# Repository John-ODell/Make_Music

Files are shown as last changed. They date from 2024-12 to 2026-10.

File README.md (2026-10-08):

Making Music with passive Buzzers by John O'Dell
--Update-- 12/4/2024 -> New Synth Update, Scroll Below for instructions. 

Arduino_Scale_Example

Items needed

    - Arduino uno (tested on r4)
    - Raspbery Pi Pico (Test on Pi Pico 2)
    - Passive buzzer module (two preffered and used in sketch)
    - Jumper Wire

Pin Outs

Buzzer 1
    - signal -> Pin 2
    - GND -> GND
    - VCC -> 3.3v

Buzzer 2

    - signal -> Pin 3
    - GND -> GND
    - VCC -> 3.3v

Download the Arduino IDE Platform https://www.arduino.cc/en/software

Open the sketch "arduino_scale_example"

    - Compile and write to your device
    - On Buzzer one C major scale with play with half notes in two onvtices
    - On Buzzer two C major scale will play with Whole notes in two octives

Python Example

Pin Outs

Buzzer 1
    - signal -> Pin 20
    - GND -> GND
    - VCC -> 3.3v

Buzzer 2

    - signal -> Pin 19
    - GND -> GND
    - VCC -> 3.3v

Download the Thonny IDE Platform https://thonny.org/
    
** Follow the Flash Instructions Below To install Micropython onto your Device **

Open the sketch "passive_buzzer_music_test"

    - Press the green arrow
    - On Buzzer one C major scale with play with half notes in two onvtices
    - On Buzzer two C major scale will play with Whole notes in two octives

TROUBLESHOOTING

    - Make sure that your wires are correct for sketch
    - You may get feedback from just signal wires, make sure vcc and ground are in
    - keep to 3.3v on the arduino
    - Some buzzer modules are not good enough quality
    - to increase or quite the noise, change the duty cycle
    - notation is based off 440A and modern tunings. 

** Flashing MicroPython **

    - Open Thonny
    - Navigate to the top left
     - click run
      - configure interpreter 
      - on the bottom right
        - install Micropython
            - Target Volume will be chosen
            - Micrpython Family (RP2 for Raspberry Pi/Your device Family)
            - Variant (Check the Manufacturer)
            - Version, Most recent
            - Install
    - Afer the flash is done exit out of the Interpreter Pages
    - Click on run again
        - Configuer Interpreter
        - "Which Kind of INterpreter should Thonny use"
            - Micropython for your model device (some models will be automatically dedectied)
        - "Port or WebREPL"
            - COMS(number)
            - This number may have changed from when you ran through this the first time.
            - Click Ok
    - On the Thonny home page, Click the Red stop Sign
    - In the Shell below, You will see your device.

---- Pi Pico Synth - 10 Key Bread Board Synth by John O'Dell ----
Updated 12/4/2024

Items needed

    - 10 Touch Input models (feel free to change the inputs, I found touch to be the best for input time, 10 inputs needed)
    - 2 Passive Buzzers (based on how loud you want your Synth to be)
    - Pi Pico 2 with Micropython
    - Thonny IDE
    - ~40 Jumper Wires
    - 2 Breadboards (Recommended for Button Placement but can be done with 1)

This Sketch requires your inputs to be accesseble at all times, please think about how you are wiring so there are not any false inputs.

Pin Outs 

    - All Modules will use a common 3.3v and GND
    - It is easiest to "pick a side" for each module
        - Touch inputs
            - VCC -> 3.3v
            - GND -> GND
            - S -> GPIO 16 - GPIO 22, GPIO 26-28 
                - 10 sequintial pins for easy orginization
        - Passive Buzzers
            - VCC -> 3.3v
            - GND -> GND
            - S -> GPIO 12 - GPIO 13
                - 2 sequintal pins for two buzzers, add more for more sound. I found two is good for personal playing.

Touch Button Example

This example is to make sure your inputs are working

    - open "touch_button.py" and press the green arrow
    - when you press a button in the serial monitor it will return a button has been pressed
    - Change the Pin number in the top the check if all your buttons are working

TROUBLESHOOTING

    - Make Sure you have not switched the VCC and the GND
    - The number is not the pin number but eh GPIO number, refer to the Raspberr Pi Pico pinout sheet

8 Key example

In this example We use 8 touch buttons and turn them into the "White keys" of a piano by assigning them each to a note of the C major scale.
We anchor this tuning based on A4 (fourth octive) at A 440hz. From this we can find the tuning of our different keys. We have a high sample rate for self regulation of Timing rather than a set BPM

    - Open "8_key.py" and press the green arrow
    - starting with the input assigned to GPIO 16, we play a major C scale.
    - In the serial monitor there will be a high refresh rate showing when a button is pressed along with the frequency associated with it

TROUBLESHOOTING

    - make sure you have VCC and GND correct
    - Make sure you are in the Correct GPIO pins
    - if wired in parrallel, there could be a power issue, wiring pin for pin I found has a better sound

--- Pi Pico Synth by John O'Dell ----

This is a mini Synth that has uses 10 touch inputs with passive buzzers to achieve two full ovtives of a piano/synth. 
8 Inputs are assigned the me C major scale, with one Input raising them a half step and another raising them an octive.
This is a fun exmperimental instrument that has a particular 8 bit sound to it.

    - Follow the main wiring diagram 
    - Open "mod_8_key.py" and press the green arrow
        - to play on boot, save the file to the Pi Pico device and name it "boot.py"
            - to get out of a boot cycle, refer to the  **Flashing MicroPython** Section
    
    - Feel Free to change the assigned tones to the keys to make a new set scale.
    - The modulating buttons can be changed as well in their current function, or a totally new one.
    
Practice Song:

    - (refer the the GPIO Pins)
        - |16 18 20|16 18 20|17 19 21|17 19 21|17 19 22|17 19 22|19 21 26|19 21 26|
    - (Refer to the Notes)
        -|C E G| C E G| D F A| D F A| D F B| D F B| E A C| E A C|

## PCB development

The first battery-powered Pico carrier is now an editable, routed KiCad project with removable Pico H sockets, ten touch controls, two buzzer module connectors and GPIO expansion. Electrical/board checks pass; exact-part fit, mechanical CAD and bench validation still hold fabrication. See [hardware/README.md](hardware/README.md) for the project and held review files.

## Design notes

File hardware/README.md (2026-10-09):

# Make Music PCB

The first-prototype project is an editable KiCad10 carrier with protected battery power, removable Pico H sockets, eight notes/two left-hand modifiers, two passive buzzer module connectors and exposed GPIO. The schematic has passed independent ERC/connectivity review. Capacitor/18650 PCB integration has passed all 166 live pad comparisons, with zero copper/layout violations and unrouted connections; four exact metadata warnings remain visible. See current PCB status for the scope and physical edge/fit findings. Exact-part fit and built-hardware tests remain pending; fabrication is held.

Open [kicad/make_music.kicad_pro](kicad/make_music.kicad_pro) in KiCad10. Keep the entire hardware directory so project-local symbols/footprints resolve. The two editable schematic sheets and routed PCB are sources; PDFs/SVGs are review aids.

- [Current PCB status and checks](kicad/PCB_STATUS.md)
- [Selected requirements and GPIO allocation](PCB_DESIGN_NOTES.md)
- [Native schematic and library instructions](kicad/README.md)
- [Held manufacturing/assembly review package](manufacturing/REVIEW_ONLY_DO_NOT_ORDER/README.md)
- [Actual-part measurements still needed](assembly/FIT_CHECKLIST.md)
- [Factory assembly and budget comparison](ASSEMBLY_BUDGET.md)
- [Quote-only request for five complete instruments](assembly/QUOTE_REQUEST.md)
- [Module cable specification](assembly/MODULE_HARNESSES.md)
- [Raised module fixture](mechanical/MODULE_FIXTURE.md) and [wired underside holder cassette](mechanical/WIRED_HOLDER_PROPOSAL.md)
- [Protected power circuit](power/branch-protection.md) and [staged validation procedure](power/prototype-validation.md)

The proposed carrier is330 ×121.5 mm with a removable externally charged protected **18650**. MPD BH-18650-W and its larger lowered cassette/47 mm supports are engineering proposals. Protected-cell fit, connector engagement, module support regions, final mechanical CAD, power/load/thermal behavior and fabricator/assembler acceptance remain required. Five complete instruments plus an optional additional bare keepsake are the selected factory scope. See the fit checklist for precise measurements; use the current held package for review; the old concept sketch is not a manufacturing drawing.

`../Pico_Synth/carrier_prototype.py` provides the carrier pin map, configurable touch polarity and active-low ST0238 idle behavior. It preserves the original firmware; seven host logic tests pass, but no assembled instrument has been tested. Both buzzers play the same pitch, modified by held left semitone/octave controls. Independent voices require a pin/firmware change.

Next: verify actual parts and paper fit, finalize the custom mechanical subassemblies, review the factory quote/assembly process, and bring up one prototype using the current-limited validation procedure. PCB fabrication alone does not supply modules, cables, mechanical assembly, Pico, battery or charger. The published$67.54 setup/stencil example is not a full instrument quote.

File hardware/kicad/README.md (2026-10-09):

# Editable Pico instrument carrier

Open `make_music.kicad_pro` in KiCad 10, then open the schematic. The project-local `MakeMusic.kicad_sym` library and `sym-lib-table` resolve all symbols. `fp-lib-table` registers socket, carrier and power libraries plus installed KiCad 10 `Connector_JST`, `Resistor_SMD`, `Capacitor_SMD` and `TestPoint` libraries. The schematic is the editable source of truth; do not regenerate it from the review PDF.

- `make_music.kicad_sch`: A3 root with two removable female sockets, ten touch/two buzzer cable headers, expansion, two reset pull-ups, twelve 100nF header bypass capacitors and C17/C18 10µF buzzer bulk capacitors.
- `battery_power.kicad_sch`: editable A3 child sheet with JST battery entry, upstream fuse, switch, TPS259474L protection and supporting passives/clamps; VSYS/GND connect through hierarchical ports.
- `make_music.kicad_pcb`: routed 48-part electrical carrier with 17 mounting holes, two ground pours and module/cassette references. C17/C18 and corrected 18650/H1 routing are integrated. Current checks and retained metadata warnings are in [PCB status](PCB_STATUS.md).
- `schematic-review.pdf`: readable two-page A3 schematic export, marked prototype review.
- `pico-socket-map.csv`: all 40 Pico physical pins mapped to local socket pins and carrier nets.
- `verify_connectivity.py`: checks every endpoint in a fresh XML netlist against the reviewed interface contract.
- `carrier-interfaces.md`: exact carrier parts, cable mapping, footprint evidence and placement/release gates.
- `power-integration.md`: native reference mapping, power parts, RPW/fuse/TVS geometry, validation and qualification gates.
- `../reviews/schematic.md`: verified facts, actual checks and unresolved design decisions.

J1 and J2 each use local pad numbers 1-20. J1 pin 1 is at the USB end; J2 pin 1 is at the opposite end. J2 pin 20 is beside USB. J1/J2 are assigned `MakeMusic:Samtec_SSQ-120-01-G-S_1x20_P2.54mm` as candidates. Place J1 pad 1 at USB and rotate J2 180 degrees relative to J1 so J2 pad 20 is at USB. This integration numbering supersedes the mechanical proposal's alternative right-row pad-1-at-USB convention; do not reverse the existing schematic nets to match that proposal.

J3-J14 carrier order is defined as 1=SIG, 2=3V3_OUT, 3=GND. Assigned Harwin headers are cable adapters; actual module pin order is mapped separately by label, and no module mounting geometry is claimed. J15 has the exact Harwin 16-way candidate and defined GPIO order. H1 is the underside JST PH battery harness, circuit1=BAT_PROT_PLUS/circuit2=GND; it does not put holder contacts or holes on the carrier. All **48 schematic physical components** have assigned footprints: **47 purchased parts** plus TP1's 2mm bare copper test pad. J1/J2 now store native SSQ-120-01-G-S MPN and Samtec datasheet fields; supplier BOMs need no socket-identity substitution. See [carrier interface contract](carrier-interfaces.md) for ST0238 cable permutation, reset bias, bulk-capacitor land evidence and local bypass placement. The selected inserted module is original non-wireless RP2040 Pico H SC0917 with fitted male headers; its electronics and the module drivers remain off-board/unmodeled. Cold-fit/engagement checks remain. The updated schematic passes native ERC with zero errors/warnings and the 166-endpoint contract; live PCB pad/identity checks now agree; four custom-field warnings remain reported.

Run from this directory (write generated logs/netlists outside the repository):

```sh
kicad-cli sch erc --severity-all --exit-code-violations --format json -o /tmp/make-music-erc.json make_music.kicad_sch
kicad-cli sch export netlist --format kicadxml -o /tmp/make-music-netlist.xml make_music.kicad_sch
python3 verify_connectivity.py /tmp/make-music-netlist.xml
kicad-cli sch export pdf -o schematic-review.pdf make_music.kicad_sch
```

The user permits firmware adaptation to confirmed touch polarity, including active-low. Confirm direct/momentary configuration and actual idle/touched levels first; the separate carrier_prototype.py firmware supports configurable active levels; no module polarity has been measured.

Revision-1 source path: protected-cell external + -> H1 circuit1 -> F1 -> BAT_FUSED_PLUS -> S1 common2; S1 throw3 -> BAT_SW_PLUS -> U2 IN5; U2 OUT6 -> VSYS/Pico physical39. S1 throw1 is NC (battery OFF). H1 circuit2 joins GND. Carrier series D1 is removed. D2 is a VSYS-to-GND shunt clamp; D3 is the bidirectional input TVS. TP1 only joins USB VBUS/Pico physical40. The Pico's internal USB diode/regulator remain off-board. See [native power integration](power-integration.md) for exact R3–R8/C13–C16 mapping and package evidence.

Battery OFF permits USB power. Remove the cell for external charging; no onboard charger is present. Source changes may reboot: stop playing and let the instrument restart before resuming. No polymer hold-up additions are fitted. Hardware UVLO/overload protection is implemented, while assembly-specific protection response, PCM thresholds, actual cell/holder fit and power/load/thermal validation remain open. Adopted limits are ≤0.70A battery branch, ≤350mA total3V3 including Pico, ≤250mA external3V3 and ≤100µF total VSYS capacitance including Pico. The user corrected the battery format to **18650** on 2026-10-09; the primary power/mechanical review owns updated exact cell/holder/charger choices. R1/R2 bias GP13/12 HIGH while pins are high impedance; firmware must idle HIGH and ST0238 startup/current/PWM still need testing. C1–C12 remain100nF at the carrier headers; native C5/C6 are retained and are unrelated to the removed power-document polymer C5/C6. C17/C18 add 10µF each at J13/J14 on 3V3_OUT; qualify effective capacitance and 3V3 startup/inrush.

The current held package includes C17/C18 and the corrected long18650
cassette/H1 move. Electrical integration and saved/refilled checks agree with
the source-bound exports. Native parity retains four metadata warnings; actual
pad nets, values and full footprint IDs agree. All drawing pages and actual
Gerber/drill whole/detail reviews are recorded. Current findings are in
PCB_STATUS.md. Complete exact-part fit, final mechanical CAD, bench/thermal
qualification and factory acceptance before manufacturing release. See
../assembly/FIT_CHECKLIST.md and ../manufacturing/README.md. The retired
export_review.py refuses to run; native exports use Konnect MCP.

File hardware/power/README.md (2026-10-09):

# Battery and USB power proposal

**2026-10-09 correction:** the user intended **long protected 18650**, superseding the 18350 cell/holder selection. The [current 18650 handoff](18650-handoff.md) recommends exact cell **Keeppower P1835J**, requiring a confirmed opposite-end **button-top** version for mechanical PR #30's **MPD BH-18650-W** holder. External-charger approval remains held pending current-lot voltage/current/termination and fit evidence. Included factory 24 AWG leads need measured insulation OD and qualified JST termination. Mechanical owns physical cassette fit/tolerances; PM completed H1 relocation and reconciled the [main procurement CSV](../assembly/instrument-parts.csv). The power CSV remains a supplementary candidate specification.

The [fuse/eFuse branch](branch-protection.md) is integrated in the routed carrier. The [current rear-edge evidence](../review/rear-edge-20261009/README.md) binds native commit `21b2108`; the [final held export review](../review/manufacturing-20261009/README.md) records package publication at `d987896`. The placement-guard defect from the historical `806457b` review was fixed in merged [PR #33](https://github.com/John-ODell/Make_Music/pull/33); current U2 rotation/C17 displacement controls reject before output creation. Four exact metadata warnings remain. The [bounded review](pr28-power-review.md) distinguishes completed document/export work from remaining physical gates. **No physical parts, fit measurements, bench validation or manufacturing release are available.**

## Recommendation

Implement **A: removable protected conventional 4.2 V-charge 18650 cell, externally charged, switched through the specified fuse/eFuse into Pico VSYS**. The eFuse supplies the battery with reverse-current blocking alongside the Pico's existing USB diode, preserving an unmodified removable original Pico H **SC0917**. Retain 0.70 A battery input, 350 mA total/250 mA external 3V3 and all existing protection values. **B: separate USB charge input + BQ24074 power path + protected cell** remains future research and is omitted from revision 1. The Pico USB port supplies programming/USB power and does not charge the battery.

Updated quote preference (2026-10-08): **five fully assembled instruments**, including populated SMT/THT carriers, harnesses and mechanical work, plus an **optional sixth bare carrier keepsake**. Fit measurements and supplier scope/pricing remain pending; the optional bare board does not replace any of the five assembled units. See the current 18650 handoff for exact remaining holds.

- [Factory assembly and staged prototype validation record](prototype-validation.md)
- [Current protected 18650 parts and integration handoff](18650-handoff.md)
- [Historical PCBWay audit of the 18350 checkpoint](pcbway-readiness.md)
- [Superseded 18350 cell/charger research](rev1-handoff.md)
- [Circuit connections and operating states](circuits.md)
- [Candidate BOM and verification evidence](BOM.md)
- [Historical battery budget comparison and switch research](candidate-comparison.md)
- [Current and runtime worksheet](current-budget.md)
- [Open decisions and integration checks](decisions.md)

## Verified Pico interface

Both non-wireless Pico and Pico 2 documentation specify these **physical header pins**, not GPIO numbers:

| Signal | Physical pin | Carrier use |
|---|---:|---|
| VBUS | 40 | USB voltage/sense only in A; do not join to VSYS or battery |
| VSYS | 39 | Isolated carrier power input, 1.8–5.5 V allowed |
| GND | 38 | Common circuit return; also use other ground pins as appropriate |
| 3V3_EN | 37 | Pull to GND to disable regulator, if full USB-connected instrument-off is required |
| 3V3(OUT) | 36 | Regulated module supply; Raspberry Pi recommends external load below 300 mA, dependent on processor load and VSYS |

USB supplies VSYS through the Pico's onboard D1 Schottky diode. The active U2 eFuse completes the battery OR path; its OUT is VSYS. The earlier carrier series-diode alternative used anode toward the battery and cathode toward VSYS. The higher voltage after its diode drop supplies the instrument; nominal USB wins over a cell. Diodes block ordinary reverse supply current, with finite leakage. The Pico USB port does not charge the cell. Do not connect battery to 3V3, GPIO, or VBUS.

The 1.8 V VSYS capability is a regulator specification, not permission to discharge a Li-ion cell that low. A protected cell and a chosen normal discharge endpoint remain necessary. The identified TTP223 touch IC supports 3.3 V; complete touch-module current/LED behavior and selected SunFounder ST0238 load current remain unverified. See [buzzer evidence](../components/BUZZER_MODULE.md). See the PM's [touch reference](../components/TOUCH_MODULE.md), incorporated from origin/master commit 6a61587.

Evidence: Raspberry Pi [Pico datasheet](https://datasheets.raspberrypi.com/pico/pico-datasheet.pdf), pin descriptions and §§4.4–4.6; [Pico 2 datasheet](https://datasheets.raspberrypi.com/pico/pico-2-datasheet.pdf), pin descriptions and §§5.4–5.6. Both PDFs were downloaded and their relevant sections read. Pico 2 Figures 8–10 were visually inspected. Wireless models are outside this verification.

## What this review establishes

Manufacturer documents support the conventional 1S circuit topology, power pin mapping and identified cell candidate. They do not establish current-lot charging compatibility, holder fit, real current draw, PCB thermal performance, USB compliance or a tested instrument. Source-bound review and the coherent held export package are complete for the stated checkpoint. PM retains release ownership; the physical/process checks in decisions.md and prototype-validation.md remain open, and any later CAD change requires matching evidence and exports.

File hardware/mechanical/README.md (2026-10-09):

# Mechanical fit review and dimensioned proposal

Reviewed 2026-10-08. **Preliminary candidate geometry; not a fabrication release.** Updated 2026-10-09: user corrected the cell to a protected removable **18650**, conventional 4.2 V-charge Li-ion with external charging; earlier 18350 selection is superseded. Owns mechanical documentation and local footprints only. Read together with `../PCB_DESIGN_NOTES.md`. No main schematic, copper routing, module pin order, power circuit, or firmware was changed.

The [2026-10-08 build-readiness audit](BUILD_READINESS.md) assesses the PM-reported J3/J4 move to mechanical y78, C1/C2 spacing, cable height/bends, intentional rear socket overhang, and which exact-part measurements remain necessary. It separates quotation, mechanical manufacture, first powered prototype and later characterization; it does not release the held manufacturing files. The [physical-fit checklist](PHYSICAL_FIT_CHECKLIST.md) covers the selected five fully assembled instruments plus optional sixth bare keepsake. The user can check overall paper fit with a tape; the assembler supplies priced metric part metrology, harness work and acceptance.

**Final review 2026-10-09:** [socket edge recommendation](SOCKET_EDGE_REVIEW.md) replaces the prior overhang acceptance proposal with a rear-only native y20->y18.5 extension, **330 x121.5 mm**, every native placement fixed. Existing service/fixture coordinates keep native offset (20,20), so the new rear is y=-1.5; the physical upper-left is native (20,18.5). [Datums](DATUMS.md) document the optional new-origin conversion without moving parts. [Parameterized cassette interface CAD](CASSETTE_INTERFACES.md) supplies independent nominal backplate/platform geometry; retention, exact fit and manufacturing release remain pending.

## Removable non-wireless Pico carrier

Verified against both user-supplied official local PDFs: original Pico release 21, chapter 2/Figure 3 (printed page 6), and Pico 2 release 5, chapter 3/Figure 3 (printed page 7), both built 2026-07-03. Their mechanical pages were rendered and visually inspected; both agree on the dimensions below. PM selected **Raspberry Pi Pico H SC0917**, the nonwireless RP2040 version with manufacturer-installed male headers, as the first-prototype candidate on 2026-10-08. The official original-Pico ordering table (local release21) identifies SC0917 as Pico H. Physical socket engagement and the assembled header height still require measurement:

| Feature | Drawing dimension, mm |
| --- | --- |
| Pico PCB | 21 wide x 51 long x 1 thick |
| Header rows, center to center | 17.78 |
| Pins per row / pitch / first-to-last span | 20 / 2.54 / 48.26 |
| Row center from side edge | 1.61 |
| Mounting holes | four, diameter 2.1 +/-0.05 |

Use two **Samtec SSQ-120-01-G-S** vertical 1x20 female sockets as the standard-force candidate. **SSQ-120-21-G-S** is the same series' low-insertion-force alternative, subject to configuration availability and a retention trial. Do not use the -03 tail by default: its 10 mm tail unnecessarily projects below the carrier.

Samtec series print revision BH, sheet 1, and catalog F-226 show single-row housing width 2.41 mm (reference), height 8.51 mm (reference), length `N*2.54+0.51` = **51.31 mm**, length tolerance +/-0.25 mm, 0.64 mm square tails, and style -01/-21 tail length 2.64 mm. Catalog insertion depth is **3.68 to 6.35 mm**. Recommended PCB layout revision A, sheet 1, specifies **1.02 mm holes and 1.52 mm pad diameter**, at 2.54 mm pitch. A local single-row footprint captures these dimensions. Body extends 1.525 mm past each end pad center; courtyard adds 0.5 mm, rounded outward. Pad 1 is square. Physical fit of the selected Pico H male headers remains unverified.

Assume a 1.6 mm carrier PCB: nominal unsoldered tail projection is 2.64-1.6 = **1.04 mm**, with solder fillet and tolerances additional. For an example 6.0 mm exposed male post, a 0.5 mm housing gap gives 5.5 mm engagement, inside the catalog range. This is a stack calculation, **not a measured Pico H stack height**. Confirm the supplied Pico/male header has the appropriate square mating post and measured engagement; it must neither bottom out nor float with too little contact overlap. Carrier-to-Pico underside height is 8.51 + socket-to-male-housing gap + male insulator thickness; top component height is additional. Keep the entire Pico underside clear of tall carrier components until that stack is measured.

### Placement and physical numbering

Proposal coordinates retain the legacy service origin native (20,20), viewed from the playing/top side; x right, y toward the front, in mm. Pico USB points toward the rear edge at y=0. Its PCB box is x=109.5..130.5, y=0..51. USB-end pad centers: left J1 pad 1 at (111.11,1.30), right J2 pad 20 at (128.89,1.30). The far-end centers are J1 pad 20 at (111.11,49.56), J2 pad 1 at (128.89,49.56). Rounding of drawing offsets gives y=49.56; use the verified 48.26 mm span, not an assumed symmetric end margin.

Canonical mapping follows the merged schematic's `../kicad/pico-socket-map.csv`: **J1 local n = Pico physical n; J2 local n = Pico physical n+20**. Viewed from the playing/top side with USB up, J1 pad 1 is nearest USB and J2 pad 20 is nearest USB. GPIO numbers are not physical pad numbers. Use the same candidate socket footprint twice: J1 at (111.11,1.30), rotation **0 degrees**; J2 at (128.89,49.56), rotation **180 degrees**, so its pads increase toward USB. Do not place J2 pad 1 at USB. This supersedes the initial mechanical-only reverse-numbering convention; the schematic is canonical and requires no renumbering.

| Socket pad | Pico physical pin / function | Position in top view |
| --- | --- | --- |
| J1.1 / J1.20 | 1 GP0 / 20 GP15 | USB end / far end |
| J2.1 / J2.20 | 21 GP16 / 40 VBUS | far end / USB end |
| J2.19 / J2.16 | 39 VSYS / 36 3V3(OUT) | one / four pitches from USB end |

`socket-placement.csv` records all 40 pad centers, canonical physical pins and carrier nets for integration. The right-footprint square pad-1 marker is at the far end. Check the rotation and complete net mapping in the PCB editor before routing; connecting J2.1 to VBUS would contradict the canonical schematic.

The socket housing starts about legacy y=-0.225. The proposed rear extension to legacy y=-1.5/native y18.5 gives 1.275 mm nominal housing support margin; actual tolerance/flash, finished edge and body seating require process acceptance. See SOCKET_EDGE_REVIEW.md; do not move the assembly to apply this correction. Reserve a **36 x 25 mm external USB cable approach** at x=102..138, y=-25..0 as an assumed cable-shell envelope; measure the actual plug. Keep BOOTSEL accessible through an open lid/service aperture; a provisional 12 x 12 mm access region around (116.5,14) must be adjusted to the selected Pico H's actual button. Leave at least 5 mm side access beyond the Pico and unrestricted upward removal space; trial removal without bending the carrier. USB overhang and plug clearance are separate from the 51 mm PCB dimension.

The reviewed rear courtyard at native y19.27 extends 0.73 mm beyond the old y20 edge and is 0.77 mm inside the proposed y18.5 edge. The fixed nearest socket pad at y21.30 has proposed 2.04 mm copper-to-edge and 2.29 mm finished-hole-to-edge; the 0.25 mm nominal annular ring is unchanged. Samtec supplies no carrier-edge support approval. The final review separates the resolved nominal geometry from actual Pico/cable/finished-part process acceptance; no native outline edit or physical fit pass is claimed by this helper.

## Underside protected 18650 holder

Select **MPD BH-18650-W** as the mechanical candidate. Its [manufacturer drawing revision G, 2024-08-21](https://www.batteryholders.com/uploads/parts/BH-18650-W/datasheets/BH-18650-W-datasheet.pdf) explicitly specifies protected 18650 use and factory 24 AWG leads. The visually reviewed holder body is **77.70 x 20.90 x 21.31 mm**, with general ±0.5 mm decimal tolerance; body planning maximum 78.20 x 21.40 x 21.81. It does not specify a maximum cell length/contact travel or holder ampacity. Exact protected cell and matched external charger selection belongs to the power owner; measure and cold-fit that actual pair, including comfortable removal, wrapper clearance and retention.

The [revised wired cassette](WIRED_HOLDER_PROPOSAL.md) is **112 x 36 x 44 mm**, x145..257/y12..48. The four existing carrier mounts stay at (150,17),(210,17),(150,43),(210,43); a lowered z16 holder platform separates the holder from bolt tips where their plan projections overlap. **Move H1 pad1 from mechanical(229,20) to (269,20), native (249,40) to(289,40)**, same side/rotation/nets; this is a PM proposal, not a helper native edit. New plug reservation x265..275/y15..27 is8 mm beyond the cassette. No Pico, power, GPIO, modifier, note or fixture-mount relocation is requested.

Support proposal is now **≥47 mm below carrier underside**, 3 mm nominal below 44 mm cassette. Final fitted height, lead bends, PH contact insulation compatibility, ribs/overhang strength, cassette door and loaded clearances need assembler metrology/toleranced CAD. All soldering, crimping and mechanical installation remain factory work for five complete instruments. User has tape/no parts; overall paper-fit and reach do not certify connector or cell fit.

Keystone **1044** is an alternative solder-lug 18650 holder whose [manufacturer family](https://beta.keyelco.com/category.cfm/18650-Lithium-Ion-Holders-and-Contacts/For-One-18650-Cell/p/418/id/1198/c_id/686) and catalog p29 describe protected-cell support and tool-free removal. Its catalog body is nominal 77.1 x 20.7 x 18.0; exact lug geometry and delivered-part fit were not verified here. Earlier 1095/1096/1095P/1101 and P1835C2 findings are **historical superseded 18350 research**, retained in [HOLDER_1095P.md](HOLDER_1095P.md). The anonymous 71.12 mm flat-top listing is not selected or substituted for a manufacturer-documented part.

## Arrangement proposal and preserved controls

`placement-proposal.svg` is drawn to a consistent mm coordinate system with dimensions; it is **a reservation plan, not module footprints or an approved board outline**. Candidate board size is **330 x 121.5 mm**, assumed pending actual module measurements and enclosure selection.

Eight front note centers at y=94: x=70,104,138,172,206,240,274,308, in ascending **C4,D4,E4,F4,G4,A4,B4,C5** order. **34 mm center pitch minus 24 mm actual reference body width gives 10 mm clear body-to-body gap**. Eight bodies and seven gaps span `8*24+7*10 = 262 mm`, x=58..320. Dashed 26 x 26 mm reservations add 1 mm on each side of each body, leaving 8 mm between reservations; they do not change the stated 10 mm body gap. Left-hand semitone and octave centers are (24,54) and (24,94), with the same 26 x 26 mm reservations. The actual octave-to-C4 body gap is 22 mm; vertical modifier body gap is 16 mm. Their GPIO baseline remains GP27/GP28; note baseline remains GP16..22/GP26. Increase board size/spacing if actual module body, headers, touch pad, solder tails or finger access exceed these reservations. No module connector pin order is assumed. PM supplied the [HiLetgo reference](http://www.hiletgo.com/ProductDetail/1915450.html), 24 x 24 x 7.2 mm and four M2 holes. These are PM/user-supplied dimensions; hole center spacing, installed header/tail height, and connector orientation/pitch remain unverified. Reservations now accommodate that reference; no module-specific footprint is created. The merged `hardware/components/TOUCH_MODULE.md` was read after fast-forwarding to origin/master 6a61587. The quoted 7.2 mm module height does not include an independently verified carrier mounting gap, pin tail or enclosure clearance; measure the complete assembled stack.

The user requested roughly half to one finger between keys. **10 mm is an initial measurable interpretation, not a verified finger-width or ergonomics claim. A full-size paper fit test is pending.** Print `paper-fit-template.svg` at 100% on A3 landscape or tiled pages (the 330 mm width exceeds Letter/A4 landscape), or draw the 330 x 121.5 mm outline at 1:1; check scale against its 100 mm reference, test the printed note positions and held left modifiers with the intended user's hands. The user has no actual modules; exact metric part measurements remain with the assembler. Check reach, accidental neighbor activation, gaps, mounting screws and plugged expansion wires. Record the result and revise pitch/board size before approving the outline. Eight separate 24 mm touch boards remain provisional until measured; a paper test does not verify capacitive behavior, which still needs a powered prototype.

PM's current carrier handoff places vertical **J15 1x16** at pad1 (50,12), 2.54 mm pitch; last pin y=50.1. Reserve access x=45..58,y=8..55.1, with plug/wire reach verified on the assembly. Expose all 14 unused GPIOs **GP0..GP11, GP14, GP15**, plus 3V3 and GND; the native schematic remains authoritative for pin order. Used pins/test points must not be advertised as free. The [raised module fixture](MODULE_FIXTURE.md) leaves Pico and J15 access open, preserves all ten touch centres, and proposes buzzer centres **(60,67.5)/(98,67.5)** with 32 x 14 bodies and 36 x 23 fixture/hardware envelopes. These body placements are independent of PM's wired buzzer headers (61,49)/(99,49). Current power/switch reservation is x=216..264,y=44..68. No module-specific connector or mounting-hole pattern is inferred. The fixture drawing and attachment CSV record nine independent carrier mounts, z24 spacers/z28 support plane, and factory assembly/fit requirements; module dimensions, bare edge lands, component/header clearances, sensing response and mechanical load remain actual-part gates.

## Assembly and release gates

PCBWay documents through-hole/manual assembly and a quotation form with top/bottom/both-side assembly. This demonstrates a service category, **not acceptance of these particular sockets/holders**. Ask for the selected MPN, bottom-side holder orientation, THT/manual/selective-solder method or SMT retention, sourcing, finished-hole tolerance, solder access and inspection in the assembly quotation. Supply both-side assembly drawings and battery polarity; bare PCB service does not install the holder. Assemble with no cell fitted. Solder sockets aligned using a nonpowered sacrificial mating jig, inspect all joints, then insert Pico; do not solder the Pico into its removable socket.

Before integrated assembly release: verify selected Pico H SC0917 and its actual male-header engagement; trial 40-pin insertion/removal and USB/BOOTSEL access; confirm current holder drawing revision, verify bottom-side flip/polarity mapping and selected-cell fit; measure all ten touch modules and both buzzer modules per instrument; confirm enclosure/door/support load path; integrate power isolation/protection; accept finished holes and edge margins; run integrated ERC/DRC/netlist agreement and inspect both sides. The independent carrier interfaces permit PCB review/quotation while fixture/cassette metrology remains pending. The checklist separates design/manufacturing inputs from acceptance tests that require the first assembled instrument. An unconnected reservation drawing cannot pass manufacturing validation.

## Source register and verification

Primary sources accessed 2026-10-07; copyrighted manufacturer drawings are linked rather than committed.

- [Original Pico datasheet](https://datasheets.raspberrypi.com/pico/pico-datasheet.pdf), chapter 2/Figure 3, and [Pico 2 datasheet](https://datasheets.raspberrypi.com/pico/pico-2-datasheet.pdf), chapter 3/Figure 3: local copies `/Users/johnodell/Desktop/pico_datasheets/RP-008307-DS-2-pico-datasheet.pdf` (release 21) and `/Users/johnodell/Desktop/pico_datasheets/RP-008299-DS-3-pico-2-datasheet.pdf` (release 5), both built 2026-07-03, consulted and mechanically consistent. PM selected Pico H SC0917 for the prototype; the original-Pico ordering table was checked. Wireless variants are not verified here.
- [Samtec exact SSQ-120-01-G-S candidate](https://www.samtec.com/products/ssq-120-01-g-s), [series print revision BH](https://suddendocs.samtec.com/prints/ssq-1xx-xx-xxx-x-xx-xxx-xx-x-mkt.pdf), [recommended PCB layout revision A](https://suddendocs.samtec.com/prints/ssq-1xx-xx-xx-x-xx-xxx-xx-xx.pdf), [catalog F-226](https://suddendocs.samtec.com/catalog_english/ssw_th.pdf): geometry and engagement checked; sourcing remains conditional.
- Historical superseded 18350 evidence: [Keystone primary catalog, printed page 28](https://beta.keyelco.com/userAssets/file/M70p23-33.pdf), [18350 family](https://www.keyelco.com/category.cfm/Holders-Plastic-PCB/18350-Lithium-Ion-Holders-and-Contacts/id/1200), [1095](https://www.keyelco.com/product.cfm/product_id/14033), [1096](https://www.keyelco.com/product.cfm/product_id/14034), [1095 individual PDF endpoint](https://www.keyelco.com/product-pdf.cfm?p=14033): direct download limitation resolved for visual inspection using manufacturer-authored drawing mirrors; [HOLDER_1095P.md](HOLDER_1095P.md) records the individual-source evidence and corrections.
- Historical superseded 18350 evidence: [Keeppower P1835C2 global page](https://www.keeppower.com/product/keeppower-18350-1200mah-protected-li-ion-rechargeable-battery-p1835c2/) and [China page](https://www.keeppower.com.cn/products_detail.php?id=566): conflicting 38.5/39.1 mm lengths recorded in the earlier review; not the current 18650 specification.
- [SunFounder ST0238 product](https://www.sunfounder.com/products/3-3-5v-passive-low-level-trigger-buzzer-alarm-sound-module): selected 32 x 14 mm body per merged component evidence; no header or mounting geometry assumed.
- [PCBWay through-hole assembly](https://www.pcbway.com/pcb_prototype/Through_Hole_Assembly.html), [assembly quotation options](https://www.pcbway.com/quotesmt.aspx): supplier support conditional on quote review.

Current 18650 validation is recorded in [WIRED_HOLDER_PROPOSAL.md](WIRED_HOLDER_PROPOSAL.md). The following is historical socket/18350 validation: local socket footprint exported successfully by KiCad 10 CLI and visually reviewed; pad count, numbering, pitch, span, drills, body and courtyard checked against cited dimensions. Follow-up proposal SVG XML parsed and visually reviewed; 34 mm pitch / 10 mm body gaps and all 40 rotated socket positions were checked against the merged schematic mapping. The erroneous 1095P candidate was withdrawn after source reinspection; the corrected five-hole interpretation and limits are recorded in the holder review. Both updated layout drawings retain nominal body reservations only. Paper fit test remains pending. The native board introduced in merged PR #15 is outside this helper's edit scope. No board DRC, electrical compatibility or physical fit test is claimed for these proposals.

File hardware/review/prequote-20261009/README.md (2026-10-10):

# Final team review for conditional PCBWay quotation

Reviewed October 9, 2026. Accepted for **quotation only**; fabrication remains
held. Native CAD is unchanged from21b2108d8f4a187647004e995a4c40368172f565.
The review began at merged07f0e03; subsequent edits change ordinary quote
documents and one supporting SVG label panel only.

- [Electrical review](electrical/REVIEW.md): fresh saved-file Konnect ERC0,
  layout/copper DRC0 and unconnected0. Exactly four previously reviewed
  custom-field parity warnings remain. No new sync/refill is claimed.
- [Mechanical review](mechanical/audit-summary.json) and
  [resolved label finding](mechanical/label-resolution.json): stale socket
  clearance prose corrected; all non-text geometry unchanged. The mechanical
  helper accepted the corrected readable panel for quote-only use.
- [Power/assembly review](power/REVIEW.md): conditional acceptance with current
  A/B/C scope and refreshed hashes. Its frozen audit describes the earlier
  committed packet; the current audit below verifies the revised packet.
- [Current packet audit](packet/packet-checks.json): all61 input hashes,
  43 support-input hashes,109 outputs,17 native hashes and128 package-local
  links pass. All47 purchased references/235 parts across five,30 SMT/17 THT,
  positions and part identities agree. The audit's historical SMT-only comment
  is superseded by the explicit all47-parts Option B in the current quote.

All17 preserved raw native exports are byte-identical. The coherent managed
packet is in [REVIEW_ONLY_DO_NOT_ORDER](../../manufacturing/REVIEW_ONLY_DO_NOT_ORDER/README.md).
Exact-part measurements, qualified cell/charger pairing, final toleranced
mechanics, factory process/orientation acceptance and first-article/all-five
tests remain production gates. Supplier contact/upload is separately authorized
by the owner for conditional quotation, with no purchase or production release.

The message-center attachment limit requires two ZIPs. Extract both into one
folder; together they contain precisely the110 packet files, without omissions
or changed payloads. Archive hashes and transmission status are recorded in the
[quote status](../../assembly/PCBWAY_QUOTE_STATUS.md).

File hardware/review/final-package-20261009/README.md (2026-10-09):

# Final held package review

The independent `before-corrections-REVIEW.md` audited frozen package commit
d987896 and found three presentation issues: grouped functional labels, copied
relative document links and a prose claim of zero native parity findings.
Its JSON/text companions record that earlier snapshot, not the corrected output.

Root corrected the descriptions by including Value in BOM grouping; bundled
43 support documents/assets and rebased package-local links; retained native
schematic parity4 and separately reported electrical discrepancy0. No native
CAD, Gerber/drill geometry, placement or drawing payload changed.

`corrected-package-checks.json` records the new package's checks:61 durable
input hashes,43 support-input hashes,109 output hashes,128 valid package-local
document links,47 purchased references/235 carrier parts for five instruments,
31 grouped rows and17 unchanged raw export artifacts. The excluded eighteenth
raw file is the generic BOM, intentionally replaced by exact sourcing tables.
All15 placement guard tests pass. A bounded independent follow-up by the
schematic helper (chat01a11931-3d20-7733-8e7e-296b88ba9abd) accepted all three
corrections:31 groups/47 unique references/235 parts,128 existing package-local
links, parity4 versus electrical discrepancy0,17 unchanged native source hashes
and17 unchanged raw manufacturing artifacts. It reported no actionable finding
within that scope and kept every fabrication-release flag false. The helper
performed no CAD/export/repository writes or supplier interaction.

This review permits integration as a held project. It does not qualify actual
part fit, final toleranced mechanical manufacture, cell/charger matching,
factory process acceptance or first-article/all-five powered tests. No price,
supplier contact, upload, order or fabrication release has occurred.

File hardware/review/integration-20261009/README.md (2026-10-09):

# Electrical integration evidence — review hold

Captured 2026-10-09 through Konnect 0.13.0 / KiCad 10.0.6. Native source hashes
in source-checkpoint.json bind this saved-board snapshot. Recreate evidence
after CAD/library changes; do not reuse a stale passing summary.

Run from repository root:

    python3 hardware/kicad/verify_connectivity.py hardware/review/integration-20261009/netlist.xml
    python3 hardware/kicad/verify_board.py hardware/review/integration-20261009

The first checks the independently reviewed circuit/parts contract. The second
compares the fresh native XML with all live IPC pad nets, values and footprint
IDs and a guarded identity-sync noop. It checks source hashes and complete
saved/refilled all-severity ERC/DRC evidence. No pcbnew/SWIG is used.

Observed: 48 electrical parts, 17 mounts, 166 endpoints, 405 trace segments;
ERC 0, copper/layout DRC 0, unconnected 0. Overall DRC remains four warnings:
C17/C18 missing Header and J1/J2 missing MPN in board custom fields. Their
exact references/UUIDs/descriptions are reviewed only for electrical integration.
Native XML holds the correct Header and MPN values; no field is substituted or
removed to silence DRC. Konnect's current sync omits custom field copying.

placement-score-mcp.json reports socket courtyard edge overhang of 0.73 mm.
This remains a physical rear-edge/lip acceptance requirement; no placement
score pass or actual component fit is claimed. Cable connectors are intentionally
internal; aggregate heuristics do not supersede direct circuit/layout checks.

Manufacturing, actual module/cell/holder fit, socket engagement, final mechanical
CAD, supplier process acceptance and current-limited bench tests remain held.
These are design review files, not files to upload or order.

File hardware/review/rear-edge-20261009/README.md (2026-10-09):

# Rear-edge revision — source-bound review hold

Captured 2026-10-09 through Konnect 0.13.0 / KiCad 10.0.6. The source
checkpoint binds the saved final board and local libraries. Earlier
integration-20261009 evidence is historical for checkpoint806457b.

Final native outline is (20,18.5)..(350,140), 330 ×121.5 mm. The service datum
remains native(20,20); mechanical rear y=-1.5. Four exact Edge.Cuts segments
were read back. Nominal socket body rear margin is1.275 mm; courtyard margin
0.77 mm. Actual Pico/socket engagement and handling are unverified.

The first y19 trial produced a silk_edge_clearance warning on J1's pin-1
marker (UUID86a40154-3d14-4646-a9e2-c013985edee5). The retained intermediate
DRC evidence records that finding; the final y18.5 check clears it.

All65 footprint placements/rotations/values/full IDs and405 trace geometries
by UUID remain unchanged from806457b. After editor reload, C17/C18 inactive
chamfer defaults and zero-size SMT drill metadata became explicit; operative
land positions, dimensions, nets and drill size remain unchanged. No full
pad-payload bit-identity is claimed. Mutation/readback MCP records are retained.

Fresh ERC0; saved/refilled all-severity DRC0 copper/layout,0 unconnected and
FOUR metadata warnings: C17/C18 missing Header and J1/J2 missing MPN board
custom fields. No rule or result was suppressed. Native fields are intact.
All166 live IPC pad nets,48 values/full footprint IDs agree with fresh XML;
guarded identity preview is noop. Placement score has zero hard failures;
internal-header edge heuristics do not establish physical defects.

Run from repository root:

    python3 hardware/kicad/verify_connectivity.py hardware/review/rear-edge-20261009/netlist.xml
    python3 hardware/kicad/verify_board.py hardware/review/rear-edge-20261009

Manufacturing, actual module/cell/holder/socket fit, fixture/cassette CAD,
cell/charger matching, assembler processes and current-limited bench tests
remain held. These files do not grant fabrication release.

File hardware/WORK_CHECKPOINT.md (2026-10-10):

# Make Music working checkpoint

## Current checkpoint — quotation sent

October9,2026,8:40:22 p.m. America/Chicago. Root branch
`codex/pcbway-quote-receipt-20261009` starts at PR37 merge
bc986a28121235c059e4859eb6203bb539a0c00a. PR37 integrated quote-packet commit
0d6191a0e0217e7140bbceed22aa4e59db78747e. All17 native hashes/raw exports remain
unchanged. Final team review and hashes are complete; no independent CAD work
remains before external engineering/measurement inputs.

One1759-character conditional RFQ was sent to assigned representative Cici and
verified in PCBWay Message History. Email reply selected. Actual quote pending.
No attachment upload, cart entry/order number, purchase or production release.
The RFQ supplies exact0d6191a GitHub packet/download links, avoiding the browser
file-permission blocker. No Chrome settings change is needed. Do not resend a
duplicate RFQ or treat the calculator's partial137.08USD as an instrument price.
Exact scope/receipt/archive hashes: `assembly/PCBWAY_QUOTE_STATUS.md`.
Local sent proof/text: `output/pcbway-quote-20261009/sent-rfq-confirmation.jpg`
and `sent-rfq.txt`. Keep private account/session/contact data out of GitHub.

External requirements remain exact-part metrology, qualified cell/charger pair,
final toleranced fixtures/cassette, factory process/orientation acceptance,
first-article/all-five tests and separate owner production approval. Five complete
instruments preferred; A/B alternatives/optional sixth bare separately.

All helpers idle. KiCad closed. PCBWay message tab1631995892 is the deliverable;
intermediate quote tab1631995889 closed. Preserve unrelated MOV/history. The app
confirmed that the previous continuation automation no longer exists; its pause
request could not apply. No schedule was recreated. No automatic supplier
follow-up or new design work without actionable inputs. Five-hour reset1791607325;
last usage75% used/25% remaining, weekly97% used, no credits consumed.

## Historical prepared quote checkpoint

October9,2026. Root branch `codex/pcbway-conditional-quote-20261009`, based on
07f0e03b4d69f809a0e0871b89afc9e052754bba. PR36 merged that previous checkpoint.
Native CAD remains21b2108. The owner now explicitly authorizes PCBWay
quote-only uploads/contact after final team review; previous no-upload/no-contact
language below is historical. No purchase or production release is authorized.

Electrical, mechanical and power helpers completed the requested last review.
Fresh saved-file Konnect ERC0/layout DRC0/unconnected0; exactly4 known metadata
warnings retained. Only actionable finding was stale socket-clearance prose in
one ordinary SVG. Root corrected labels; mechanical helper accepted the readable
panel with all non-text geometry unchanged. Durable evidence:
`review/prequote-20261009/`. All helpers are idle. No native edits this turn.

Managed package refreshed coherently:61 input/43 support hashes,109 outputs,
17 native hashes,128 package-local links and47 placements/235 five-unit parts
pass. All17 raw native exports unchanged. Alternative quote scopes now explicitly
cover A5 bare, B5 with all47 parts supplied/soldered, C5 complete instruments,
optional sixth bare. No fifteen-board order. Fit/charger/mechanical/process/test
holds remain exactly as described below and in the current quote request.

The PCBWay calculator returned an incomplete service estimate; Save to Cart
did not create an entry. No cart-based quote submission is claimed. A1950-char
message to assigned representative Cici is prepared, email reply selected.
Two exact ZIPs under1MB each are prepared and byte-verified; filenames/hashes and
scope are in `assembly/PCBWAY_QUOTE_STATUS.md`. Neither attached nor sent yet:
Chrome extension requires “Allow access to file URLs.” User has been asked to
enable it. Do not repeat Save to Cart or send a duplicate RFQ. On permission
completion, upload both ZIPs to the prepared message, verify successful filenames,
send once, and verify an actual sent-message confirmation. Keep receipts local,
account/email/session identifiers out of this public repository.

Latest five-hour usage60% used/40% remaining; weekly94% used. Reset1791607325.
No reset credits consumed. Automation view was requested by its known ID;
its prior local TOML is currently absent, so do not claim a verified local schedule
without checking the app. Pause the existing continuation after confirmed quote
submission; no repeated supplier follow-up is authorized automatically.

KiCad is closed. Preserve unrelated MOV/history. Stable bundled Python remains
the selected runtime. Chrome message tab1631995892; quote tab1631995889.
CUA alert/file picker in background needs foreground activation via native Chrome
when CDP focus times out. Browser file upload requires explicit extension setting;
do not bypass permissions. The former12MB failed call did not execute and was
recovered without deleting project/browser state.

## Historical completed-design checkpoint

Updated 2026-10-09 after final held-package integration.
Root branch: codex/pcbway-prototype-package. Final package commit 2305833d4127fe2808075e858281b6a5a89fc47b merged through PR28 as 4fcd2ca516da457d9ea7e52da39c101ddac27d68 on master; local root fast-forwarded to that merge. Prior af535ce9a10861c251338a6552fdcb82a1200956 is the reviewed PR35 power-document merge.
PR34 merged484b73e on master and was integrated by0fc598b; PR31/32/33 were already merged.
Native CAD remains21b2108d8f4a187647004e995a4c40368172f565. Old package d987896 is superseded by the corrected package accompanying this checkpoint.

PR28:https://github.com/John-ODell/Make_Music/pull/28
Final independent review accepted integration **as a held review project**; PR28 is merged. A later continuation must fetch and verify actual PR/master status rather than repeat completed work. This post-integration checkpoint changes no manufacturing inputs or outputs.

## Completed independent work

Editable native KiCad carrier:330x121.5 mm, outline native(20,18.5)..(350,140), service datum(20,20) retained.65 footprints/405 traces/33vias;48 electrical parts/166 endpoints;38 connected nets and6 NC nets.
Saved/refilled all-severity ERC0, copper/layout DRC0, unconnected0. Native parity is4 reviewed custom-field metadata warnings(C17/C18 Header,J1/J2 MPN); live pad nets, values and full footprint identities have0 discrepancies. Identity synchronization is a no-op. No rules/results suppressed.
Current evidence:review/rear-edge-20261009; older integration evidence is historical.

Current manufacturing/REVIEW_ONLY_DO_NOT_ORDER contains109 hashed outputs plus manifest.61 durable input hashes and43 support-input hashes pass;128 package-local links resolve;47 purchased carrier references,30 top SMT/17 THT,31 functional BOM groups,235 carrier parts across five instruments.
Quote draft/support documents/assets/nominal DXFs/SVGs/paper-fit PDF/provisional firmware are bundled.17 raw export artifacts and17 native hashes are unchanged after ordinary presentation corrections.
All15 placement guard tests pass; wrong nets/new warnings/stale sources,reversed U2 and displaced C17 reject before output. Final audit/follow-up:review/final-package-20261009. No supplier contact or upload.

Actual final Gerber/drill whole registration, enlarged front copper/mask/paste/legend/polarity, all5 native PDF pages and both revised actual-size paper-fit pages were inspected. Placement/aperture/drill inventories agree:97 component PTH+33via hits and17 NPTH3.2mm. Native drawing payloads unchanged by this refresh. See review/manufacturing-20261009. IPC2581 is supplemental; unavailable IPC-D356 is recorded.

## Scope and exact external requirements

Five complete factory-built instruments plus optional sixth bare keepsake: original Pico H SC0917 in female sockets,8 notes+2 left modifiers,2 ST0238,exposed GPIO,protected removable LONG18650/external charging. Screen/keypad/percussion/other Pico variants deferred.
Factory scope includes soldering,crimping,mechanical work,programming,first-article/all-five tests.

1. Exact touch/ST0238 dimensions,header order,thickness,bare support lands,component heights and dressed harnesses; Pico/socket engagement,removal,USB/BOOTSEL access. User has no parts/precision tools; quote assembler metrology. Paper comfort test does not prove part fit.
2. Exact opposite-end-terminal protected P1835J/BH18650W cold fit/retention/contact/lead capability(.70A normal,>=1.2A continuous),AWG24 TR64 OD.8..1.5,qualified JST crimp/tool/strip/polarity/strain relief. Cell/charger pairing held: published L1 upper4.242V versus unqualified P1835J4.20Vmax; documentary voltage/current/termination/temp/bay-fit acceptance needed. One shared charger/input set is only a quote assumption.
3. Final measured/toleranced fixture/cassette/door/feet CAD. Nominal cassette112x36x44,z16 platform,>=47supports,>=2mm actual loaded clearance; keep playing load off cell/holder. Partial underside rule area is not a full enlarged-cassette keepout. Nominal socket body/yard rear margins1.275/.77mm are not measured acceptance.
4. Factory acceptance of U2 mask.10/stencil.100,nominal socket ring.25 versus normal.254,C17/C18 TDK0805 lands,panel rails/fiducials/depanel/THT sequence,both-side access,orientation/polarity preview and scope/itemized price.
5. Qualified first article within the five, then acceptance records for all five. Battery and USB branches need separate power/isolation/inrush/thermal/fault/UVLO tests; effective capacitance,touch polarity/momentary behavior,reset silence,buzzers,current/runtime remain unmeasured.

assembly/QUOTE_REQUEST.md and the package copy are concrete for owner review. Earlier$67.54 was a setup/stencil example, not the project total. No accepted price,physical fit,tested hardware,fabrication release,purchase or upload exists. Independent design work is complete; external gates are next.

## Helpers, usage and automation

Schematic01a11931-3d20-7733-8e7e-296b88ba9abd:final review/bounded follow-up complete,accepted held integration,idle.
Mechanical01a11931-eed2-7820-85eb-496cfc97903b:PR34/final read-only review complete,idle; root corrected stale paper/parity prose.
Power01a11931-cb05-7f20-8e09-075ef0c4c9c1:PR35 reviewed/merged af535ce,complete,idle. Do not restart helpers without actionable inputs.

Latest five-hour check31% used/69% remaining; weekly90% used. Actual five-hour resetsAt1791607325. No reset credits consumed. Same heartbeat resume-make-music-pcb-at-1-am is now PAUSED after verified final integration because only external gates remain. No automatic design work should resume without actionable new inputs or authorization for quote submission.
On future authorized continuation verify actual usage; at<=5% five-hour remaining perform bounded save/checkpoint/push/helper stop/rearm only.

## Tooling and preservation

All native CAD/config/library mutations use Konnect MCP; root sole owner. No pcbnew/SWIG or protected text edits. KiCad/Viewer closed; no CAD mutation in final presentation refresh.
Preserve unrelated ScreenRecording_05-01-2026 09-25-05_1.mov and hardware/kicad/.history.
Stable Python:/Users/johnodell/.cache/codex-runtimes/codex-primary-runtime/dependencies/python/bin/python3.
Raw:/tmp/make-music-pcbway/raw-held-rear-edge-20261009.
Corrected stage:/tmp/make-music-pcbway/final-quote-review-20261009.
Prior package backup:/tmp/make-music-pcbway/previous-d987896-package-20261009.
Before future CUA work restore documentation; getApp after quit reopens apps.

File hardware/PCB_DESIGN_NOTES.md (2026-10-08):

# Make Music — first-prototype design requirements

Updated 2026-10-08. The native two-sheet schematic and routed carrier pass ERC/DRC/parity. Fabrication remains on hold for exact-part fit, final mechanical CAD, bench validation and factory process acceptance. The original firmware is preserved; carrier_prototype.py is a separate tested logic implementation. See kicad/PCB_STATUS.md for actual checks and assembly/FIT_CHECKLIST.md for precise remaining measurements.

## Working configuration

- Two-layer carrier board with a removable original non-wireless RP2040 Pico H SC0917 (selected prototype candidate), plugged into two 1x20 female socket headers at 2.54 mm pitch. The sockets are soldered to the carrier PCB; the Pico has matching male header pins and can be inserted or removed without soldering. Use a Pico supplied with male headers, or fit male headers once to a bare Pico. Confirm socket row spacing, height, pin engagement and USB/BOOTSEL clearance against the selected Pico mechanical drawing before finalizing the footprint. Removal/insertion is done with power disconnected.
- Eight note touch controls and two left-hand modifier touch controls. User permits firmware changes, including adapting input polarity after actual modules are checked. Retain original behavior as the provisional baseline; reprogramming is available for later changes.
- Two SunFounder ST0238 passive low-level-trigger buzzer modules selected by the user for the first prototype. Manufacturer PCB outline: 32 x 14 mm each; see [buzzer module evidence](components/BUZZER_MODULE.md). The first prototype preserves both buzzers at the same pitch; the held left modifiers add a semitone/octave. Independent voices are a future firmware/pin allocation change.
- First revision: removable protected 18350 Li-ion cell, charged in an external charger. User selected this simpler battery architecture on 2026-10-07. Exact cell, matching underside holder and charger remain to be verified; no onboard charger in this revision.
- Power switch and exposed GPIO expansion headers.
- Separate touch and buzzer modules retained for the first revision. The user supplied a HiLetgo TTP223-BA6 touch reference; see [touch module evidence](components/TOUCH_MODULE.md). Actual header orientation, mounting geometry and output configuration remain unverified. Buzzer model is selected; its connector and mounting geometry still need verification.

## Carrier GPIO allocation (preserved baseline)

| Function | GPIO |
|---|---|
| C4 | GP16 |
| D4 | GP17 |
| E4 | GP18 |
| F4 | GP19 |
| G4 | GP20 |
| A4 | GP21 |
| B4 | GP22 |
| C5 | GP26 |
| Semitone up | GP27 |
| Octave up | GP28 |
| Buzzer outputs, same pitch | GP12, GP13 |
| Free expansion | GP0–GP11, GP14, GP15 |

GPIO numbers are not physical header pin numbers. GP12/GP13 share a PWM frequency; independently pitched buzzers require a different allocation (for example GP12/GP14) and a firmware change.

Expose unused GPIOs with labeled 2.54 mm headers, 3V3 and GND. GP0/GP1 can be reserved as an I2C expansion pair. Used signals may have labeled test points, but are shared with onboard circuitry and are not free GPIOs. J15 has GP0–GP11,GP14,GP15,3V3,GND in that order. Its physical pin1 is GP0. No I2C pull-ups are fitted; add compatible bus hardware for a later peripheral.

## Power architecture

Protected removable cell -> H1 -> upstream F1 -> S1 -> reverse-blocking TPS259474L U2 -> Pico VSYS. D2 is a VSYS shunt clamp, D3 a bidirectional input TVS; no carrier series diode. See power/branch-protection.md and kicad/power-integration.md for exact parts/pins/limits.
Pico 3V3(OUT) -> touch modules and compatible buzzer modules, subject to total current budget.

A conventional 3.7 V nominal cell reaches 4.2 V when fully charged. Do not connect raw battery voltage to 3V3 or GPIO. The Pico regulator supplies the regulated 3.3 V rail. USB/battery isolation must prevent USB from feeding the battery through VSYS.

If USB charging is requested, use a single-cell charger with appropriate power-path management, protection, and charge current matched to the selected battery. A Pico USB port does not charge a cell by itself. If removable external charging is selected, retain source isolation for safe USB programming with the battery installed.

Cell/holder dimensions, connector polarity, protection, regulator load budget, and charging method must be confirmed before selecting footprints. An 18350 holder must fit the actual cell, including any extra length from protection circuitry.

Battery runtime requires a measurement of average battery current; do not assume runtime from voltage alone.

## Placement concept

- Front: eight ascending note modules in a row. User requests approximately half-to-one finger of clear space between keys. Start with a proposed 10 mm clear gap between 24 mm module bodies (34 mm center pitch), then validate with a full-size paper fit test. Roughly 330 x 120 mm is a working reservation, not an approved outline.
- Left side: semitone and octave modifiers, positioned for the left hand while the right hand plays notes.
- Rear: USB-accessible Pico, buzzer modules, expansion headers and power switch.
- Battery: wired Keystone1101 solder-lug holder in a separate insulating underside cassette, connected by H1 JST PH. The cassette has independent carrier mounts; no holder-specific holes on this PCB. Protected P1835C2/1101 fit and contact ampacity remain unverified. Proposed >=35 mm underside supports keep playing force off the cell/cassette.
- Seventeen3.2 mm NPTH carrier holes: four corners, four cassette mounts, nine raised module-fixture mounts. These independent interfaces avoid undocumented module/holder hole positions. The raised acetal fixture uses proposed24 mm spacers, a28 mm support plane and24 measured-thickness edge keepers; final fit/CAD/tolerances remain pending.

The accompanying SVG is an arrangement sketch, not a scaled PCB drawing or a copper layout.

## Needed before fabrication release

1. Actual Pico H/socket engagement and USB/BOOTSEL/removal fit; actual touch/buzzer headers, heights and clear support lands.
2. Exact protected P1835C2/1101 fit, contact ampacity and matched external charger qualification.
3. Final paper fit/board size and measured fixture/cassette/feet CAD/tolerances. The proposed330 ×120 mm board is routed but its human/physical fit is untested.
4. Staged source-isolation, low-voltage/fault/current/thermal and functional validation, followed by factory process/quote acceptance. No total assembly quote exists.

These are recorded in assembly/FIT_CHECKLIST.md and power/prototype-validation.md. PM may continue independent layout/review work while actual-part measurements are pending.

## References

- https://datasheets.raspberrypi.com/pico/pico-datasheet.pdf — selected original Pico H, power/pinout/source isolation and mechanical data.
- https://learn.adafruit.com/li-ion-and-lipoly-batteries/voltages — conventional Li-ion cell voltage behavior.

## Manufacturing and assembly

Bare PCB fabrication supplies the board without components. A separate PCB assembly order can include a back-mounted battery holder if the chosen service accepts that part, bottom-side placement, and its through-hole or surface-mount mounting method. Include the exact holder part number in the BOM and clearly specify its side and orientation in assembly documentation. Confirm part sourcing and assembly support before ordering. The battery cell is a separate item unless explicitly included by the supplier.

PCBWay documents both through-hole assembly and top/bottom/both-side assembly options:
- https://www.pcbway.com/pcb_prototype/Through_Hole_Assembly.html
- https://www.pcbway.com/quotesmt.aspx

## Local Pico references

User supplied official datasheets in `/Users/johnodell/Desktop/pico_datasheets/`: original Pico release 21 and Pico 2 release 5, both build date 03/07/2026. The Pico 2 mechanical Figure 3 was rendered and visually checked against socket geometry. PDFs remain outside the repository; manufacturer source URLs above are the portable references. The PM selected original Pico H SC0917 using the original datasheet ordering table. Pico2 is not the fitted prototype candidate; original Pico geometry was checked separately during carrier integration.

## Assembly preference

Prioritize a quote for a factory-populated carrier, including sockets, headers, power components, and battery holder where accepted. Separately quote the named touch/buzzer modules as supplied/sourced subassemblies. Keep Pico insertion and protected 18350 fitting as user steps. See [assembly and budget comparison](ASSEMBLY_BUDGET.md). Build quantity remains pending user input.

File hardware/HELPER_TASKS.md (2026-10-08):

# Helper sessions

All helpers read `hardware/AGENTS.md` and `hardware/PCB_DESIGN_NOTES.md`. Use the assigned worktree and branch. Check scope against the current primary-chat decisions. Do not route a production board or finalize unidentified module footprints.

## 1. Schematic — codex/pcb-schematic

Own `hardware/kicad/` and `hardware/reviews/schematic.md`.

Create an editable KiCad 10 carrier schematic/project for the documented provisional GPIO allocation. Verify Pico physical pin mapping from Raspberry Pi documentation and represent the two removable 1x20 female sockets accurately. Include ten 3-pin touch-module interfaces, two buzzer-module interfaces, and labeled unused GPIO/3V3/GND expansion. Module connector ordering is unconfirmed: clearly mark provisional choices and leave module-specific footprints unassigned until identified. Keep power as clearly labeled interface points for the separate power review; never imply a raw battery-to-3V3 connection. Use local libraries as needed. Export a readable schematic review, run ERC, and document actual findings and unresolved power/module issues. Do not treat passing ERC as proof of component compatibility. Commit, push, open a focused PR, attach it to the helper chat and leave it for primary integration.

## 2. Power — codex/pcb-power

Own `hardware/power/`.

Research and propose battery/USB power for a socketed Pico instrument: protected single-cell conventional Li-ion/LiPo, power switch, source isolation and regulated module power. Compare removable externally charged 18350 versus onboard USB charging with proper power-path management. Verify against primary datasheets. Provide candidate parts with exact MPNs, circuit drawings or editable KiCad sheet where justified, BOM, current-budget worksheet and open decisions. Charging current and physical battery choice must remain conditional until the actual cell is selected. Verify the Pico USB/VSYS interaction and behavior with battery present. Do not edit the main KiCad project. Commit, push, open and attach a focused PR; leave it for primary integration.

## 3. Mechanical and footprints — codex/pcb-mechanical

Own `hardware/mechanical/` and `hardware/libraries/`.

Verify the removable Pico female-socket geometry using official mechanical drawings. Specify exact candidate sockets and inspect available KiCad footprints; create project-local footprints only when needed and include dimensional evidence. Investigate underside PCB-mounted 18350 holder options, protected-cell fit, standoffs, enclosure clearance, and supplier assembly support. Keep all unidentified touch/buzzer module geometry provisional. Preserve eight ascending notes across the front and semitone/octave controls on the left. Provide a dimensioned proposal with explicit assumptions, source links, and fabrication/assembly considerations. No copper routing or edits to the main schematic. Commit, push, open and attach a focused PR; leave it for primary integration.

## Primary integration

Resolve parts and behavior with the user, review helper results, combine the selected power design and verified footprints with the schematic, then commission routing. Verify every used GPIO and power net, current budgets, connector polarity and all mechanical clearances before manufacturing exports. Keep PR descriptions accurate about provisional versus verified work.

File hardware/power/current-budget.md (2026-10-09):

# Current-budget worksheet

Active prototype constraints: **0.70 A normal battery branch; 350 mA total 3V3 including Pico; 250 mA external ceiling; 100 µF total VSYS capacitance.** These are design limits from [branch-protection.md](branch-protection.md), not measured consumption. The active eFuse path replaces the carrier series diode.

**2026-10-09 cell correction:** use the protected **18650 P1835J opposite-end button-top candidate**, mechanical PR #30's **MPD BH-18650-W**, and unresolved lot/charger/holder conditions in [18650-handoff.md](18650-handoff.md). Conventional 1S voltage is unchanged, so all current/protection limits and the 515 mA sizing calculation below remain. Larger capacity does not permit more carrier load. The published 3350 mAh minimum is not usable capacity at our loaded UVLO, and no runtime is inferred from it. MPD's factory leads are 150±5 mm each; [prototype-validation.md](prototype-validation.md#analysis-completed-without-physical-parts) retains a qualified nominal/tolerance wire-loss illustration. Measure the actual conductor/contact/termination path and recalculate if routing changes it.

No component current has been measured. Blank values are **unknown**, not zero. Populate from the actual selected hardware at 3V3 with both buzzers operating, all touch LEDs active, expansion load connected and the intended firmware/clock. Record steady average, startup and coincident peak separately.

| 3V3 load | Quantity | Per-unit average mA | Per-unit peak mA | Evidence / measurement |
|---|---:|---|---|---|
| Pico processor + onboard loads | 1 | TBD | TBD | Selected Pico, clock, code; internal part of regulator load |
| Note touch modules | 8 | TBD | TBD | Exact module + LED state unknown |
| Modifier touch modules | 2 | TBD | TBD | Exact module + LED state unknown |
| Buzzer modules | 2 | TBD | TBD | SunFounder ST0238 selected, 3.3 V supply documented; onboard driver current/peaks unverified |
| Carrier buzzer pull-ups | 2 | TBD | ~0.66 combined | Calculated at nominal 3.3 V with both 10 kΩ pull-ups held LOW; include tolerances |
| Expansion | 1 budget | TBD | TBD | User-specified allowance; do not treat free GPIO as unlimited power |
| Added indicators / other rails | As fitted | TBD | TBD | Include optional indicators and external regulators |

`I_EXT_3V3 = 8*I_NOTE + 2*I_MOD + 2*I_BUZZ + I_EXP + I_BIAS + I_OTHER`

`I_TOTAL_3V3 = I_PICO + I_EXT_3V3`

Use both average and simultaneous peak. Raspberry Pi's recommendation is **less than 300 mA external load** at pin 36, dependent on Pico load and VSYS; it is not an unconditional 300 mA power guarantee. Also check GPIO drive limits separately; power budget does not approve direct buzzer drive or 5 V logic.

Approximate battery-only estimates for the selected fuse/eFuse path (not measured runtime):

- `P_3V3 = 3.3 * I_TOTAL_3V3` with currents in A.
- `V_U2_IN = V_CELL - V_FUSE - I_BAT*R_SWITCH_HOLDER_HARNESS_INPUT_COPPER`.
- `V_SYS_A = V_U2_IN - I_BAT*R_U2_ON - V_OUT_TO_PICO_DROP`. The active carrier has no series D_EXT; measure fuse/contact/copper drops. F1's typical drop is not a maximum resistance specification.
- For future option B, calculate `V_SYS_B` from the charger OUT voltage and that option's actual switch/isolation drops, including U1's battery-path drop at applicable current. Do not assume the selected A path also applies to B.
- `I_BAT ≈ P_3V3 / (eta_PICO * V_SYS) + I_CHARGER_IDLE + I_OTHER_BAT`. Use measured conversion efficiency at low cell voltage; do not assume it is unity or add measured whole-system input and internal Pico current twice.
- `runtime_h ≈ usable_capacity_Ah / measured_average_battery_A`. Capacity depends on endpoint, temperature, aging and load; estimate from the selected cell's discharge curve and verify by test.

At the [branch contract's](branch-protection.md) conservative calculated 2.992 V at VSYS, 350 mA total 3V3 and assumed 75% efficiency require approximately **515 mA** battery current before input-side leakage. This leaves about 185 mA against the 0.70 A branch ceiling, subject to actual efficiency, losses and startup. It is a sizing calculation, not measured headroom.

The carrier's two 10 kΩ buzzer pull-ups add at most approximately **0.66 mA** at 3.3 V when both signals are LOW; include that load separately from the modules. Available expansion current is therefore `min(250, 350-I_PICO) - 10*I_TOUCH - 2*I_BUZZ - I_BIAS - I_OTHER`, all in mA, using simultaneous measured peaks. The 250 mA external allowance leaves 100 mA for Pico only if its measured load stays within that allocation.

**Allocation example, not consumption data:** reserving 70 mA for ten touch boards, 50 mA expansion and 0.66 mA pull-up load leaves 129.34 mA for the two buzzers, or 64.67 mA each with no remaining external margin. Allocating 60 mA per buzzer instead leaves only 9.34 mA external margin. The touch allocation is not a published module maximum, and SunFounder publishes no ST0238 module-current bound. These examples show which measurements can invalidate the budget; they do not qualify the instrument.

The [Tontek TTP223-BA6 datasheet](https://www.tontek.com.tw/uploads/product/243/TTP223-BA6_V2.1_EN.pdf) supports 2.0–5.5 V IC supply. Its no-load low-power current at 3 V is 1.5 µA typical / 3 µA maximum; these values exclude the module indicator LED and output load and must not be used as the module budget. Its application circuit requires 100 nF between VDD/VSS with very short traces. Confirm that capacitor on each actual module: a carrier capacitor before a 100 mm cable does not meet that placement instruction. Test false touches during USB/battery changes, as the datasheet warns about rapidly shifting supplies.

Pico already has regulator output bulk capacitance; the [historical readiness audit](pcbway-readiness.md#bulk-capacitance-and-review-heuristics) recommended two additional 10 µF capacitors at the buzzer supply headers. Merged schematic PR #27 added C17/C18; root PR #28's placement/routing and source-bound electrical evidence were verified at `806457b` in [the bounded review](pr28-power-review.md). Transient margin remains unmeasured. Their 20 µF nominal total is on 3V3_OUT, not directly on VSYS, but still contributes to regulator startup demand. Measure module-end 3V3/GND during simultaneous buzzer edges and touch LED transitions, and include startup in source-current tests.

## USB and future-option charging budget

Revision 1 has no carrier charger. USB alone can power the whole instrument with S1 OFF and bypasses the battery eFuse. Qualify Pico plus all module startup/steady current against the selected USB source, including host connection/boot states; a passing battery-current test does not qualify USB consumption. The charging calculations below apply only to future option B.

For B's dedicated charge input, U1 IN current includes its OUT load plus charging and internal consumption. In the selected linear charger, charge current is not transformed by an efficiency ratio as in a buck charger. Reserve headroom for status LEDs/other input-side circuits. Default USB100 limits U1 IN to at most 100 mA, with OUT load prioritized and battery supplement possible. A larger ISET target does not override this limit; charging may be slow or suspended while playing.

For the unresolved single Pico-port alternative:

`I_USB_TOTAL = I_PICO_USB_BRANCH + I_CHARGER_IN + I_OTHER_VBUS`

U1's input limit only constrains its own branch. Measure and enforce the aggregate under USB connection, enumeration, suspend, bootloader and charger startup. The optional dedicated charge port does not limit current drawn from a separate Pico programming port; that port also needs its own reviewed module/Pico USB budget.

Record charger worst-case heat at low V_BAT/high V_IN, enclosure temperature, switch/diode temperatures, 3V3 minimum during hot-plug and buzzing, and ripple affecting touch detection. Off current must be measured with switch off, with/without USB, and with the optional charger populated. A BQ-connected cell is not electrically disconnected by S1 after OUT.

The historical [comparison](candidate-comparison.md) used a provisional 1 A input allowance. The active normal branch ceiling is **0.70 A**, with the selected NKK switch and fuse/eFuse in branch-protection.md. See [current 18650 qualification](18650-handoff.md) and the [completed held export review](../review/manufacturing-20261009/README.md). Physical fit, factory process/release acceptance and bench results remain outstanding; the explicitly dated [historical package audit](pcbway-readiness.md) is not current package evidence.

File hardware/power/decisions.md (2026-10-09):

# PM decisions and integration handoff

**2026-10-09 update:** [Current protected 18650 handoff](18650-handoff.md) supersedes the 18350/P1835C2/1101 selection. Keep the integrated [fuse/eFuse branch contract](branch-protection.md), voltage thresholds and current limits. Five complete instruments plus an optional sixth bare carrier remain the quote scope. Current source-bound review and held exports are complete at native `21b2108` /package `d987896`; current-lot cell/charger compatibility, holder/cassette fit, factory acceptance and bench tests remain open.

The [factory assembly and current-limited bring-up record](prototype-validation.md) provides staged tests and a blank measurement table. No bench results are available; qualify reset dwell, 1S fault response and source isolation on the actual assembly.

## Selected architecture and remaining decisions

User corrected the intended cell to long **protected 18650**. Option A remains removable external charging; option B is not populated. Recommend **Keeppower P1835J**, standard opposite-end-terminal **button-top** version, pending delivered-lot/terminal confirmation for **MPD BH-18650-W**. **L1 charger approval is held** because its published voltage tolerance exceeds the cell page's unqualified maximum; a 500 mA qualification setting does not resolve that gap.

| Decision | Recommended starting point | Release dependency |
|---|---|---|
| Charging | A external charging selected | Verify compatible external charger; no onboard charger in revision 1 |
| Battery form | Protected 18650; Keeppower P1835J opposite-end button-top review candidate | Confirm delivered terminal version, current-lot charge/discharge limits, PCM/recovery and actual fit |
| Pico | Original non-wireless Pico H SC0917, removable in female sockets | Actual engagement/USB access and regulator/current validation |
| Holder/connector | Mechanical PR #30 selects MPD BH-18650-W with included 24 AWG leads; retain JST-PH H1.1+/2GND | Exact-cell fit/contact travel/removal/ampacity; lead OD 0.8–1.5 mm and qualified crimp process; actual harness polarity |
| Cassette / H1 | Mechanical PR #30 proposes 112×36×44 mm cassette/≥47 mm supports; H1 move/routing retained in current held exports | Final loaded fit/toleranced CAD; four custom-field warnings remain visible |
| Instrument parts CSV | PM-owned [main table](../assembly/instrument-parts.csv) includes button-top cell, included leads and charger-input accessory | Current rows preserve five-unit quantities; one shared charger/input set is a quote assumption, HOLD pending accepted pairing/distribution |
| Switch behavior | Battery branch OFF; USB remains on | Preserve adopted behavior and qualify actual startup/current/low-load switching |
| Switch low-load endurance | MN12SS1W03 silver contacts retained | NKK recommends 0.1 A at 2 V minimum; actual idle/startup current and low-load contact endurance remain unverified. Gold logic contacts cannot carry the 0.70 A branch. See prototype-validation.md. |
| Isolation/protection | TPS259474LRPWR + 1.25 A upstream fuse integrated; all 41 power endpoints verified in recorded evidence | Validate current/reversal/transients on assembled circuit; USB bypasses this branch and needs separate source/inrush qualification |
| Onboard USB charging | Deferred to a future revision | B is research only; omit charger IC, charging receptacle and related circuitry from revision 1 |
| Charge/input/termination/timer settings | Not applicable to carrier revision 1 | Verify external charger against selected cell limits |
| Module supply and buzzers | Pico 3V3 for compatible modules | TTP223 touch supply supports 3.3 V per merged PM reference; measure full module LED loads, confirm polarity; SunFounder ST0238 selected at 3.3 V; driver/load current and peaks still unverified |
| Low battery shutdown | Hardware UVLO nominal 3.221 V off /3.546 V restart | Adopted in branch-protection.md with tolerances; no firmware ADC changes |
| Added buzzer bulk | C17/C18, 10 µF each on 3V3_OUT, retained in current source-bound electrical evidence and held package | Assembly process, effective capacitance and measured startup/transients |
| Manufacturing placement guard | Merged PR #33 guards every placement before output; final U2 rotation/C17 displacement controls reject | Closed for current checkpoint; revalidate matching source/evidence/exports if CAD changes; physical orientation/process acceptance remains open |
| Factory scope | Five fully assembled instruments; optional sixth bare keepsake | Accepted complete SMT/THT/harness/mechanical scope and per-unit records; no actual parts for fit metrology yet |

## Schematic integration instructions

A/B are alternatives, not two battery paths to populate simultaneously. The selected isolated output goes to physical VSYS pin 39; GND uses pin 38 and the ground net. The carrier must not short VBUS pin 40 to VSYS. Module power is pin 36. Only connect a switch to pin 37 if the agreed OFF behavior needs regulator disable. Show existing Pico D1 explicitly in the review, even though it is inside the removable module.

For the selected A require protected-cell/pack terminals, F1, S1 and U2 with the support parts in branch-protection.md; U2 OUT connects directly to VSYS and the former series D_EXT is removed. D2 is a shunt clamp, cathode to VSYS. For future B add U1, dedicated charge input and cell temperature sensing as circuits.md specifies; protected battery output is connected to BAT, OUT passes through S1/D_EXT. Do not make an unreviewed connector-pin-order choice. Footprints for diode/IC/switch must be checked against mechanical drawings during integration, and unresolved components must remain unassigned.

## Historical proposal validation (2026-10-07)

- Read power assignment and checked the primary chat's current requirements; used existing supplied power worktree on codex/pcb-power.
- Fetched origin; checked clean assigned worktree and compared guidance to origin/master.
- Downloaded original Pico/Pico 2 and BQ24074 PDFs; read power pin descriptions, source-ORing examples, charger pin mapping/programming, input-current and thermal tables. Visually inspected Pico 2 Figures 8–10.
- Read Vishay SS14 and C&K JS manufacturer ratings/order drawings, and both Keeppower candidate pages; documented their dimensional conflict.
- Reviewed all source states against drawn diode direction and existing Pico D1; calculation spot checks are in current-budget.md.
- Ran git diff --check and inspected the scoped diff before commit. No simulation, ERC, DRC, physical-cell measurement, thermal test or prototype test is claimed.

## Checks required after selection and integration

For revision 1, apply battery/USB and external-charger checks below; onboard charger, NTC, dedicated charge USB, timer and thermal-pad checks apply only to future option B.

The earlier [checkpoint audit](pcbway-readiness.md) does not cover the corrected cell/holder or later header/bulk changes. Use the [current rear-edge evidence](../review/rear-edge-20261009/README.md) and [final held export review](../review/manufacturing-20261009/README.md); regenerate matching evidence/exports if CAD changes. No physical results are available; current source research and qualified calculations are in [18650-handoff.md](18650-handoff.md).

1. Review connector/holder polarity, Pico power pin numbers, diode cathode, protected-pack return, charger pin mapping and all populated configuration resistors. Review USB source budget and cell/NTC/timer settings before enabling charging.
2. Complete electrical current worksheet. Check switched input/inrush against S1 rating, regulator and GPIO limits, diode voltage/heat/leakage, fuse/wiring fault coordination if required by the selected assembly, and charger thermal layout.
3. Run integrated ERC/DRC and netlist-to-PCB checks, document intentional exceptions, visually review layout, USB/BOOTSEL access, thermal pad and cell clearances. Review assembly services and actual part availability.
4. Prototype with current-limited supplies before fitting the battery. Exercise battery-only, each USB-only state, both USB inputs (B), removal/insertion, switch-off, load steps and low-voltage behavior. Measure 3V3/VSYS transients and check reverse currents into each supply, including diode leakage. Confirm no unexpected charge via the Pico USB port.
5. With the selected protected cell and charger settings, test valid charge, termination under changing load, cell-temperature suspension, protection recovery and enclosure temperature. Do not perform destructive short-circuit testing on a live cell; review protection documentation and validate fault behavior with suitable controlled equipment.
6. Measure real average battery current and discharge behavior before making runtime claims. PM integrates and merges the helper PR; this helper does not merge it.

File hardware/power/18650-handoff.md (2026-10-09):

# Current revision 1 power handoff — protected 18650

Updated **2026-10-09 America/Chicago**, including an independent evidence review of root [PR #28](https://github.com/John-ODell/Make_Music/pull/28) at `806457b`, following mechanical [PR #30](https://github.com/John-ODell/Make_Music/pull/30). The user corrected the intended cell to **long 18650**; this supersedes the 18350/P1835C2/Keystone 1101 selection. Continue removable conventional **1S 4.2 V-charge Li-ion with external charging**, F1/S1/TPS259474L protection and unmodified Pico H SC0917. No onboard charger. **Five fully assembled instruments**, plus an optional sixth bare carrier keepsake, remain the quote scope. No physical parts, fit measurements, bench results or manufacturing release are available.

## Exact cell recommendation and evidence limits

Recommend **Keeppower P1835J**, the standard protected 18650 product identified by the [manufacturer's standard product page](https://www.keeppower.com.cn/products_detail.php?id=510), with conventional positive/negative ends and a **positive button top required by the selected MPD holder**. The [global product page](https://www.keeppower.com/product/keeppower-18650-3500mah-protected-li-ion-rechargeable-battery-3-7v-p1835j/) corroborates the model; it also lists customizable terminal forms. Confirm that the delivered lot is this button-top, opposite-end configuration; SKU alone does not establish it. Published standard-product dimensions below are a planning envelope, not proof of the delivered terminal variant's fit.

| Property | Published evidence | Use in this design |
|---|---|---|
| Chemistry/voltage | Protected Li-ion, nominal 3.7 V; 4.20 V maximum and 2.5 V cutoff | Existing 1S voltage architecture applies; no raw cell to 3V3/GPIO/VBUS |
| Capacity | 3500 mAh typical, 3350 mAh minimum | Capacity planning only; usable capacity at our loaded UVLO is unmeasured |
| Standard product size | Diameter 18.6 mm, length 69.1 mm, ±0.2 mm | Reserve at least **18.8 mm diameter ×69.3 mm length**, then add measured contact travel, insertion and insulation clearance |
| Protection | Advertised overcharge/discharge/current/short protection | PCM thresholds, delay, leakage, recovery and fault coordination are not specified by those feature labels |
| Temperatures | Charge 0–45°C; discharge −10–60°C | Retain the instrument's narrower 0–40°C ambient limit; cell temperature still needs control during external charging |
| Current data | [Manufacturer catalogue, February 2016, PDF page 3](https://www.keeppower.com.cn/UploadFiles/20160227155232.pdf): P1835J standard charge 1 A, maximum discharge 8 A | Historical model evidence only. Current pages omit numeric charge/discharge limits; obtain current-lot ratings before approving operation or charging |

The manufacturer also sells a [P1835J with both polarities at the positive end](https://www.keeppower.com.cn/products_detail.php?id=677). That is a different terminal arrangement and is not the conventional two-end candidate above; SKU alone does not close the procurement specification. Do not infer the underlying bare cell or its limits from “made in Japan.” **P1835R is a different model**, [withdrawn/recalled by Keeppower](https://keeppower.com.cn/news_detail.php?id=111); it is not an alternate part for this handoff.

## External charger — compatibility HOLD

Exact evaluation target **Keeppower L1**, initially **500 mA** as an engineering qualification setting, remains offboard equipment. The [current manufacturer page](https://www.keeppower.com/product/intelligent-li-ion-rechargeable-battery-charger-l1-with-lcd-display/) and [manufacturer-authored manual V1.0](https://www.tme.eu/Document/f545a63a03e51e3b3ea513f2f0317887/L1_KeepPower_EN.pdf) list 18650 support, 5 V/1 A input and selectable 500/1000 mA, with **4.2 V±1%** output. The manual recommends 1 A for the generic 18650 size; this does not approve that current for the delivered P1835J lot. Do not carry over the old P1835C2 770 mA/24 mA test-report limits to P1835J.

Calculated L1 voltage range is **4.158–4.242 V**. The current P1835J pages state an unqualified **4.20 V maximum**, with no accepted positive tolerance. Therefore **no approved cell/charger pair is established**. Confirm a current-lot CC/CV voltage tolerance, maximum charge current, termination criterion and permitted temperature range; match measured charger limits/revision/current tolerance, cell-temperature handling, PCM recovery and usable bay travel to that specification. A 500 mA selection alone does not resolve voltage or termination. Include a suitable separate 5 V input supply/cable in the eventual charger quote. Quantity/accessory distribution is a PM order decision. Charger purchasing/use remains held while compatibility is unresolved.

## Carrier and mechanical handoff

Keep the [branch contract](branch-protection.md) and [41-endpoint CSV](branch-endpoints.csv): H1.1 positive → F1 **3403.0275.23** → S1 common2/ON3 **MN12SS1W03** → U2 IN5 **TPS259474LRPWR**; OUT6 → Pico VSYS39. H1.2 is GND. Pico VBUS40 and 3V3 pin36 remain distinct; onboard USB D1 stays. USB powers the instrument with S1 OFF and does not charge the cell. Battery eFuse protection does not limit the USB branch.

Mechanical PR #30 selects **MPD BH-18650-W** and a longer insulating cassette. [MPD's product page](https://www.batteryholders.com/part.php?original=Li-ion+18650&override=Li-ion+18650&pn=BH-18650-W) explicitly requires a protected **button-top** 18650. Its [revision G drawing, 2024-08-21](https://www.batteryholders.com/uploads/parts/BH-18650-W/datasheets/BH-18650-W-datasheet.pdf), rendered and visually checked, specifies factory **24 AWG TR64, 300 V/80°C wires**, **150±5 mm each**, with **5±1 mm stripped ends**. Use this drawing dimension rather than the older “6-inch” description. Body 77.70×20.90×21.31 mm does not specify maximum cell size/contact travel or fitted height. Exact P1835J cold fit, removal, retention and contact ampacity remain unqualified. The old 1101 and anonymous flat-top holder are superseded; another BH-18650 suffix is not an approved substitution.

Retain the factory-assembled JST-PH **B2B-PH-K-S(LF)(SN)** / **PHR-2** / **SPH-002T-P0.5S** interface. [JST's PH datasheet](https://www.jst-mfg.com/product/pdf/eng/ePH.pdf) gives that contact AWG30–24 and insulation OD **0.8–1.5 mm**, with a series 2 A rating at AWG24. MPD does not publish the lead insulation OD or crimp qualification. Measure OD and qualify the exact contact/tool/strip/crimp process; the supplied 5±1 mm stripped end is not a JST instruction. Reprepare/trim leads through the accepted factory process, keeping service slack, insulation and independent strain relief. Factory-installed leads replace assembler soldering to holder lugs. Trace actual positive contact to H1.1 and negative to H1.2 with no cell; wire color does not establish polarity. Qualify the holder for 0.70 A normal and at least 1.2 A continuous branch capability; JST ratings do not establish holder ratings. Unfused leads still depend on cell protection.

Mechanical PR #30 proposes a **112×36×44 mm cassette** and **≥47 mm underside supports** while retaining the four carrier mounts. Root PR #28 at `806457b` has completed H1's native **(249,40)→(289,40)** relocation/routing, verified by exported IPC position/pad-net readback and source-bound DRC. Cassette geometry remains a proposal with no physical fit or final machining result. PM owns final matching exports and disposition of the four exact custom-field warnings; mechanical owns cassette/platform/door/fastener tolerances and loaded clearance. Apply the [mechanical proposal](../mechanical/WIRED_HOLDER_PROPOSAL.md) from PR #30, and the [bounded root review](pr28-power-review.md), during integration.

The ready-to-reconcile [instrument procurement rows](instrument-parts-handoff.csv) now match **root PR #28's seven-column schema**, including quantity for five instruments. PM owns `hardware/assembly/instrument-parts.csv`: replace its Holder, Battery plug housing, Battery contacts, Battery leads, Cassette, Cell and External charger rows, then add the Charger input supply/cable row. Preserve unrelated rows and five-unit quantities. Included holder leads have **zero additional-wire purchasing quantity**, represented as included material rather than another purchase. Root already replaced the superseded separate battery-wire row with included factory leads; retain that improvement. Cassette geometry comes from mechanical PR #30; charger/accessory quantities remain PM decisions. Apply after the root table schema is integrated; do not copy these rows into the older six-column table.

A dry-run reconciliation against root's main CSV at `806457b` preserves all 20 unrelated rows and produces 28 data rows including the new accessory. This handoff CSV has seven fields per row and retains unresolved charger quantities as text rather than inventing counts. The important additions to root's existing lead specification are the required **button-top cell configuration** and the **charger input supply/cable** line.

All five units need small SMT/THT parts, sockets, headers, switch, harnesses, module installation and accepted mechanical work in the assembly quote. Each gets its own inspection/bring-up record. The optional bare board gets no populated-part allocation. Cell/charger fitting and supply must follow the accepted cold-fit and cell-release procedure; supplier exclusions must be explicit.

## Current, capacitance and qualification

Retain **≤0.70 A battery input**, **≤350 mA total 3V3**, **≤250 mA external 3V3**, **≤100 µF total VSYS**, nominal **1.004 A** fault threshold and nominal **3.221 V falling /3.546 V restart at U2 IN**. A larger capacity cell does not authorize higher carrier current, different protection values or more expansion load.

At the existing calculated low-end **2.992 V VSYS**, 350 mA at 3.3 V with assumed 75% regulator efficiency still needs **0.515 A**, leaving approximately 0.185 A below the battery design ceiling before leakage/startup/loss uncertainty. These are sizing assumptions, not measurements. At 0.70 A, the existing U2 45 mΩ conduction model remains **31.5 mV/22.1 mW**; fuse/contact/harness loss and thermal behavior must be measured with the new assembly. The 150 mm factory lead pair retains the earlier 0.30 m nominal wire-length model; its ±5 mm tolerance and unknown actual conductor/contact resistance require the [qualified loss illustration](prototype-validation.md#analysis-completed-without-physical-parts) and measured result. Greater energy/capacity does not establish fuse/PCM clearing or safe fault behavior.

The [official Pico Rev3 schematic](https://datasheets.raspberrypi.com/pico/pico-datasheet.pdf), Figure 19, shows **47 µF at regulator input VSYS** and a separate **47 µF at output 3V3**. Pico's VSYS capacitor shares U2's output node with C14/C16 (9.4 µF nominal): the main VSYS-capacitor subtotal is **56.4 µF nominal**, before other final additions, within the 100 µF ceiling. U2's input C13 is on BAT_SW_PLUS. Check every final VSYS-connected capacitance and effective values; this subtotal is not a bias/startup measurement.

Merged [schematic PR #27](https://github.com/John-ODell/Make_Music/pull/27) added native **C17/C18, 10 µF each at the buzzer supplies**, candidate **C2012X7R1A106K125AC**, on **3V3_OUT**. Root PR #28 at `806457b` places/routes them and its source-bound evidence agrees for all **166 endpoints /48 electrical parts**. Observed ERC is zero, copper/layout DRC and unconnected counts are zero, and **four exact metadata warnings remain**; overall DRC is not zero. Their additional 20 µF does not add directly to the VSYS total; it still increases regulator startup demand. Final manufacturing outputs, the placement guard correction in [pr28-power-review.md](pr28-power-review.md), and physical/startup/transient qualification remain open. The [2026-10-08 audit](pcbway-readiness.md) records only its original 18350 checkpoint.

Required evidence remains: delivered-cell/charger limits and terminal identity; actual holder/cassette/socket/module fit; final mechanical CAD and factory process/placement approval; effective capacitance; measured module currents and simultaneous buzzer/touch transients; USB isolation/source budget; 1S UVLO/fault/latch/reset/reversal/thermal checks. Use [prototype-validation.md](prototype-validation.md) before fitting a real cell. No live-cell short test or runtime claim follows from this paper review.

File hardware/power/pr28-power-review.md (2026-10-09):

# Bounded independent power and packaging review

Reviewed **2026-10-09 America/Chicago**, root [PR #28](https://github.com/John-ODell/Make_Music/pull/28) commit **806457bb189214c41c3d3b49db4457fc497c4590**. Read exported XML/JSON/CSV and ordinary Python guard code only. No CAD mutation, editor operation, new ERC/DRC execution, supplier contact or root-file write occurred. Physical release remains **INCOMPLETE**.

## Material defect: placement coordinates and rotations are not fully guarded

`hardware/manufacturing/prepare_pcbway_review.py`, lines110–123 at the reviewed commit, checks each exported reference/value/package/side but copies X/Y/rotation unchanged. It checks coordinates only for J3/J4/H1 and no rotations. `verify_board.py` checks live pad nets, values and footprint IDs; it does not validate the native position export.

**Reproduced:** copied `/tmp/make-music-pcbway/raw-held-20261009` into an isolated temporary directory, changed only U2's `positions.csv` rotation **0→180°**, then called the actual `prepare()` with the unchanged current XML/ERC/DRC/source snapshot/electrical evidence. It completed: **47 parts /30 SMT /17 THT /38 held files**, with U2 **180°** in `pcbway-centroid-smt.csv`. Temporary negative-control outputs were removed. This can produce a wrong assembly instruction while all electrical/source checks still pass. The actual unmodified export independently agrees with all47 live X/Y/rotations; no current misplaced U2 is alleged.

**PM fix before accepting the final package:** compare every exported placement with the source-bound IPC inventory: X, negated Y for the documented native origin, rotation modulo360, side and exact identity. Require finite coordinates/angles and suitable export-precision tolerance. Do this before `copytree` or output creation. Add a U2-rotation refusal test and a non-anchor coordinate refusal test, preserving the existing wrong-net/warning/stale-source cases. Native Gerber/drill viewing and polarity/rotation inspection remain separate requirements.

## Procurement and requirements reconciliation

Root's `hardware/assembly/instrument-parts.csv`, lines5–8, already includes the **MPD factory 150±5 mm AWG24 leads**, OD/crimp qualification and no duplicate wire purchase. Preserve that scope. It now has **seven columns**, with five-unit quantities; the earlier six-column power supplement must not be applied unchanged.

Root's cell row at line18 specifies opposite-end terminals but omits the **positive button top** required by [MPD's exact product page](https://www.batteryholders.com/part.php?original=Li-ion+18650&override=Li-ion+18650&pn=BH-18650-W). Neither a P1835J SKU nor its customizable terminal list establishes the delivered version. The table also has no charger input supply/cable row despite the L1's specified5 V/1 A input. [The revised seven-column supplement](instrument-parts-handoff.csv) closes those procurement-document gaps for PM integration, preserving20 unrelated rows and producing28 data rows. Charger/accessory distribution remains a PM decision; compatibility remains held.

Root's instruction-authoritative `hardware/PCB_DESIGN_NOTES.md` is stale at lines10/44/53/61/86: it still selects18350/P1835C2/Keystone1101, ≥35 mm supports and a pending build quantity. PM should align it with protected long18650/P1835J button-top/BH-18650-W, proposed112×36×44 cassette/≥47 mm supports, five complete instruments and optional sixth bare carrier. Qualify its opening parity-pass statement with the actual four metadata warnings. This helper left that root-owned file unchanged.
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

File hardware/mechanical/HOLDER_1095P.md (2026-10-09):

# Underside protected-18350 holder: corrected drawing review

**Historical superseded 18350 research.** On 2026-10-09 the user corrected the requirement to protected removable 18650. Current holder/cassette specs are in [WIRED_HOLDER_PROPOSAL.md](WIRED_HOLDER_PROPOSAL.md); no dimensions or cell-fit assumptions here apply to that 18650 assembly.

Review date 2026-10-07. Revision one uses a removable protected 18350 with **external charging**, as selected in merged PR #11; this review incorporates the power contract in [rev1-handoff.md](../power/rev1-handoff.md) from merged PR #12. Cell model/lot and holder are still candidates. The previously supplied **Keystone 1095P** footprint has been
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

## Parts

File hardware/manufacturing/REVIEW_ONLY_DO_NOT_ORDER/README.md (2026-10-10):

# Make Music P1 — held manufacturing review

CONDITIONAL QUOTE / REVIEW ONLY — DO NOT FABRICATE OR ORDER.

The owner authorized final team review followed by PCBWay quote-only uploads
and contact on October9,2026. This is permission to price the documented
alternatives and engineering work, not acceptance of a price or production.
Historical verification documents retain their original release restrictions;
the current quote-only authorization waives no physical or factory release gate.

This package derives from the revised long protected 18650 carrier, including
C17/C18, moved J3/J4 and underside H1. It uses native (0,0), x right/y up;
board corners (20,-18.5)..(350,-140) mm, 330 ×121.5 mm.
The mechanical/service datum remains native(20,20). Do not mix with obsolete exports.

47 purchased carrier parts: 30 top SMT and 17 THT. Use pcbway-centroid-smt.csv
for machine placement; manual-tht-positions.csv describes the THT assembly.
pcbway-bom-five.csv contains 235 carrier parts for five instruments. Modules, Pico, holder,
battery, harnesses and mechanical work are additional scope in [PCBWAY_HANDOFF.md](PCBWAY_HANDOFF.md).
An optional sixth bare keepsake is separate.

[QUOTE_REQUEST.md](QUOTE_REQUEST.md) requests an itemized,
conditional five-instrument quote, including metrology and final mechanical work.
Linked supporting documents, nominal DXFs/SVGs, paper-fit PDF and provisional
firmware are bundled under support/. Relative document links are rebased within
this package; manifest.json records both original support-input and output hashes.
Supplier contact/upload status is recorded separately in the submission receipt.
This package does not grant fabrication release or permission to purchase.

Read validation-summary.json and verification/ for the actual check scope.
Overall DRC and native schematic parity retain four reviewed custom-field metadata warnings; electrical
integration has zero ERC/copper/layout/unconnected findings. No DRC categories
or findings are hidden. Nominal socket body/courtyard rear margins are 1.275/0.77 mm. Physical
fit, socket engagement/lip acceptance, final
mechanical CAD, charger matching, factory process/orientation acceptance and
bench qualification remain required. Whole Gerber/drill layers and all five
native drawing pages have been inspected; exported placement/aperture/hole
inventories pass. Enlarged front copper/mask/paste/polarity review and all
native drawing pages are complete within export-review.md scope. This does
not establish physical fit or factory process acceptance.

No fabrication release, complete quote, runtime or hardware success is claimed.

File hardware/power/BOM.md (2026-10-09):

# Current power candidate BOM — protected 18650

Updated **2026-10-09** for **five fully assembled instruments** and an optional sixth bare carrier keepsake. The user's corrected long **18650** selection supersedes P1835C2/18350 and Keystone 1101. This is a candidate specification, not purchase or manufacturing approval. Exact lot, terminal form, holder fit and charger compatibility remain held in [18650-handoff.md](18650-handoff.md).

The active carrier protection BOM/pins are in [branch-protection.md](branch-protection.md) and [branch-endpoints.csv](branch-endpoints.csv): F1 **3403.0275.23**, S1 **MN12SS1W03**, U2 **TPS259474LRPWR**, six exact resistors, four ceramic capacitors, shunt D2 **SS14-E3/61T** and bidirectional D3 **SMAJ5.0CA**. Native references are power R3–R8/C13–C16; original R1/R2 and C1–C12 serve buzzer bias/header bypass. Carrier series D1 is removed. PM's [current held carrier BOM](../manufacturing/REVIEW_ONLY_DO_NOT_ORDER/carrier-bom.csv) is source-bound to native `21b2108`; the package published at `d987896` does not authorize purchasing or fabrication.

| Item | Exact candidate / specification | Per instrument | Five assembled units | Status |
|---|---|---:|---:|---|
| Protected conventional 18650 cell | **Keeppower P1835J**, standard opposite-end-terminal product with positive button top, [manufacturer page id510](https://www.keeppower.com.cn/products_detail.php?id=510) | 1 | 5 | Confirm delivered button-top version/current-lot ratings/fit; published standard 18.8×69.3 mm planning envelope is not a variant fit guarantee |
| External charger | **Keeppower L1** evaluation target; initially 500 mA qualification setting | Shared accessory | One shared set proposed; HOLD | Quantity is a current PM quote assumption, not finalized distribution. **Compatibility HOLD**: 4.242 V upper charger tolerance versus unqualified 4.20 V cell maximum; no approved pair |
| Charger input supply/cable | Delivered L1 revision needs suitable 5 V/1 A supply and matching USB cable | Per accepted charger | One shared set proposed; HOLD | Supply SKU/revision remains unselected; include in the eventual accepted charger set |
| Wired holder | **MPD BH-18650-W**, includes two factory 24 AWG TR64 leads, 150±5 mm each | 1 | 5 | Protected button-top required; exact-cell fit/removal/contact travel/ampacity and lead OD/crimp process pending |
| Insulating cassette | Mechanical [PR #30](https://github.com/John-ODell/Make_Music/pull/30) proposal, 112×36×44 mm with ≥47 mm supports | 1 | 5 | Final measured CAD/tolerances/loaded clearance required; H1 relocation retained in current source-bound evidence/held package |
| Carrier battery header H1 | **JST B2B-PH-K-S(LF)(SN)**, circuit1 positive/circuit2 GND | 1 | 5 | Existing carrier interface; underside THT orientation and actual harness continuity must pass |
| Factory harness termination | **JST PHR-2** housing + two **SPH-002T-P0.5S** contacts, on included holder leads | 1 housing, 2 contacts | 5 housings, 10 contacts | Measure lead OD against 0.8–1.5 mm; qualify contact/tool/strip/crimp/strain relief and polarity; no holder-lug solder operation |
| Additional battery wire | None for the proposed factory-lead harness; 0.30 m nominal pair is already included with holder | 0 | 0 | Any extension/change requires a measured routing need and reviewed termination; do not duplicate the earlier separate-wire allocation |
| Added buzzer supply bulk | Native **C17/C18** added by merged PR #27, each **TDK C2012X7R1A106K125AC**, 10 µF/10 V/X7R/0805 on 3V3_OUT | 2 | 10 | Current source-bound placement/routing/electrical evidence and held package complete; assembly process and effective capacitance/startup/transients pending; retain existing 100 nF |

The optional sixth bare PCB gets no populated-component, cell or harness allocation. Include all small SMT parts, all THT sockets/headers/switch/H1, harness/module installation and accepted mechanical work for each of the five complete instruments. Confirm how accepted cells/chargers are supplied and fitted; no supplier exclusion should silently become user soldering. Fit/process and unit acceptance remain required. The PM-owned [main instrument table](../assembly/instrument-parts.csv) now includes the power supplement's button-top, included-lead and charger-input requirements. [instrument-parts-handoff.csv](instrument-parts-handoff.csv) is historical integration input and a candidate specification, not a second complete purchasing BOM; its earlier TBD charger quantity must not overwrite the main table's proposed shared-set scope.

**No change to carrier load/protection limits:** ≤0.70 A battery input; ≤350 mA total and ≤250 mA external 3V3; ≤100 µF total VSYS. Higher cell capacity does not increase these limits. BQ24074, NTC and dedicated charging-input parts are omitted from revision 1. A real cell is fitted only after [the bring-up gate](prototype-validation.md) and cell/charger qualification pass.

## Primary evidence and history

- [Current 18650 handoff](18650-handoff.md) links the standard/global P1835J pages, explicitly dated current-rating catalogue and L1 manufacturer documents, with unresolved voltage/termination/lot/terminal evidence.
- [TI TPS25947](https://www.ti.com/lit/ds/symlink/tps25947.pdf), [SCHURTER UMT-H](https://www.schurter.com/en/datasheet/typ_UMT-H.pdf), [NKK MN12SS1W03 drawing](https://www.nkkswitches.com/pdf/MN_ToggleSections_DP.pdf), [Vishay SS14](https://www.vishay.com/docs/88746/ss12.pdf) and [TDK added 10 µF part](https://product.tdk.com/en/search/capacitor/ceramic/mlcc/info?part_no=C2012X7R1A106K125AC) support carrier component choices; their mechanical/electrical limits are not measured assembly results.
- [Superseded 18350 handoff](rev1-handoff.md), [historical budget comparison](candidate-comparison.md) and [dated PCBWay audit](pcbway-readiness.md) retain the earlier research/checkpoint. Those sources do not qualify the new 18650 assembly or charger.

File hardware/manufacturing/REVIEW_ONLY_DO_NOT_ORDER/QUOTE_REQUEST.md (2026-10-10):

# Quote request draft — five complete Make Music instruments

**Authorized for conditional quotation on October 9, 2026. QUOTE ONLY — DO NOT
FABRICATE OR ORDER.** No project price or fabrication release is approved.

Please provide an itemized, nonbinding quotation and identify operations your
team cannot supply. The selected delivery is **five complete instruments**,
including one qualified first article within those five before completing the
remaining four. Quote an optional additional sixth bare carrier separately.
We request factory soldering, crimping, mechanical installation, programming
and testing; the owner has no parts or precision measurement equipment.

## Review inputs and quantity

- Carrier:330×121.5 mm, two layers,1.6 mm FR4, proposed≥35µm finished copper,
  ENIG, green mask/white legend; process/finish subject to your review.
- Each carrier:47 purchased parts,30 top SMT and17 THT. H1 is bottom THT;
  no bottom SMT. Five carriers total150 SMT and85 THT parts.
- Complete instruments add5 original Pico H SC0917,50 HiLetgo touch modules,
  10 SunFounder ST0238 passive modules,60 adapted three-wire module cables,
  5 protected removable18650/MPD BH-18650-W holder assemblies and5 complete
  insulating fixture/cassette/support sets. See the
  [complete assembly scope](support/hardware/assembly/PCBWAY_HANDOFF.md) and [parts allowances](support/hardware/assembly/instrument-parts.csv).
- One shared external charger/input set is a proposed quote assumption;
  the exact compatible cell/charger pair is unresolved and held.
- [Reviewed carrier outputs](README.md)
  include Gerbers, separate PTH/NPTH drills, exact MPN BOM, SMT centroid,
  manual THT positions, drawing PDFs and source-bound verification.

## Requested price lines

Please separate fabrication; SMT setup/stencil/parts/labor; THT parts/labor;
Picos and modules; module and battery harnesses; holder/cells/charger;
custom mechanical manufacture and assembly; precision metrology;
first-article qualification; programming/all-five testing; shipping/tax;
and the optional sixth bare keepsake. List assumed or provisional items
separately from firm prices, quote validity, lead time and minimum quantities.

Please compare three alternative scopes for the **same physical board design**:

| Option | Quantity | Included scope |
|---|---|---|
| A — bare carrier | Five | PCB fabrication only; no components supplied or soldered |
| B — populated carrier | Five | PCB plus all47 purchased carrier components per board supplied and soldered:30 SMT and17 THT, including capacitors, female sockets, headers, switch and bottom H1 |
| C — complete instrument | Five | Option B plus Pico, touch/buzzer modules, adapted harnesses, battery/holder, final mechanical work, programming and specified tests described above |

These are alternative prices, **not an order for fifteen boards**. Option C is
the selected delivery preference. Price the optional sixth bare keepsake
separately. In Option B, identify external modules, Picos, cells/charger,
harnesses, mechanical work and final instrument tests as excluded.

If useful, provide an additional SMT-only breakdown for30 top parts per board;
identify all17 THT parts and remaining operations as excluded. See the
[budget comparison](support/hardware/ASSEMBLY_BUDGET.md).
The earlier$67.54 setup/stencil example is not a complete-build price.

## Engineering work and production holds

Please price exact-part measurement, adapted module-end terminations,
final toleranced fixture/cassette/retainer drawings and process review.
The [fit checklist](support/hardware/assembly/FIT_CHECKLIST.md) and
[mechanical checklist](support/hardware/mechanical/PHYSICAL_FIT_CHECKLIST.md) specify records
needed; nominal SVG/DXF interfaces are review references, not machining release.

Confirm ability to handle U2 copper/mask/stencil details, nominal0.25 mm socket
annular rings, C17/C18 land choice, panel rails/fiducials/tooling,
depaneling/THT sequence, bottom H1 and orientation/polarity preview.
Record exact module revisions, header mapping, qualified crimps, Pico/socket
engagement and removal, battery/holder cold fit and contact current capability.
Return documentary evidence for a cell/charger pair within the cell's limits.

The design review reports ERC0, copper/layout DRC0 and unconnected0.
Native schematic parity retains4 reviewed custom-field metadata warnings;
pad nets, values and full footprint IDs have0 discrepancies. These checks
do not establish mechanical fit or tested hardware behavior.

Do not fabricate or start a first-article build until the owner separately
approves the parts, required drawing/process revisions and production release.
After release, use the [current-limited first-article procedure](support/hardware/power/prototype-validation.md)
and provide acceptance records for all five completed instruments.

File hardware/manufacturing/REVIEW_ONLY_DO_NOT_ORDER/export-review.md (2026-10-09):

# Final carrier export review — 2026-10-09

REVIEW ONLY — DO NOT ORDER OR UPLOAD.

Native design is root 21b2108: 330 x121.5 mm, native corners
(20,18.5)..(350,140). Later commits change ordinary documentation only.
The source checkpoint and original 18-artifact hashes bind the reviewed exports.

Independent power helper checked all 47 placements, rotations and sides
against recorded IPC, defined aperture/macro references in all eight layers,
a closed four-segment outline, 130 PTH drill hits (97 component holes and
33 vias), and all 17 NPTH 3.2 mm holes. Full pipeline passed 47/30/17 and
changed U2 rotation/C17 displacement rejected before destination creation.
See independent-export-review.txt. This is exported-data and recorded-evidence
review, not a new live ERC/DRC, graphical inspection or physical test.

PM loaded the final eight-layer job and both drill sets in native Gerber
Viewer. Whole front copper/mask/legend, whole back copper/mask/legend,
isolated back mask/legend and isolated top paste were inspected. Registration,
rear outline/socket markers, mounting-hole exclusions and H1 bottom legend
agree. No paste appears on through-hole/socket positions. Bottom legend is
mirrored in the through-top view. Detailed cursor navigation was unreliable.
The actual paste layer was printed locally from Gerber Viewer to PDF and its
power-section crop inspected: separate fine apertures and split centre area
are visible. This does not certify stencil thickness or solder yield.

All five native drawing pages were rendered and inspected: two schematic
pages, top assembly, bottom-through-top assembly and copper layout. They show
the current long 18650 reservation, C17/C18, relocated J3/J4 and final edge.
Both updated paper-fit Letter pages from mechanical PR34 were also rendered
and inspected; scale bars, labels and registration crosses are readable.

PM additionally printed the actual isolated front copper, front mask and front
legend from Gerber Viewer to local PDFs. Enlarged power crops show distinct
fine copper/mask apertures, the U2 orientation dot, D2 K mark and S1 3/ON,
2/COM,1/OFF numbering. Buzzer/note headers show1:S,2:3V3,3:G; C17/C18
and relocated J3/J4 labels agree with recorded IPC and assembly views.
The local fit-to-page prints are inspection aids, not dimensioned fabrication
outputs. Whole-layer, detail and all native PDF page visual review is complete
within this stated scope. Process margins still require factory acceptance.

External release holds: exact parts,
module pin/header/support geometry, Pico socket engagement/USB access,
18650/holder fit and current capability, qualified harness/crimps, final
mechanical tolerances/retention, charger voltage pairing, factory stencil/
annular-ring/land/panel/orientation acceptance and first-article/all-five
bench tests. No physical fit, supplier acceptance or fabrication release.

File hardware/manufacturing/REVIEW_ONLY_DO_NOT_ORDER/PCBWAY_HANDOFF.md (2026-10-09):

# Five complete Make Music prototypes — assembly planning handoff

Updated 2026-10-09. **REVIEW ONLY — DO NOT ORDER.** This is a concrete scope for
an eventual quotation, not an accepted order or fabrication release. No files
have been uploaded and no supplier has been contacted.

## Quantity and finished result

The requested delivery is **five complete instruments**. Include all carrier
SMT components, through-hole parts, sockets, twelve adapted module cables,
module mounting fixture, battery cassette and underside supports. The user
should have no capacitor, resistor, chip, header or harness soldering to do.
Include five original Raspberry Pi Pico H SC0917, fifty HiLetgo touch modules
and ten SunFounder ST0238 passive buzzer modules. Insert the removable Pico
for programming/testing; agree its installed or separately packed shipping
condition. Cells are removable and externally charged; no onboard charger.

Quote an **additional sixth bare carrier** separately as an optional keepsake.
It does not replace any of the five populated instruments. Screen, keypad,
extra percussion buzzer and other Pico models are future revisions.

Quote metrology and one first-article fit/bring-up before completing the other
four instruments. Record functional acceptance for all five units. Unknown
module terminations and custom fixture details must be resolved in that
first-article work, rather than supplied as unspecified user assembly.

## Parts and operations

| Scope | Per instrument | Five instruments | Required operation |
|---|---:|---:|---|
| Purchased carrier parts | 47 | 235 | 30 top SMT + 17 THT per carrier; exact netlist-derived MPN BOM |
| Pico H SC0917 | 1 | 5 | Removable insertion in two Samtec SSQ-120-01-G-S sockets |
| HiLetgo touch modules, reference 1915450 | 10 | 50 | Eight notes + two left modifiers; verify delivered revision and momentary output |
| SunFounder ST0238 passive modules | 2 | 10 | Confirm signal order, passive variable-pitch operation and reset silence |
| Three-wire module harnesses | 12 | 60 | Adapt module ends; carrier end Harwin M20-1060300 + three M20-1180046 |
| Carrier-end module contacts | 36 | 180 | Qualified AWG26 crimps; identify pin1 and test each circuit |
| Protected conventional 18650 + holder | 1 each | 5 each | Candidate matching/fit gate; MPD BH-18650-W factory wire leads |
| Battery harness | 1 | 5 | JST PHR-2 + two SPH-002T-P0.5S; positive circuit1, ground circuit2 |
| Insulating cassette, raised module fixture, support feet | 1 set | 5 sets | Final machining drawings and loaded clearance after actual-part metrology |
| External charger + required input accessory | Shared accessory | 1 shared set proposed; HOLD | Quantity is a quote assumption; exact cell/charger compatibility must be established before inclusion |

The [instrument parts list](support/hardware/assembly/instrument-parts.csv) gives candidate hardware,
wire allowances and mechanical quantities. These allowances are not installed
wire lengths. The purchased carrier BOM excludes TP1 copper and 17 NPTH
mounting holes. It also excludes the removable Pico and external modules.

Carrier J3–J14 use **1 signal / 2 regulated 3V3 / 3 ground**. The unkeyed Harwin
housing needs a visible signal-end mark, retention and continuity inspection.
ST0238 module order differs from the carrier order; cables are adapted, not
assumed straight through. Follow [module harnesses](support/hardware/assembly/MODULE_HARNESSES.md).
Do not apply battery voltage to touch/buzzer power pins or exposed GPIO.

H1 is the **bottom-mounted THT** JST-PH, positive circuit1. Verify by cavity
number and continuity to F1; colors alone do not establish polarity. The
MPD holder has factory-installed AWG24 leads: qualify their insulation diameter
and crimp compatibility rather than automatically adding solder-lug wiring.
All other purchased carrier components are top-side. D2 is polarized (K1 on
VSYS, A2 ground); D3 must retain the bidirectional **CA** suffix. U2 has ten
physical terminals and no pad11. Do not substitute an active fixed-tone buzzer.

## Fabrication and assembly process review

Proposal: 330 × 121.5 mm, two layers, 1.6 mm FR4, at least 35 µm finished copper
on both layers, green solder mask, white legend, lead-free assembly. ENIG is a
proposed finish for the small U2 lands; request the fabricator's stackup and
assembler's accepted finish/stencil process. No controlled impedance,
blind/buried vias or via-in-pad. Seventeen 3.2 mm holes are NPTH.

Process questions to resolve before release:

- U2 has 0.20 mm closest copper gap, nominal 0.10 mm mask web and TI's example
  0.100 mm stencil apertures. Obtain mask/stencil/solder-joint acceptance.
- Pico socket holes have nominal 0.25 mm annular rings. Confirm finished-hole
  fit and accepted annular-ring process; do not assume rounding to a published
  10 mil (0.254 mm) normal-process rule is approved.
- C17/C18 use standard KiCad 0805 lands. Their pad length/width exceed TDK's
  example ranges, while the gap agrees. The documented engineering land choice
  needs assembly acceptance or a reviewed footprint revision.
- The new rear edge clears nominal socket bodies by 1.275 mm and their
  courtyards by 0.77 mm; actual fit remains unmeasured. Factory
  panel/handling rails need fiducials and tooling holes. Agree depaneling and
  THT order so the sockets remain undamaged; carrier holes are mounting holes,
  not an approved substitute for factory tooling.
- The enlarged insulating 18650 cassette is a mechanical reservation, not a
  verified enclosure. Require ≥2 mm loaded clearance from bottom parts,
  solder tails and wires, including tolerances and deflection. The four cassette
  bolt exclusions remain enforced; any older partial copper restriction is
  identified separately in PCB status.

The centroid contains **only the 30 SMT parts**. Separate manual THT positions
cover sockets, headers, switch and bottom H1. Native exports use (0,0), x right
and y up: board corners (20,-18.5) to (350,-140) mm. Mechanical drawings use
the retained service datum native(20,20), x right/y down: add20 to x and
negate y+20 for machine coordinates. The rear edge is service y=-1.5; do not
shift placements to a new top-left origin. Never
mix the earlier bottom-left-origin package with this revision. Check rotations
against pin1 marks, particularly U2, D2 and bottom H1. A bottom-layer drawing
viewed through the top must be labeled that way, not called an underside view.

## Acceptance and release gates

Complete the [precise fit checklist](support/hardware/assembly/FIT_CHECKLIST.md) and
[mechanical readiness record](support/hardware/mechanical/BUILD_READINESS.md) using actual
parts and suitable metric measurement tools. The user's tape measure and
[paper fit print](support/output/pdf/make-music-paper-fit-letter.pdf) can check
overall size and reach; they cannot certify pad pitch or connector engagement.

Complete the staged [power and functional procedure](support/hardware/power/prototype-validation.md)
with a current-limited cell emulator before real-cell use. Record per-unit
polarity, source isolation, normal load, fault behavior, temperature, all ten
touch inputs and two variable-pitch outputs. Use
`Pico_Synth/carrier_prototype.py` as the current provisional firmware;
actual touch polarity and module behavior must be confirmed in hardware.
Design limits are 0.70 A battery branch, 250 mA external 3V3 and 350 mA total
3V3 including Pico. They are not measured performance or a runtime promise.

The exact protected cell lot, ordinary opposite-end terminals and external
charger tolerances remain gates. Do not replace these with anonymous battery
marketing dimensions. Final fixture/cassette CAD, supplier process acceptance,
first-article fit and bench evidence are required for release. Passing ERC/DRC
does not populate those physical evidence fields.

## Quote breakdown

Show PCB fabrication, carrier SMT setup/stencil/parts/labor, THT labor,
module sourcing, harness crimps/adaptation, fixture/cassette machining,
metrology, first-article qualification, five-unit programming/testing,
Picos/cells/charger, shipping/tax and optional sixth bare board as separate
lines. Price a five-carrier SMT-only alternative as a comparison, clearly
identifying every remaining soldering/mechanical operation. The selected
delivery remains five complete instruments. See [budget worksheet](support/hardware/ASSEMBLY_BUDGET.md).

Sources checked 2026-10-09: [PCBWay assembly file requirements](https://www.pcbway.com/assembly-file-requirements.html),
[PCBWay capabilities](https://www.pcbway.com/capabilities.html),
[panel rails/fiducials/tooling](https://www.pcbway.com/helpcenter/design_instruction/PCB_Panelization__Breakaway_Rails__Fiducial_Marks__Tooling_Holes.html).
These describe supplier inputs and advertised processes; they do not establish
acceptance of this design or a project price.

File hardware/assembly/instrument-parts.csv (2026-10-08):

Quantity per instrument | Category | Manufacturer | Part | Status | Assembly scope
1 | Controller | Raspberry Pi | Pico H SC0917 | Selected prototype candidate; male/socket engagement untested | User removable insertion after factory carrier assembly
10 | Touch modules | HiLetgo | TTP223-BA6 reference 1915450 | User supplied 24x24x7.2 body; actual revision and header termination pending | Factory fixture mounting and adapted module cables
2 | Buzzer modules | SunFounder | ST0238 | Selected; 32x14 outline verified; height/header engagement pending | Factory fixture mounting and adapted module cables
1 | Holder | Keystone | 1101 | Exact solder-lug holder candidate; protected-cell fit and ampacity pending | Factory solder and insulate holder leads with cell absent
1 | Battery plug housing | JST | PHR-2 | Manufacturer matched to carrier H1 | Factory crimped harness and polarity test
2 | Battery contacts | JST | SPH-002T-P0.5S | Manufacturer matched; AWG24 within insulation range | Factory crimped harness
0.30 m | Battery wire | Assembler specification | AWG24 red and black stranded | 150mm per lead engineering cut allowance; installed length by fit trial | Factory insulated harness and strain relief
12 | Module cable housings | Harwin | M20-1060300 | Verified carrier-end candidate; unkeyed orientation control required | Factory twelve 3-wire carrier connectors
36 | Module cable contacts | Harwin | M20-1180046 | Verified AWG26-compatible loose tin contact | Factory crimp qualification and harness continuity
3.60 m | Module cable wire | Assembler specification | AWG26 white red black stranded | 100mm per conductor engineering allowance; not measured installed length | Factory twelve adapted module cables
4 | Cassette bolts | Essentra | 50M030050P012 | Verified M3x12 nylon dimensional candidate | Factory mechanical assembly
4 | Cassette nuts | Essentra | 04M030050HNDIN34814 | Verified M3 nylon dimensional candidate | Factory mechanical assembly
8 | Cassette washers | Essentra | MFW030A | Verified ID3.2 OD7 thickness0.5 nylon | Factory mechanical assembly
4 | Cassette spacers | Essentra | 13ME036 | Verified ID3.2 OD8 length3 nylon | Factory mechanical assembly
1 | Cassette | Custom | Insulating 1101 cassette | Proposed 70x36x32; clamp/door details require actual parts | Factory mechanical subassembly after fit validation
1 | Module fixture | Custom | Raised insulating module fixture | Dimensioned proposal pending final actual-part fit | Factory mechanical subassembly after fit validation
1 | Cell | Keeppower | P1835C2 | Protected removable candidate; 1101 fit and matched charging qualification pending | Separate cell; user insertion only after tested polarity and branch load
1 per user | External charger | Keeppower | L1 at 500mA | Candidate; protected-cell bay fit and electrical compatibility pending | Separate external charger; no onboard charging
9 | Fixture bolts | Essentra | 50M030050P035 | Verified M3x35 nylon dimensional candidate | Factory fixture assembly
9 | Fixture nuts | Essentra | 04M030050HNDIN34814 | Verified M3 nylon dimensional candidate | Factory fixture assembly
18 | Fixture washers | Essentra | MFW030A | Verified ID3.2 OD7 thickness0.5 nylon | Factory fixture assembly
9 | Fixture spacers | Custom | Acetal OD8 ID3.2 length24mm | Engineering proposal; final height by fit | Factory custom machining and assembly
24 | Keeper bolts | Essentra | 50M020040P010 | Verified M2x10 nylon dimensional candidate | Factory module retention
24 | Keeper nuts | Essentra | 04M020040HN | Verified M2 nylon dimensional candidate | Factory module retention
48 | Keeper washers | Essentra | MFW010A | Verified ID2.2 OD5 thickness0.3 nylon | Factory module retention
24 | Module keepers | Custom | Stepped insulating keeper | 20 touch and4 buzzer; pedestal thickness measured per module lot | Factory custom machining and assembly
4 | Corner support feet | Custom | Insulating supports at corner holes | Engineering reservation >=35mm below underside; final fasteners/enclosure pending | Factory mechanical assembly; cell must carry no playing load

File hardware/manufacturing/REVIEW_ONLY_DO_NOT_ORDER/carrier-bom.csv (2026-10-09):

Reference | Quantity | Manufacturer | MPN | Value | Footprint | Assembly | Side | Datasheet
C1 | 1 | KEMET | C0603C104K5RACTU | 100n | MakeMusicCarrier:KEMET_C0603_1608_LevelB | SMT | Top | https://search.kemet.com/component-documentation/download/specsheet/C0603C104K5RACTU
C2 | 1 | KEMET | C0603C104K5RACTU | 100n | MakeMusicCarrier:KEMET_C0603_1608_LevelB | SMT | Top | https://search.kemet.com/component-documentation/download/specsheet/C0603C104K5RACTU
C3 | 1 | KEMET | C0603C104K5RACTU | 100n | MakeMusicCarrier:KEMET_C0603_1608_LevelB | SMT | Top | https://search.kemet.com/component-documentation/download/specsheet/C0603C104K5RACTU
C4 | 1 | KEMET | C0603C104K5RACTU | 100n | MakeMusicCarrier:KEMET_C0603_1608_LevelB | SMT | Top | https://search.kemet.com/component-documentation/download/specsheet/C0603C104K5RACTU
C5 | 1 | KEMET | C0603C104K5RACTU | 100n | MakeMusicCarrier:KEMET_C0603_1608_LevelB | SMT | Top | https://search.kemet.com/component-documentation/download/specsheet/C0603C104K5RACTU
C6 | 1 | KEMET | C0603C104K5RACTU | 100n | MakeMusicCarrier:KEMET_C0603_1608_LevelB | SMT | Top | https://search.kemet.com/component-documentation/download/specsheet/C0603C104K5RACTU
C7 | 1 | KEMET | C0603C104K5RACTU | 100n | MakeMusicCarrier:KEMET_C0603_1608_LevelB | SMT | Top | https://search.kemet.com/component-documentation/download/specsheet/C0603C104K5RACTU
C8 | 1 | KEMET | C0603C104K5RACTU | 100n | MakeMusicCarrier:KEMET_C0603_1608_LevelB | SMT | Top | https://search.kemet.com/component-documentation/download/specsheet/C0603C104K5RACTU
C9 | 1 | KEMET | C0603C104K5RACTU | 100n | MakeMusicCarrier:KEMET_C0603_1608_LevelB | SMT | Top | https://search.kemet.com/component-documentation/download/specsheet/C0603C104K5RACTU
C10 | 1 | KEMET | C0603C104K5RACTU | 100n | MakeMusicCarrier:KEMET_C0603_1608_LevelB | SMT | Top | https://search.kemet.com/component-documentation/download/specsheet/C0603C104K5RACTU
C11 | 1 | KEMET | C0603C104K5RACTU | 100n | MakeMusicCarrier:KEMET_C0603_1608_LevelB | SMT | Top | https://search.kemet.com/component-documentation/download/specsheet/C0603C104K5RACTU
C12 | 1 | KEMET | C0603C104K5RACTU | 100n | MakeMusicCarrier:KEMET_C0603_1608_LevelB | SMT | Top | https://search.kemet.com/component-documentation/download/specsheet/C0603C104K5RACTU
C13 | 1 | TDK | C2012X7R1E475K125AB | 4u7 / 25V | Capacitor_SMD:C_0805_2012Metric | SMT | Top | https://product.tdk.com/en/search/capacitor/ceramic/mlcc/info?part_no=C2012X7R1E475K125AB
C14 | 1 | TDK | C2012X7R1E475K125AB | 4u7 / 25V | Capacitor_SMD:C_0805_2012Metric | SMT | Top | https://product.tdk.com/en/search/capacitor/ceramic/mlcc/info?part_no=C2012X7R1E475K125AB
C15 | 1 | TDK | C1608C0G1H103J080AA | 10n / 50V | Capacitor_SMD:C_0603_1608Metric | SMT | Top | https://product.tdk.com/en/search/capacitor/ceramic/mlcc/info?part_no=C1608C0G1H103J080AA
C16 | 1 | TDK | C2012X7R1E475K125AB | 4u7 / 25V | Capacitor_SMD:C_0805_2012Metric | SMT | Top | https://product.tdk.com/en/search/capacitor/ceramic/mlcc/info?part_no=C2012X7R1E475K125AB
C17 | 1 | TDK | C2012X7R1A106K125AC | 10u / 10V | Capacitor_SMD:C_0805_2012Metric | SMT | Top | https://product.tdk.com/info/en/documents/chara_sheet/C2012X7R1A106K125AC.pdf
C18 | 1 | TDK | C2012X7R1A106K125AC | 10u / 10V | Capacitor_SMD:C_0805_2012Metric | SMT | Top | https://product.tdk.com/info/en/documents/chara_sheet/C2012X7R1A106K125AC.pdf
D2 | 1 | Vishay | SS14-E3/61T | SS14-E3/61T | MakeMusicCarrier:Vishay_SS14_SMA_K1_A2 | SMT | Top | https://www.vishay.com/docs/88746/ss12.pdf
D3 | 1 | Littelfuse | SMAJ5.0CA | SMAJ5.0CA | MakeMusicPower:Littelfuse_SMAJ5-0CA_DO-214AC | SMT | Top | https://www.littelfuse.com/~/media/electronics/datasheets/tvs_diodes/littelfuse_tvs_diode_smaj_datasheet.pdf.pdf
F1 | 1 | SCHURTER | 3403.0275.23 | 1.25A T | MakeMusicPower:Schurter_UMT-H_3403-0275-23 | SMT | Top | https://www.schurter.com/en/datasheet/typ_UMT-H.pdf
H1 | 1 | JST | B2B-PH-K-S(LF)(SN) | JST PH battery | Connector_JST:JST_PH_B2B-PH-K_1x02_P2.00mm_Vertical | THT | Bottom | https://www.jst-mfg.com/product/pdf/eng/ePH.pdf
J1 | 1 | Samtec | SSQ-120-01-G-S | LEFT / Pico 1-20 | MakeMusic:Samtec_SSQ-120-01-G-S_1x20_P2.54mm | THT | Top | https://suddendocs.samtec.com/prints/ssq-1xx-xx-xxx-x-xx-xxx-xx-x-mkt.pdf
J2 | 1 | Samtec | SSQ-120-01-G-S | RIGHT / Pico 21-40 | MakeMusic:Samtec_SSQ-120-01-G-S_1x20_P2.54mm | THT | Top | https://suddendocs.samtec.com/prints/ssq-1xx-xx-xxx-x-xx-xxx-xx-x-mkt.pdf
J3 | 1 | Harwin | M20-9990346 | C4 / GP16 | MakeMusicCarrier:Harwin_M20-9990346_1x3_P2.54mm | THT | Top
J4 | 1 | Harwin | M20-9990346 | D4 / GP17 | MakeMusicCarrier:Harwin_M20-9990346_1x3_P2.54mm | THT | Top
J5 | 1 | Harwin | M20-9990346 | E4 / GP18 | MakeMusicCarrier:Harwin_M20-9990346_1x3_P2.54mm | THT | Top
J6 | 1 | Harwin | M20-9990346 | F4 / GP19 | MakeMusicCarrier:Harwin_M20-9990346_1x3_P2.54mm | THT | Top
J7 | 1 | Harwin | M20-9990346 | G4 / GP20 | MakeMusicCarrier:Harwin_M20-9990346_1x3_P2.54mm | THT | Top
J8 | 1 | Harwin | M20-9990346 | A4 / GP21 | MakeMusicCarrier:Harwin_M20-9990346_1x3_P2.54mm | THT | Top
J9 | 1 | Harwin | M20-9990346 | B4 / GP22 | MakeMusicCarrier:Harwin_M20-9990346_1x3_P2.54mm | THT | Top
J10 | 1 | Harwin | M20-9990346 | C5 / GP26 | MakeMusicCarrier:Harwin_M20-9990346_1x3_P2.54mm | THT | Top
J11 | 1 | Harwin | M20-9990346 | Semitone up / GP27 | MakeMusicCarrier:Harwin_M20-9990346_1x3_P2.54mm | THT | Top
J12 | 1 | Harwin | M20-9990346 | Octave up / GP28 | MakeMusicCarrier:Harwin_M20-9990346_1x3_P2.54mm | THT | Top
J13 | 1 | Harwin | M20-9990346 | Buzzer 1 / PWM / GP13 | MakeMusicCarrier:Harwin_M20-9990346_1x3_P2.54mm | THT | Top
J14 | 1 | Harwin | M20-9990346 | Buzzer 2 / PWM / GP12 | MakeMusicCarrier:Harwin_M20-9990346_1x3_P2.54mm | THT | Top
J15 | 1 | Harwin | M20-9991646 | GPIO / Harwin 16-way | MakeMusicCarrier:Harwin_M20-9991646_1x16_P2.54mm | THT | Top
R1 | 1 | Yageo | RC0603FR-0710KL | 10k | Resistor_SMD:R_0603_1608Metric | SMT | Top | https://www.yageogroup.com/component-documentation/download/specsheet/RC0603FR-0710KL
R2 | 1 | Yageo | RC0603FR-0710KL | 10k | Resistor_SMD:R_0603_1608Metric | SMT | Top | https://www.yageogroup.com/component-documentation/download/specsheet/RC0603FR-0710KL
R3 | 1 | Yageo | RC0603FR-07649KL | 649k | Resistor_SMD:R_0603_1608Metric | SMT | Top | https://yageogroup.com/component-documentation/download/specsheet/RC0603FR-07649KL
R4 | 1 | Yageo | RC0603FR-07332KL | 332k | Resistor_SMD:R_0603_1608Metric | SMT | Top | https://yageogroup.com/component-documentation/download/specsheet/RC0603FR-07332KL
R5 | 1 | Yageo | RC0603FR-071M05L | 1.05M | Resistor_SMD:R_0603_1608Metric | SMT | Top | https://yageogroup.com/component-documentation/download/specsheet/RC0603FR-071M05L
R6 | 1 | Yageo | RC0603FR-07332KL | 332k | Resistor_SMD:R_0603_1608Metric | SMT | Top | https://yageogroup.com/component-documentation/download/specsheet/RC0603FR-07332KL
R7 | 1 | Yageo | RC0603FR-073K32L | 3.32k | Resistor_SMD:R_0603_1608Metric | SMT | Top | https://yageogroup.com/component-documentation/download/specsheet/RC0603FR-073K32L
R8 | 1 | Yageo | RC0603FR-07100RL | 100 | Resistor_SMD:R_0603_1608Metric | SMT | Top | https://yageogroup.com/component-documentation/download/specsheet/RC0603FR-07100RL
S1 | 1 | NKK | MN12SS1W03 | MN12SS1W03 | MakeMusicCarrier:NKK_MN12SS1W03_TerminalPattern_Candidate | THT | Top | https://www.nkkswitches.com/pdf/MN_ToggleSections_DP.pdf
U2 | 1 | Texas Instruments | TPS259474LRPWR | TPS259474LRPWR | MakeMusicPower:TI_RPW0010A_TPS259474_2x2mm | SMT | Top | https://www.ti.com/lit/ds/symlink/tps25947.pdf

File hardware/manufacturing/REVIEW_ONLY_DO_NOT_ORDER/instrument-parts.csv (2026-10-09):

Quantity per instrument | Quantity for five instruments | Category | Manufacturer | Part | Status | Assembly scope
1 | 5 | Controller | Raspberry Pi | Pico H SC0917 | Selected prototype candidate; male/socket engagement untested | Factory temporary insertion, programming and test; removable shipping arrangement agreed
10 | 50 | Touch modules | HiLetgo | TTP223-BA6 reference 1915450 | User supplied 24x24x7.2 body; actual revision and header termination pending | Factory fixture mounting and adapted module cables
2 | 10 | Buzzer modules | SunFounder | ST0238 | Selected; 32x14 outline verified; height/header engagement pending | Factory fixture mounting and adapted module cables
1 | 5 | Holder | MPD | BH-18650-W | Protected button-top 18650 candidate; exact-cell fit/contact ampacity pending | Included factory 24AWG TR64 leads 150+/-5mm each; factory PH termination and strain relief
1 | 5 | Battery plug housing | JST | PHR-2 | Matched to carrier H1; completed harness polarity test required | Factory termination of included holder leads
2 | 10 | Battery contacts | JST | SPH-002T-P0.5S | AWG24 conductor matches; measure lead insulation OD against 0.8-1.5mm and qualify exact crimp process | Factory lead preparation/crimp inspection/polarity test
Included with holder | Included with 5 holders | Battery leads | MPD | Two factory 24AWG TR64 leads 150+/-5mm each | No separate-wire allocation; actual OD/crimp and dressed length pending | Factory re-prepares stripped ends to JST process; strain relief; any extension needs review
12 | 60 | Module cable housings | Harwin | M20-1060300 | Verified carrier-end candidate; unkeyed orientation control required | Factory twelve 3-wire carrier connectors
36 | 180 | Module cable contacts | Harwin | M20-1180046 | Verified AWG26-compatible loose tin contact | Factory crimp qualification and harness continuity
3.60 m | 18.00 m, before scrap | Module cable wire | Assembler specification | AWG26 white red black stranded | 100mm per conductor engineering allowance; not measured installed length | Factory twelve adapted module cables
4 | 20 | Cassette bolts | Essentra | 50M030050P012 | Verified M3x12 nylon dimensional candidate | Factory mechanical assembly
4 | 20 | Cassette nuts | Essentra | 04M030050HNDIN34814 | Verified M3 nylon dimensional candidate | Factory mechanical assembly
8 | 40 | Cassette washers | Essentra | MFW030A | Verified ID3.2 OD7 thickness0.5 nylon | Factory mechanical assembly
4 | 20 | Cassette spacers | Essentra | 13ME036 | Verified ID3.2 OD8 length3 nylon | Factory mechanical assembly
1 | 5 | Cassette | Custom | Insulating BH-18650-W cassette | Proposed 112x36x44 and >=47mm supports; H1 integration verified in root806457b; final measured CAD pending | Factory mechanical subassembly after fit and loaded-clearance validation
1 | 5 | Module fixture | Custom | Raised insulating module fixture | Dimensioned proposal pending final actual-part fit | Factory mechanical subassembly after fit validation
1 | 5 | Cell | Keeppower | P1835J standard opposite-end button-top version | Confirm delivered terminal variant/current-lot limits; holder fit and matched charging qualification held | Separate protected cell; user insertion only after per-unit electrical and cell-release gate
Shared accessory; not one per instrument | 1 shared set proposed; HOLD | External charger | Keeppower | L1 at initial 500mA qualification setting | Compatibility HOLD; 4.2V+/-1% exceeds unqualified 4.20V cell maximum; bay/termination/temperature evidence pending; shared-set quantity is a quote assumption, not an approved pairing | Separate external charger after accepted pairing; no onboard charging
9 | 45 | Fixture bolts | Essentra | 50M030050P035 | Verified M3x35 nylon dimensional candidate | Factory fixture assembly
9 | 45 | Fixture nuts | Essentra | 04M030050HNDIN34814 | Verified M3 nylon dimensional candidate | Factory fixture assembly
18 | 90 | Fixture washers | Essentra | MFW030A | Verified ID3.2 OD7 thickness0.5 nylon | Factory fixture assembly
9 | 45 | Fixture spacers | Custom | Acetal OD8 ID3.2 length24mm | Engineering proposal; final height by fit | Factory custom machining and assembly
24 | 120 | Keeper bolts | Essentra | 50M020040P010 | Verified M2x10 nylon dimensional candidate | Factory module retention
24 | 120 | Keeper nuts | Essentra | 04M020040HN | Verified M2 nylon dimensional candidate | Factory module retention
48 | 240 | Keeper washers | Essentra | MFW010A | Verified ID2.2 OD5 thickness0.3 nylon | Factory module retention
24 | 120 | Module keepers | Custom | Stepped insulating keeper | 20 touch and4 buzzer; pedestal thickness measured per module lot | Factory custom machining and assembly
4 | 20 | Corner support feet | Custom | Insulating supports at corner holes | Engineering reservation >=47mm below underside; final loaded clearance/fasteners/enclosure pending | Factory mechanical assembly; cell must carry no playing load
Shared accessory; not one per instrument | 1 shared set proposed; HOLD | Charger input supply/cable | To be selected | Suitable 5V 1A input supply and matching cable | Exact SKU/revision pending accepted L1 revision and PM accessory distribution; shared-set quantity is a quote assumption, not an approved pairing | Separate accepted charger accessory; include in quote

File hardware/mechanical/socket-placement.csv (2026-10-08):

socket | socket_pad | pico_physical_pin | pico_function | carrier_net | x_mm | y_mm | footprint_rotation_deg
J1 | 1 | 1 | GP0 | GP0 | 111.11 | 1.30 | 0
J1 | 2 | 2 | GP1 | GP1 | 111.11 | 3.84 | 0
J1 | 3 | 3 | GND | GND | 111.11 | 6.38 | 0
J1 | 4 | 4 | GP2 | GP2 | 111.11 | 8.92 | 0
J1 | 5 | 5 | GP3 | GP3 | 111.11 | 11.46 | 0
J1 | 6 | 6 | GP4 | GP4 | 111.11 | 14.00 | 0
J1 | 7 | 7 | GP5 | GP5 | 111.11 | 16.54 | 0
J1 | 8 | 8 | GND | GND | 111.11 | 19.08 | 0
J1 | 9 | 9 | GP6 | GP6 | 111.11 | 21.62 | 0
J1 | 10 | 10 | GP7 | GP7 | 111.11 | 24.16 | 0
J1 | 11 | 11 | GP8 | GP8 | 111.11 | 26.70 | 0
J1 | 12 | 12 | GP9 | GP9 | 111.11 | 29.24 | 0
J1 | 13 | 13 | GND | GND | 111.11 | 31.78 | 0
J1 | 14 | 14 | GP10 | GP10 | 111.11 | 34.32 | 0
J1 | 15 | 15 | GP11 | GP11 | 111.11 | 36.86 | 0
J1 | 16 | 16 | GP12 | GP12 | 111.11 | 39.40 | 0
J1 | 17 | 17 | GP13 | GP13 | 111.11 | 41.94 | 0
J1 | 18 | 18 | GND | GND | 111.11 | 44.48 | 0
J1 | 19 | 19 | GP14 | GP14 | 111.11 | 47.02 | 0
J1 | 20 | 20 | GP15 | GP15 | 111.11 | 49.56 | 0
J2 | 1 | 21 | GP16 | GP16 | 128.89 | 49.56 | 180
J2 | 2 | 22 | GP17 | GP17 | 128.89 | 47.02 | 180
J2 | 3 | 23 | GND | GND | 128.89 | 44.48 | 180
J2 | 4 | 24 | GP18 | GP18 | 128.89 | 41.94 | 180
J2 | 5 | 25 | GP19 | GP19 | 128.89 | 39.40 | 180
J2 | 6 | 26 | GP20 | GP20 | 128.89 | 36.86 | 180
J2 | 7 | 27 | GP21 | GP21 | 128.89 | 34.32 | 180
J2 | 8 | 28 | GND | GND | 128.89 | 31.78 | 180
J2 | 9 | 29 | GP22 | GP22 | 128.89 | 29.24 | 180
J2 | 10 | 30 | RUN | NC | 128.89 | 26.70 | 180
J2 | 11 | 31 | GP26 | GP26 | 128.89 | 24.16 | 180
J2 | 12 | 32 | GP27 | GP27 | 128.89 | 21.62 | 180
J2 | 13 | 33 | AGND | GND | 128.89 | 19.08 | 180
J2 | 14 | 34 | GP28 | GP28 | 128.89 | 16.54 | 180
J2 | 15 | 35 | ADC_VREF | NC | 128.89 | 14.00 | 180
J2 | 16 | 36 | 3V3(OUT) | 3V3_OUT | 128.89 | 11.46 | 180
J2 | 17 | 37 | 3V3_EN | NC | 128.89 | 8.92 | 180
J2 | 18 | 38 | GND | GND | 128.89 | 6.38 | 180
J2 | 19 | 39 | VSYS | VSYS | 128.89 | 3.84 | 180
J2 | 20 | 40 | VBUS | VBUS_USB | 128.89 | 1.30 | 180

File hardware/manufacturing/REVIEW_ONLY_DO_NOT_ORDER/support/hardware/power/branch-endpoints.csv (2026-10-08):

reference | pin | carrier_net
H1 | 1 | BAT_PROT_PLUS
H1 | 2 | GND
F1 | 1 | BAT_PROT_PLUS
F1 | 2 | BAT_FUSED_PLUS
S1 | 1 | NC
S1 | 2 | BAT_FUSED_PLUS
S1 | 3 | BAT_SW_PLUS
U2 | 1 | EN_UVLO
U2 | 2 | OVLO
U2 | 3 | NC
U2 | 4 | GND
U2 | 5 | BAT_SW_PLUS
U2 | 6 | VSYS
U2 | 7 | DVDT
U2 | 8 | GND
U2 | 9 | ILM
U2 | 10 | NC
R1 | 1 | BAT_SW_PLUS
R1 | 2 | EN_UVLO
R2 | 1 | EN_UVLO
R2 | 2 | GND
R3 | 1 | BAT_SW_PLUS
R3 | 2 | OVLO
R4 | 1 | OVLO
R4 | 2 | GND
R5 | 1 | ILM
R5 | 2 | GND
R6 | 1 | DVDT
R6 | 2 | DVDT_CAP
C1 | 1 | BAT_SW_PLUS
C1 | 2 | GND
C2 | 1 | VSYS
C2 | 2 | GND
C4 | 1 | VSYS
C4 | 2 | GND
C3 | 1 | DVDT_CAP
C3 | 2 | GND
D2 | 1 | VSYS
D2 | 2 | GND
D3 | 1 | BAT_SW_PLUS
D3 | 2 | GND

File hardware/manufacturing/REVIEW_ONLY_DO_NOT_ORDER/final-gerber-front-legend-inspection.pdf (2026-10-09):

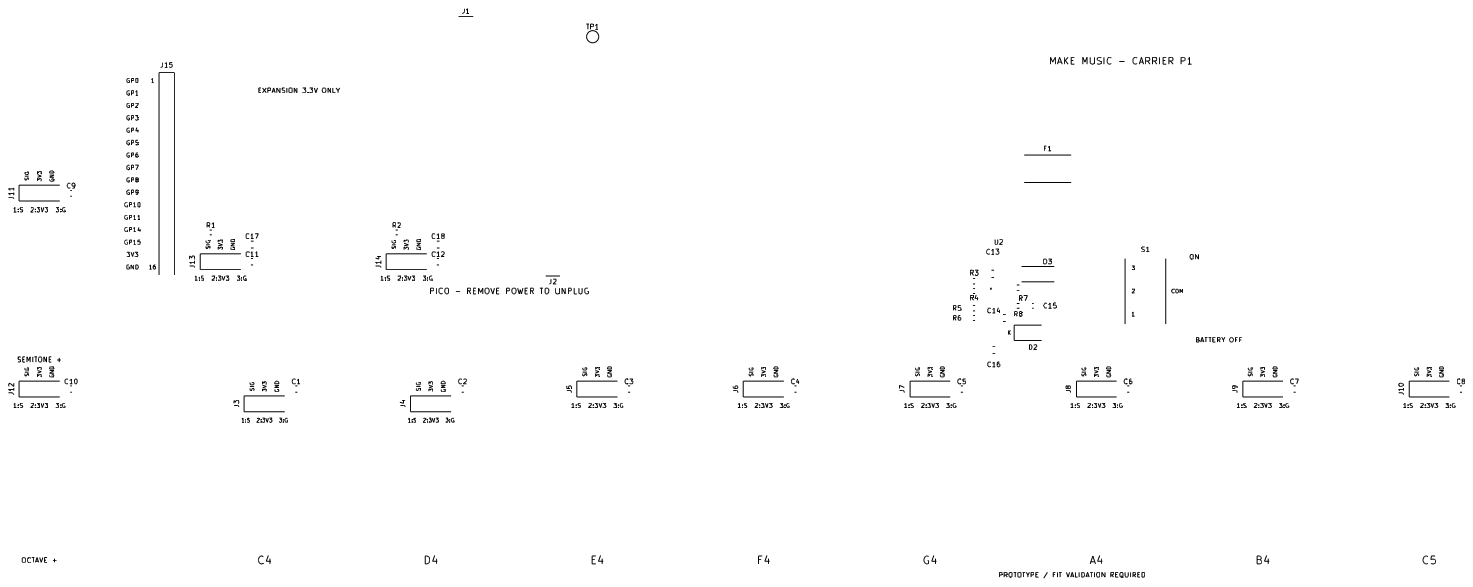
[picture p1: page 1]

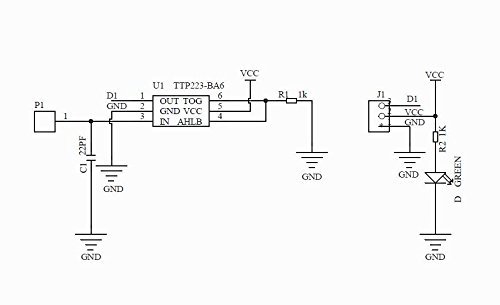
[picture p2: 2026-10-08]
hardware/manufacturing/REVIEW_ONLY_DO_NOT_ORDER/support/hardware/components/reference/touchbutton.jpg

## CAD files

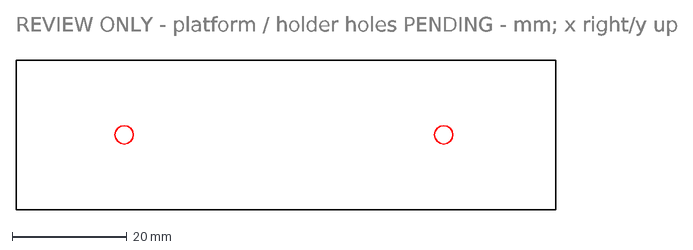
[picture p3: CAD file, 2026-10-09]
hardware/manufacturing/REVIEW_ONLY_DO_NOT_ORDER/support/hardware/mechanical/cassette-platform-review.dxf
REVIEW ONLY - platform / holder holes PENDING - mm; x right/y up

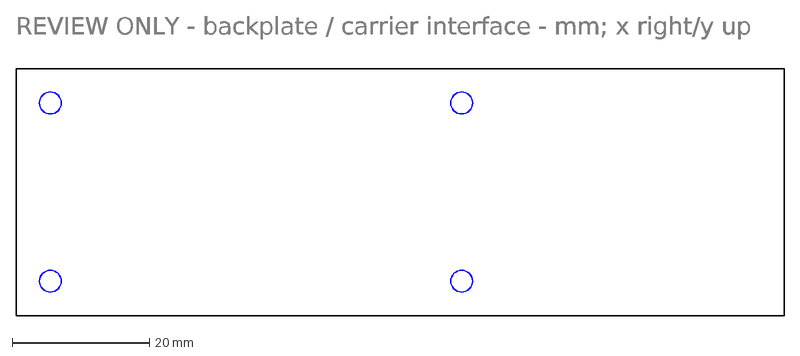
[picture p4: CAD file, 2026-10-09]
hardware/manufacturing/REVIEW_ONLY_DO_NOT_ORDER/support/hardware/mechanical/cassette-backplate-review.dxf
REVIEW ONLY - backplate / carrier interface - mm; x right/y up

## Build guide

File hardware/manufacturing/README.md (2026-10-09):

# Regenerating the held PCBWay review package

All native CAD changes, saves, zone refills, checks and CAD exports go through
Konnect MCP. Ordinary Python only packages exported evidence. The retired
`export_review.py` refuses to run: its auxiliary-origin outputs and socket
MPN substitutions must not be mixed with the new native exports.

**Current source work must pass review before regeneration.** A stale checked-in
directory is not a passing result for the current sources. Keep outputs marked
REVIEW ONLY — DO NOT ORDER until actual fit, bench and supplier process gates
are satisfied. No script here uploads files or grants release.

## Export sequence

1. Bind the exact board in KiCad over IPC. Read each mutation response and
   saved/live readback. Resolve all electrical/layout/parity findings; preserve
   unavailable-check information and any explicitly reviewed exceptions.
2. Through Konnect, run root ERC at all severities; run PCB DRC at `info` with
   `sync_live_board=true` and `refill_zones=true`. Inspect full coverage and
   source evidence. Export a fresh native XML netlist and run
   `kicad/verify_connectivity.py`. Independently compare live pad nets, values,
   library IDs and symbol identities against that export.
3. After the saved/refilled checks, record a fresh source hash checkpoint:
   `python3 capture_review_sources.py /temporary/new/source-checkpoint.json`.
   Do not mutate CAD or libraries during the following export/package stage.
4. Use Konnect `export_manufacturing_package` with `fab_house="pcbway"`,
   eight layers F.Cu/B.Cu/F.Paste/F.Mask/B.Mask/F.SilkS/B.SilkS/Edge.Cuts,
   assembly included, both position sides, millimeter units, native MPN field
   and quantities. Use a **new output directory**. Inspect every emitted file
   and warning; source hashes alone cannot prove an export succeeded.
5. Through Konnect export both-sheet schematic PDF, top/bottom assembly and
   copper PDFs/SVGs. Verify drawing orientation and visual content. An
   IPC-2581 XML is supplemental; it is not IPC-D-356. The installed
   `export_netlist(format="ipc")` fails and must not be reported as produced.
6. Run `prepare_pcbway_review.py NATIVE_DIR NETLIST_XML ERC_MCP_JSON
   DRC_MCP_JSON NEW_OUTPUT_DIR --source-snapshot SOURCE_CHECKPOINT_JSON
   --electrical-evidence SOURCE_BOUND_EVIDENCE_DIR`.
   Inputs are the complete MCP result files, not stdout summaries. This checks
   sources stayed unchanged, native origin agreement and BOM/placement identity.
   It produces exact per-reference BOM, grouped five-unit BOM, SMT-only centroid,
   separate manual THT positions, copied evidence and SHA-256 manifest. Grouping
   includes the functional Value so a connector group cannot inherit another
   reference's function. It also bundles the quote draft and supporting review
   documents/assets under support/, rebasing relative links within the package.
7. Inspect actual Gerbers and both drill sets in a local viewer, inspect
   placements/rotation/polarity and render every final PDF. Confirm all managed
   outputs are nonempty and hashes agree. Only then replace the old held
   directory as a complete revision, preserving its hold status. Commit the
   reviewed sources and regenerated package together via a PR.

The postprocessor requires source-bound live pad/identity evidence and retains
the exact four reviewed Konnect custom-field warnings from the current PCB.
It refuses other findings, wrong connections, mismatched evidence or stale
sources before creating output. The real 47-part/30-SMT/17-THT pipeline passed;
wrong-net, unreviewed-warning and stale-source negative cases refused. Overall
DRC remains four warnings in the manifest; no DRC rule or result is suppressed.
This electrical review does not grant fabrication release.

The postprocessor also compares every purchased placement with the verified
live IPC inventory: exact references/coverage, side/value/package, X, negated
native Y and rotation modulo360. Six-decimal native exports use a tolerance
of1e-6 mm/degrees; nonfinite coordinates/angles are rejected. This runs before
output creation, so a reversed U2 or displaced non-anchor component cannot
enter the centroid under otherwise valid electrical evidence. Run
`python3 -m unittest discover -s hardware/manufacturing -p test_prepare_pcbway_review.py`.

PM confirmed the final rear edge at native y18.5: machine board corners are
(20,-18.5)..(350,-140) mm, 330×121.5 mm. The strict origin guard rejects both
the superseded y20 and interim y19 edge exports. Placements, native(0,0)
position origin and service datums remain fixed. Fresh source-bound checks and
exports are required after a CAD change; do not reuse or alter806457b
source hashes to force a pass. The final pipeline passes against current
21b2108 native sources and rear-edge-20261009 evidence. Later document/BOM
presentation changes regenerate the ordinary package and manifest while retaining
identical source-bound native Gerber/drill/position/drawing payloads.

## Coordinate and assembly convention

Served native exports use (0,0), x right/y up; board (20,-18.5)..(350,-140) mm.
The mechanical proposal retains service datum native(20,20), x/y down
(the new physical rear edge is service y=-1.5): machine x=x_mechanical+20,
machine y=-(y_mechanical+20). J3=(87.46,-98), J4=(121.46,-98),
H1=(289,-40) mm in the revised placement file. Do not translate Gerbers,
drills or positions independently. The older held package uses a different
bottom-left origin and is obsolete once new sources change.

Expected purchased carrier scope is 47 parts: 30 top SMT and 17 THT. H1 is
bottom THT. TP1 and 17 mounting holes are bare-board features. The complete
instrument additionally needs the Pico, modules, harnesses, holder/cell and
mechanical assembly in `assembly/PCBWAY_HANDOFF.md`.

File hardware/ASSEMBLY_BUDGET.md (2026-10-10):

# Budget comparison for five complete instruments

Updated 2026-10-09. The selected scope is **five fully assembled Make Music
instruments**, plus an optional additional sixth bare carrier as a keepsake.
The battery is the long **protected 18650**, externally charged. The earlier
18350 name was a mistake. No complete quote, supplier acceptance or order exists.

## Compare the same five-unit design

| Route | Factory supplies | Work remaining outside the quote | Status |
|---|---|---|---|
| Five complete instruments | All 47 purchased carrier parts per board; 30 top SMT, 17 THT; twelve adapted module cables; ten touch/two passive buzzer modules; fixture, cassette, supports; Pico programming and specified testing | Removable cell insertion/external charging; unpacking or Pico insertion if agreed for shipping | **Selected quote scope**; assembly/metrology availability needs acceptance |
| Five fully populated carriers | PCB plus all47 purchased carrier parts supplied and soldered, including all30 SMT and17 THT parts | Picos, touch/buzzer modules, cells/charger, adapted harnesses, mechanical assembly, programming and final instrument tests | Main price comparison; assembled carrier is not a complete instrument |
| Five SMT-populated carriers | All 30 top SMT parts per board | Seventeen THT parts including sockets/headers/switch/bottom JST; 60 module harnesses and all mechanical work; Picos/modules/cells and final tests | Price comparison only; requires a capable assembler for the remainder |
| Five bare carriers | PCB fabrication only | Every chip, capacitor, resistor, diode, fuse, socket, header and switch must be soldered; all harness/mechanical work remains | Not selected; user does not want this task |
| One extra bare carrier | Additional unpopulated PCB | None if kept as a design souvenir | Optional sixth board, priced separately |

Carrier SMT is entirely on the top. H1 is bottom through-hole. Consequently,
quote one-side SMT plus accepted THT/manual operations; underside battery
mounting does not automatically mean a two-side SMT setup. The tiny eFuse
package is a good reason to retain factory SMT in either assembled route.

A normal PCBA quotation may stop at the populated carrier. Our
[complete handoff](assembly/PCBWAY_HANDOFF.md) explicitly requests harness
adaptation, module mounting, custom mechanical parts, precise first-article
measurements, programming and five-unit functional records. Any declined
operation must be named and priced through another assembler before calling
an option complete. There is no planned capacitor or header soldering by John.

## What the earlier $67.54 represented

[JLCPCB's published fee table](https://jlcpcb.com/help/article/pcb-assembly-price),
checked 2026-10-09, lists these examples in USD. They are batch setup/stencil
fees from another supplier, **not a PCBWay quote or a complete-project budget**.

| Category | Setup | Stencil | Combined per batch | Combined / five units |
|---|---:|---:|---:|---:|
| Economic PCBA | $8.18 | $1.53 | $9.71 | $1.94 |
| Standard one side | $25.56 | $8.21 | $33.77 | $6.75 |
| Standard two sides | $51.12 | $16.42 | $67.54 | $13.51 |

That table also separately lists parts, feeder loading, manual assembly,
handling, fixtures and other fees. Board size/service eligibility and final
pricing require a real quote. None of the three combined figures includes
PCB fabrication, components, module/Pico/battery/charger sourcing, custom
fixtures, wire assemblies, metrology, programming/testing, shipping or tax.
Do not use $67.54 as the price for five assembled instruments.

## Quote worksheet

The main quote compares five complete instruments, five fully populated
carriers and five bare carriers using one board design. These are alternatives,
not a fifteen-board order. Request the optional sixth bare keepsake separately.
The table below also supports an additional SMT-only breakdown. For a fully
populated carrier, include both SMT and THT parts/labor, then explicitly exclude
the remaining external instrument items and tests.

Obtain the following itemized lines:

| Cost line | Complete five | SMT-only five | Evidence needed |
|---|---|---|---|
| Five 330 × 121.5 mm, two-layer carriers | Pending | Pending | Accepted stackup, finish, panel rails and process |
| SMT setup/stencil/parts/labor | Pending | Pending | Exact MPN BOM, 30 SMT/board, U2 stencil and C17/C18 lands |
| THT parts/labor | Pending | Excluded or separately priced | 17 THT/board, bottom H1, socket fit/edge handling |
| Ten ST0238 + fifty exact touch modules | Pending | Separate | Delivered revision, stock and module-end geometry |
| Five Pico H SC0917 | Pending | Separate | Original Pico H; other models deferred |
| Sixty module harnesses + five battery harnesses | Pending | Separate | Qualified crimps, adapted ends, measured lengths |
| Five holder/cassette/fixture/support sets | Pending | Separate | MPD BH-18650-W and final measured mechanical CAD |
| Five protected 18650 cells + one proposed shared charger/input set | Pending | Separate | Exact button-top opposite-end cell lot, fit and charging tolerance; shared quantity assumption HOLD |
| First-article metrology/qualification | Pending | Separate | Fit and current-limited bench record |
| Programming and all-five functional testing | Pending | Separate | Accepted firmware and per-unit records |
| Shipping/tax | Pending | Pending | Battery shipping and delivery terms |
| Optional sixth bare keepsake | Additional line | Additional line | Adds one fabricated unpopulated carrier |

`complete batch total = sum of accepted complete-five lines`

`SMT-only finished batch total = SMT quote + all separately completed lines`

Divide the complete total by five only after all required lines are included.
The difference measures the price of outsourcing the remaining work; it is
not a savings if that work is simply omitted. Fixed fixture/metrology costs
can dominate a small first run. A first-article checkpoint within the five-unit
order reduces the chance of repeating an unverified fit in all five units.

PCBWay describes [through-hole assembly](https://www.pcbway.com/pcb_prototype/Through_Hole_Assembly.html)
and [turnkey/consigned sourcing](https://www.pcbway.com/quotesmt.aspx).
Those services do not establish acceptance of our custom instrument assembly.
This worksheet alone authorizes no action. On October9,2026 the owner separately
authorized a final team review followed by PCBWay uploads/contact solely for
conditional quotation. No purchase or fabrication release is authorized;
release still requires the named fit/process evidence and separate approval.

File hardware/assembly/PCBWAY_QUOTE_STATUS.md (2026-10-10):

# PCBWay conditional quote status

Prepared October 9, 2026. **Quotation only; no fabrication or purchase release.**
The owner authorized a final team review and PCBWay quotation submission.
[Final review](../review/prequote-20261009/README.md) accepts conditional pricing.

Requested alternative scopes for the same physical design:

- A: five bare carriers.
- B: five carriers with all47 purchased parts each supplied and soldered,
  including all30 SMT and17 THT parts.
- C: five complete instruments, including engineering/metrology, final
  mechanical work, harnesses, programming and tests. This is the preferred scope.
- Optional additional sixth bare keepsake, separately priced.

These alternatives do not authorize an order for fifteen boards. Exact-part
fit, cell/charger qualification, final mechanics, process acceptance and tests
remain held; see [full quote request](QUOTE_REQUEST.md).

## Current transmission state

**SENT and confirmed in PCBWay Message History on October9,2026 at8:40:22 p.m.
America/Chicago** (site displays October10,09:40:22 China time). The1759-character
RFQ went once to the account's assigned representative, Cici. Email reply was
selected. An itemized A/B/C quotation is pending; receipt does not establish that
the representative has read or accepted the engineering scope.

The signed-in online assembly form produced an indicative estimate but did not
save a cart entry. No cart-based submission or order number exists. The message
center was used instead. Browser file upload required a permission not enabled;
no attachment was uploaded. The RFQ supplied exact revision-pinned public links
to the reviewed packet and repository ZIP, with instructions to use only
`hardware/manufacturing/REVIEW_ONLY_DO_NOT_ORDER`:

- [Exact reviewed packet](https://github.com/John-ODell/Make_Music/tree/0d6191a0e0217e7140bbceed22aa4e59db78747e/hardware/manufacturing/REVIEW_ONLY_DO_NOT_ORDER)
- [Exact revision download](https://github.com/John-ODell/Make_Music/archive/0d6191a0e0217e7140bbceed22aa4e59db78747e.zip)

The packet was pushed and integrated through
[PR37](https://github.com/John-ODell/Make_Music/pull/37), merge
bc986a28121235c059e4859eb6203bb539a0c00a. GitHub's content API confirmed the
specified committed packet directory exists. Native CAD and exports unchanged.
The sent-message screenshot and exact RFQ text are local operational records
in `output/pcbway-quote-20261009/`; no account/session data is committed here.
Chrome permissions need not be changed for this completed link-based RFQ.

No payment, fabrication, first-article build or production release was approved.

The web calculator showed $97.80 PCB fabrication, $29 assembly service,
$40.28 estimated US/DHL shipping and a $30 promotion, yielding $137.08.
This excludes component purchasing, custom services/engineering and duties/tax;
it is **not the price of five complete instruments** and is subject to review.

## Exact prepared attachments — not transmitted

Both files are in `output/pcbway-quote-20261009/`. Each is below the message
center's1MB limit. Extract both into one folder; their disjoint contents cover
the109 hashed outputs plus manifest. Every decompressed payload matches the
reviewed full packet byte-for-byte.

| File | Bytes | Files | SHA256 |
|---|---:|---:|---|
| MakeMusic_Quote_Core_DO_NOT_FABRICATE.zip |959587|33|4a7e79b52dc5717e9446ccdbbf5e90967dc73be3662cd751dabbb3b1a34e3024|
| MakeMusic_Quote_Support_DO_NOT_FABRICATE.zip |225854|77|b9ba53f1cb3e2ab6bf4c8f4b2a81bf21e95f29bd9661d178598f0ce208df94a9|

No credentials, account identifiers or personal contact details belong in this
public repository. Browser receipts/screenshots remain local operational files.

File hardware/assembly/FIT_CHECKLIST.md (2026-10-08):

# Exact parts needed to finish physical verification

The native electrical project is routed and checked. The following measurements determine whether its proposed mechanical assembly can be finalized. All result fields remain blank because no parts were measured or energized during design. Do these checks with the battery removed and USB disconnected.

| Item | Record from actual selected parts | Pass requirement | Result |
|---|---|---|---|
| Keeppower P1835C2 + Keystone 1101 | Cell overall length/diameter/button; holder insertion travel, contact compression, wrapper clearance and retention | Inserts/removes without force or wrapper damage; reliable contacts and retention; protected cell not bypassed | Pending |
| External charger | Exact L1 revision/bay fit and selected 500 mA charge setting against cell specification | Fits protected cell and charges within its documented limits | Pending |
| Pico H SC0917 + two SSQ-120-01-G-S | Male post dimensions/projection, socket engagement and body height | Both rows fully mate at 17.78 mm spacing without bottoming; USB/BOOTSEL and upward removal remain accessible | Pending |
| Ten actual HiLetgo touch modules | Width/length/thickness, header type/order/orientation, top/bottom component projection, electrode and bare edge support regions | Proposed 24 mm seats and insulating tabs/keepers avoid all circuitry/electrodes; modify fixture seats when necessary | Pending |
| Two actual ST0238 modules | Width/length/thickness, component/buzzer height, header termination and labels, clear support lands/sound opening | Proposed 32 × 14 mm seats fit; keepers avoid circuitry and sound opening | Pending |
| Module cables | Exact module-end mating/solder method and polarity; dressed length/service slack and strain relief | Each adapted lead maps carrier 1 SIG /2 3V3 /3 GND to the actual module labels; no pinching or bare conductors | Pending |
| Raised fixture | Mated carrier header height, module underside projection, screw tips, wires and loaded plate deflection | At least 2 mm actual remaining clearance including tolerance and deflection; proposed 24 mm spacers/28 mm support plane are adjustable | Pending |
| Holder cassette/support | Holder lug insulation/strain relief, cover/door access, connector plug/bend space and actual cassette height | Cell and holder carry no playing load; proposed ≥35 mm underside support clears the 32 mm cassette | Pending |
| NKK MN12SS1W03 | Exact switch case, travel/actuator/panel fit and finished carrier hole fit | Clears assembly and operates without stressing terminals; idle contact/load endurance checked during bench test | Pending |
| Full paper fit | Proposed 330 × 120 mm outline, 34 mm note pitch, 10 mm body gaps and left modifiers | Comfortable reach and agreed size with actual module bodies before fabrication release | Pending |

The module fixture avoids undocumented module mounting holes. That permits carrier routing now, but does not establish that unknown module edge regions are suitable for clamping. Do not drill the modules or force them into the proposal. See [fixture geometry](../mechanical/MODULE_FIXTURE.md) and [holder cassette](../mechanical/WIRED_HOLDER_PROPOSAL.md). Custom fixture, keepers, cassette door and support feet still require final manufacturing CAD/tolerances after measurement.

After mechanical fit passes, follow the [staged current-limited power and functional procedure](../power/prototype-validation.md). Record module idle/touched logic and direct/momentary configuration; firmware can adapt polarity. Measure sound/current, battery branch/load response, USB/battery isolation, UVLO/restart, fault reset and temperature. Adopted limits are 0.70 A normal battery branch, 350 mA total 3V3 including Pico and 250 mA external 3V3; they are design limits, not measured performance. Holder/contact ampacity and effective ceramic capacitance also need qualification.

An assembler may perform metrology, fit and electrical tests as a priced service. The factory preference includes soldering, crimping and mechanical attachment; user steps are final removable Pico/cell insertion and firmware loading. These checks are not silently assigned to a first-time PCB builder. No complete quote or supplier acceptance exists yet.

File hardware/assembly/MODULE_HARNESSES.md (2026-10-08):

# Twelve module cable assemblies — carrier end specified

Updated 2026-10-08. Factory scope includes the cables and module attachment; Pico and protected cell remain removable user insertions. This specification resolves the carrier connector end. Module end geometry and installed cable length require an actual-part fit check. No cables were purchased or assembled.

## Carrier connector and conductors

For each of J3–J14 use one Harwin **M20-1060300** 3-position female housing with three **M20-1180046** tin-finish loose crimp contacts. Twelve carrier ends require **12 housings and 36 contacts**. These mate to the selected 0.64 mm square male contacts at 2.54 mm pitch. Use flexible stranded **AWG26** wire, insulation outside diameter no greater than the contact/tool's 1.7 mm allowance. Carrier assignment is cavity1 signal (white), cavity2 regulated 3V3 (red), cavity3 GND (black). Colors are assembly aids; verify continuity by cavity number.

Engineering cut-length allowance is **100 mm per conductor**, 36 conductors / 3.6 m total before process scrap. This is an initial allowance, not measured installed length. Adjust in the fixture mock-up to leave service slack without crossing touch faces, buzzer openings, Pico USB/BOOTSEL/removal access, switch travel or the battery cassette. Secure the cable to the fixture independently of contact friction; keep all wire ends insulated.

The housing is unkeyed on our unshrouded carrier header. Mark its signal end and align it with the square pad / pin1 label. Add a visible orientation mark to the assembled harness, and inspect all three circuits before power. A three-position plug can still be reversed or shifted; retention/orientation control is part of the fixture trial.

Harwin's manufacturer pages specify the mating contact size, housing family and contact AWG range. The IS-15 crimp-tool sheet specifies 4.0 mm maximum stripping length, 1.7 mm maximum wire diameter and **18 N minimum pull-off force for AWG26**. Use suitable production tooling/process; do not apply a destructive qualification pull to every installed board contact. Assembler validates the crimp process and contact retention on representative samples.

## End-to-end mapping

| Carrier | Function | Signal destination |
|---|---|---|
| J3 | C4 / GP16 | Touch DI/OUT |
| J4 | D4 / GP17 | Touch DI/OUT |
| J5 | E4 / GP18 | Touch DI/OUT |
| J6 | F4 / GP19 | Touch DI/OUT |
| J7 | G4 / GP20 | Touch DI/OUT |
| J8 | A4 / GP21 | Touch DI/OUT |
| J9 | B4 / GP22 | Touch DI/OUT |
| J10 | C5 / GP26 | Touch DI/OUT |
| J11 | Semitone / GP27 | Touch DI/OUT |
| J12 | Octave / GP28 | Touch DI/OUT |
| J13 | Buzzer1 / GP13 | ST0238 I/O |
| J14 | Buzzer2 / GP12 | ST0238 I/O |

Every red conductor goes to the module's verified VCC; every black conductor goes to its verified GND. The official ST0238 photo shows GND, I/O, VCC top-to-bottom with buzzer left / contacts right. Therefore its cable is permuted relative to carrier SIG, 3V3, GND. Do not specify a universal straight-through cable. See [carrier interface evidence](../kicad/carrier-interfaces.md).

Module-end socket MPN cannot be frozen until the delivered header pitch, contact section, engagement length, pin order and connector access are measured. If a module lacks the anticipated male header, prepare a drawing for that termination before assembly. The factory must source or receive the exact module revision and build/inspect the adapted cable; this remaining work is not assigned to the user as unannounced soldering.

## Inspection record

With no battery, USB, Pico or modules connected, verify each harness's signal/VCC/GND continuity and absence of cross-shorts, orientation marks and strain relief. Verify the carrier labels against the schematic and the module labels against the delivered revision. Complete module polarity/momentary-output checks on a current-limited 3.3 V supply before plugging into Pico GPIO. Record actual cable lengths and connector revisions in the assembly traveler.

Battery wiring uses a separate keyed JST-PH harness, **AWG24**, with the project's own positive/ground cavity convention; do not mix it with these 3.3 V module cables. See [battery cassette/harness specification](../mechanical/WIRED_HOLDER_PROPOSAL.md).

## Primary sources checked 2026-10-08

- [Harwin M20-1060300](https://www.harwin.com/products/M20-1060300): 3-way housing, mating 0.64 mm square pins, compatible contacts.
- [Harwin M20-1180046](https://www.harwin.com/products/M20-1180046): loose tin female contact, AWG22–30, M20-106 family.
- [Harwin IS-15, issue8](https://www.harwin.com/api/download/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): strip/insulation/pull-force data.

Ratings do not verify the assembled module-end fit, cable life or polarity. Those named physical checks remain open.

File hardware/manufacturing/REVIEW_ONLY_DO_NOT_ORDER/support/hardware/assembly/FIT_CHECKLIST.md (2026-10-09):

# Exact parts needed to finish physical verification

The native capacitor/18650 integration and source-bound electrical/export reviews are complete; see current PCB status for exact coverage and retained metadata warnings. The following measurements determine whether its proposed mechanical assembly can be finalized. All result fields remain blank because no parts were measured or energized during design. Do these checks with the battery removed and USB disconnected.

| Item | Record from actual selected parts | Pass requirement | Result |
|---|---|---|---|
| Keeppower P1835J + MPD BH-18650-W | Confirm ordinary opposite-end terminals/lot; cell overall length/diameter; holder insertion travel, contact compression, wrapper clearance and retention | Inserts/removes without force or wrapper damage; reliable contacts and retention; protected cell not bypassed | Pending |
| External charger | Exact revision/bay fit, CC/CV tolerances, termination and charge-current setting against current cell-lot specification | Fits protected cell and charges within its documented limits; L1 remains held for the 4.242V upper-tolerance conflict | Pending |
| Pico H SC0917 + two SSQ-120-01-G-S | Male post dimensions/projection, socket engagement and body height | Both rows fully mate at 17.78 mm spacing without bottoming; USB/BOOTSEL and upward removal remain accessible | Pending |
| Ten actual HiLetgo touch modules | Width/length/thickness, header type/order/orientation, top/bottom component projection, electrode and bare edge support regions | Proposed 24 mm seats and insulating tabs/keepers avoid all circuitry/electrodes; modify fixture seats when necessary | Pending |
| Two actual ST0238 modules | Width/length/thickness, component/buzzer height, header termination and labels, clear support lands/sound opening | Proposed 32 × 14 mm seats fit; keepers avoid circuitry and sound opening | Pending |
| Module cables | Exact module-end mating/solder method and polarity; dressed length/service slack and strain relief | Each adapted lead maps carrier 1 SIG /2 3V3 /3 GND to the actual module labels; no pinching or bare conductors | Pending |
| Raised fixture | Mated carrier header height, module underside projection, screw tips, wires and loaded plate deflection | At least 2 mm actual remaining clearance including tolerance and deflection; proposed 24 mm spacers/28 mm support plane are adjustable | Pending |
| Holder cassette/support | Factory AWG24 lead insulation OD/JST compatibility, strain relief, lowered platform/bolt tips, cover/door access, connector plug/bend space and actual loaded height | Cell/holder carry no playing load; proposed ≥47 mm supports clear 44 mm cassette with ≥2 mm fitted/loaded internal clearance | Pending |
| NKK MN12SS1W03 | Exact switch case, travel/actuator/panel fit and finished carrier hole fit | Clears assembly and operates without stressing terminals; idle contact/load endurance checked during bench test | Pending |
| Full paper fit | Proposed 330 × 121.5 mm outline, 34 mm note pitch, 10 mm body gaps and left modifiers | Comfortable reach and agreed size with actual module bodies before fabrication release | Pending |

The module fixture avoids undocumented module mounting holes. That permits carrier routing now, but does not establish that unknown module edge regions are suitable for clamping. Do not drill the modules or force them into the proposal. See [fixture geometry](../mechanical/MODULE_FIXTURE.md) and [holder cassette](../mechanical/WIRED_HOLDER_PROPOSAL.md). Custom fixture, keepers, cassette door and support feet still require final manufacturing CAD/tolerances after measurement.

After mechanical fit passes, follow the [staged current-limited power and functional procedure](../power/prototype-validation.md). Record module idle/touched logic and direct/momentary configuration; firmware can adapt polarity. Measure sound/current, battery branch/load response, USB/battery isolation, UVLO/restart, fault reset and temperature. Adopted limits are 0.70 A normal battery branch, 350 mA total 3V3 including Pico and 250 mA external 3V3; they are design limits, not measured performance. Holder/contact ampacity and effective ceramic capacitance also need qualification.

An assembler may perform metrology, fit and electrical tests as a priced service. The factory preference includes soldering, crimping and mechanical attachment; factory scope includes programming/testing; normal user steps are removable cell insertion/external charging and Pico insertion only if separately packed by agreement. These checks are not silently assigned to a first-time PCB builder. No complete quote or supplier acceptance exists yet.

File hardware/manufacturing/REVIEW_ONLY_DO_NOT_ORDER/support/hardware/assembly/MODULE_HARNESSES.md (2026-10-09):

# Twelve module cable assemblies — carrier end specified

Updated 2026-10-08. Factory scope includes the cables and module attachment; Pico and protected cell remain removable user insertions. This specification resolves the carrier connector end. Module end geometry and installed cable length require an actual-part fit check. No cables were purchased or assembled.

## Carrier connector and conductors

For each of J3–J14 use one Harwin **M20-1060300** 3-position female housing with three **M20-1180046** tin-finish loose crimp contacts. Twelve carrier ends require **12 housings and 36 contacts**, or **60 housings and 180 contacts for five instruments**. These mate to the selected 0.64 mm square male contacts at 2.54 mm pitch. Use flexible stranded **AWG26** wire with insulation outside diameter **0.9–1.6 mm**, the intersection of the exact contact drawing and tool allowance. Carrier assignment is cavity1 signal (white), cavity2 regulated 3V3 (red), cavity3 GND (black). Colors are assembly aids; verify continuity by cavity number.

Engineering cut-length allowance is **100 mm per conductor**, 36 conductors / 3.6 m total before process scrap. This is an initial allowance, not measured installed length. Adjust in the fixture mock-up to leave service slack without crossing touch faces, buzzer openings, Pico USB/BOOTSEL/removal access, switch travel or the battery cassette. Secure the cable to the fixture independently of contact friction; keep all wire ends insulated.

The housing is unkeyed on our unshrouded carrier header. Mark its signal end and align it with the square pad / pin1 label. Add a visible orientation mark to the assembled harness, and inspect all three circuits before power. A three-position plug can still be reversed or shifted; retention/orientation control is part of the fixture trial.

Harwin's manufacturer pages specify the mating contact size, housing family and contact AWG range. The IS-15 crimp-tool sheet specifies 4.0 mm maximum stripping length, 1.7 mm tool maximum wire diameter and **18 N minimum pull-off force for AWG26**. The exact contact drawing narrows the process to **3–4 mm strip and 0.9–1.6 mm insulation OD**. Use suitable production tooling/process; do not apply a destructive qualification pull to every installed board contact. Assembler validates the crimp process and contact retention on representative samples. The drawing is [Harwin M20-118, issue13](https://content.harwin.com/asset/d742d022-1905-41c8-b996-8feb2ed262c8/DRG-00379-Technical-Drawing-Datasheet-M20-118-pdf.pdf).

## End-to-end mapping

| Carrier | Function | Signal destination |
|---|---|---|
| J3 | C4 / GP16 | Touch DI/OUT |
| J4 | D4 / GP17 | Touch DI/OUT |
| J5 | E4 / GP18 | Touch DI/OUT |
| J6 | F4 / GP19 | Touch DI/OUT |
| J7 | G4 / GP20 | Touch DI/OUT |
| J8 | A4 / GP21 | Touch DI/OUT |
| J9 | B4 / GP22 | Touch DI/OUT |
| J10 | C5 / GP26 | Touch DI/OUT |
| J11 | Semitone / GP27 | Touch DI/OUT |
| J12 | Octave / GP28 | Touch DI/OUT |
| J13 | Buzzer1 / GP13 | ST0238 I/O |
| J14 | Buzzer2 / GP12 | ST0238 I/O |

Every red conductor goes to the module's verified VCC; every black conductor goes to its verified GND. The official ST0238 photo shows GND, I/O, VCC top-to-bottom with buzzer left / contacts right. Therefore its cable is permuted relative to carrier SIG, 3V3, GND. Do not specify a universal straight-through cable. See [carrier interface evidence](../kicad/carrier-interfaces.md).

Module-end socket MPN cannot be frozen until the delivered header pitch, contact section, engagement length, pin order and connector access are measured. If a module lacks the anticipated male header, prepare a drawing for that termination before assembly. The factory must source or receive the exact module revision and build/inspect the adapted cable; this remaining work is not assigned to the user as unannounced soldering.

## Inspection record

With no battery, USB, Pico or modules connected, verify each harness's signal/VCC/GND continuity and absence of cross-shorts, orientation marks and strain relief. Verify the carrier labels against the schematic and the module labels against the delivered revision. Complete module polarity/momentary-output checks on a current-limited 3.3 V supply before plugging into Pico GPIO. Record actual cable lengths and connector revisions in the assembly traveler.

Battery wiring uses a separate keyed JST-PH harness, **AWG24**, with the project's own positive/ground cavity convention; do not mix it with these 3.3 V module cables. See [battery cassette/harness specification](../mechanical/WIRED_HOLDER_PROPOSAL.md).

## Primary sources checked 2026-10-08

- [Harwin M20-1060300](https://www.harwin.com/products/M20-1060300): 3-way housing, mating 0.64 mm square pins, compatible contacts.
- [Harwin M20-1180046](https://www.harwin.com/products/M20-1180046): loose tin female contact, AWG22–30, M20-106 family.
- [Harwin IS-15, issue8](https://www.harwin.com/api/download/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): strip/insulation/pull-force data.

Ratings do not verify the assembled module-end fit, cable life or polarity. Those named physical checks remain open.

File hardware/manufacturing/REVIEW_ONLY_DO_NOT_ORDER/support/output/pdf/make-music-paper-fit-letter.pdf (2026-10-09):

## MAKE MUSIC / ACTUAL-SIZE PAPER FIT

Page 1 of 2 - board x=0 to 180 mm

Print on US Letter at 100% / Actual Size. Turn off Fit or Shrink.
Check BOTH scale bars before judging reach. Paper checks comfort only.

4 inches exactly - check with your tape measure

100 mm exactly - optional metric check

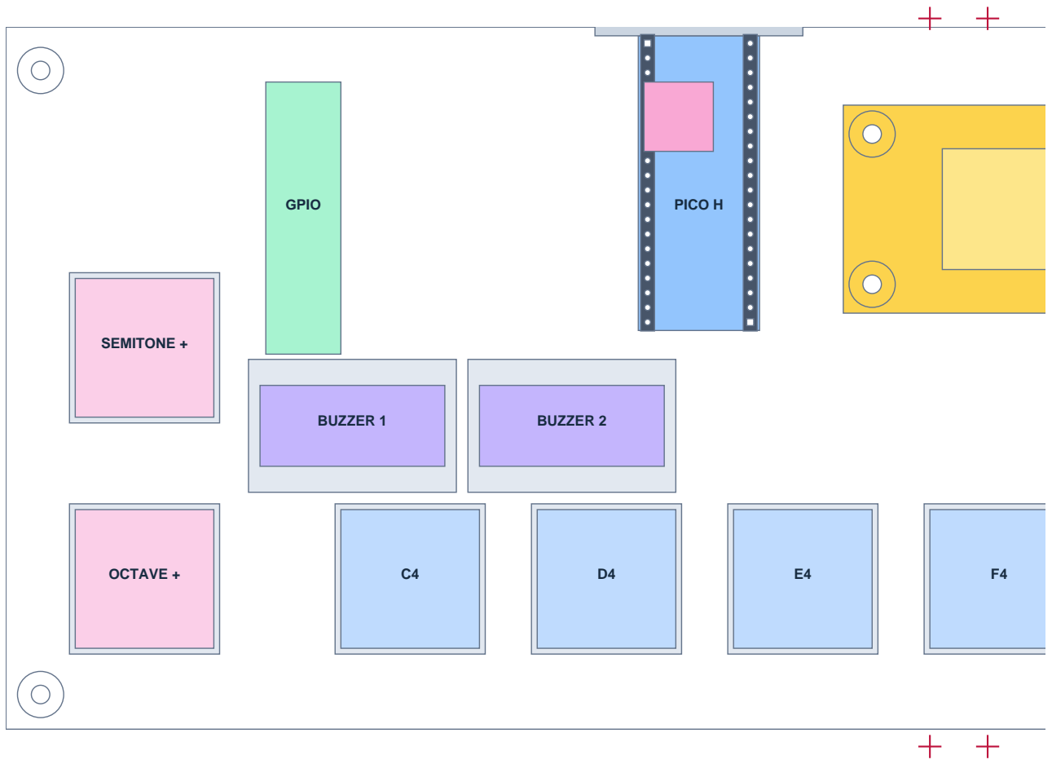
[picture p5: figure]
SEMITONE +; OCTAVE +; BUZZER 1; BUZZER 2; GPIO; PICO H

JOIN: overlap the repeated section and align all four red crosses.

Hold the joined 330 x 121.5 mm outline; try the keys with both hands. Notes: 24 mm bodies, 34 mm centres, 10 mm clear gaps. Modifiers on left.

Record: comfortable reach? key gap? overall size? room for USB/removal?

Body sizes and mounts still need actual-part fit. DO NOT use this to drill.

## MAKE MUSIC / ACTUAL-SIZE PAPER FIT

Page 2 of 2 - board x=150 to 330 mm

Print on US Letter at 100% / Actual Size. Turn off Fit or Shrink.
Check BOTH scale bars before judging reach. Paper checks comfort only.

4 inches exactly - check with your tape measure

100 mm exactly - optional metric check

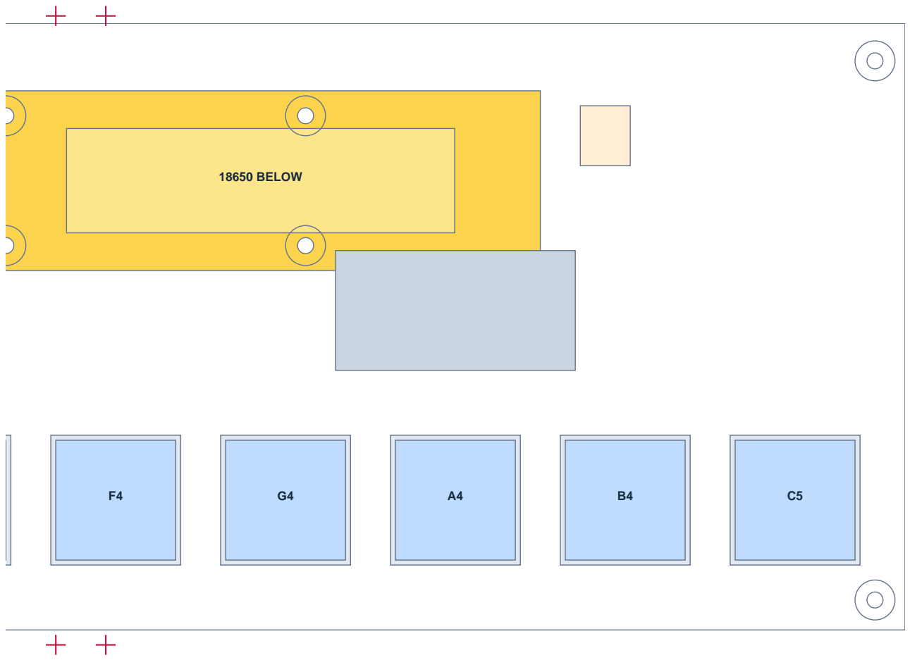
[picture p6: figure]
PICO H; 18650 BELOW

JOIN: overlap the repeated section and align all four red crosses.

Hold the joined 330 x 121.5 mm outline; try the keys with both hands. Notes: 24 mm bodies, 34 mm centres, 10 mm clear gaps. Modifiers on left.

Record: comfortable reach? key gap? overall size? room for USB/removal?

Body sizes and mounts still need actual-part fit. DO NOT use this to drill.

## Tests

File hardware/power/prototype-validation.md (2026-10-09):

# Factory assembly and power bring-up record

Prepared 2026-10-08 for the [selected fuse/eFuse circuit](branch-protection.md). **Procedure only: no assembly or bench results have been obtained.** Use only the final reviewed U2/F1 schematic/netlist/BOM, reconcile references before testing, and record its commit below; root owns manufacturing outputs.

**2026-10-09 correction:** qualify the **protected 18650** candidate/new holder and [current charger HOLD](18650-handoff.md). The former P1835C2/1101 selection is superseded. The 1S emulator test voltages and all current/thermal acceptance limits below remain; these are not new-cell test results.

Quote **five fully assembled instruments**, including all small components, THT, harnesses and mechanical work, plus an optional sixth bare carrier keepsake. Keep a separate bring-up/acceptance record for each assembled unit; a passing first unit does not populate the other four records. No actual parts are available for metrology yet. See [current 18650 readiness](18650-handoff.md) for pending fit, lot/charger and supplier-process acceptance.

Unit/serial: ______  PCB revision/commit: ______  native schematic commit: ______
Tester/date: ______  Pico model/firmware: ______  ambient: ______°C
Supply/load/meter/scope identifiers and current-calibration limits: ______

## Assembly handoff, no cell installed

Factory-populate F1 **SCHURTER 3403.0275.23**, U2 **TPS259474LRPWR**, S1 **MN12SS1W03**, support resistors/caps, D2 **SS14-E3/61T** and bidirectional D3 **SMAJ5.0CA**, plus carrier sockets/headers/buzzer bias and bypass. Do not populate the removed series D1 or C5/C6 polymer hold-up additions. Reconcile the [41-endpoint contract](branch-endpoints.csv) with native references: expected power R3–R8 correspond to document R1–R6, and C13/C14/C15/C16 to document C1/C2/C3/C4. Existing buzzer R1/R2 and connector C1–C12 remain separate. U2 PG3/ITIMER10 are NC; PGTH4/GND8 are GND; **power pads5/6 are IN/OUT, not a ground exposed pad11**. Record actual map if different: ______

Use the final reviewed RPW0010A land/stencil pattern and inspect U2 joints/pin1 orientation, D2 band toward VSYS, D3 **CA** bidirectional suffix, F1 value/continuity, S1 common2/ON3/OFF1, and underside H1 circuit1 positive/circuit2 GND. Native netlist/PCB parity, ERC/DRC and assembly-side drawings must have passed root review before assembly release; a BOM alone is insufficient.

Separately factory-build the **MPD BH-18650-W / protected-button-top-18650 cassette** from mechanical PR #30, after final measured CAD/process acceptance. Its factory 24 AWG TR64 leads are 150±5 mm each and replace holder-lug soldering. Retain JST PHR-2/SPH-002T-P0.5S, insulation and strain relief; measure lead OD against the contact's **0.8–1.5 mm** range, qualify exact tooling/strip/crimp and record finished lengths. MPD's supplied 5±1 mm stripped ends are not a JST preparation instruction. With **no cell**, trace positive holder contact to H1 circuit1 and negative to circuit2; no wire-color inference. Complete the delivered P1835J button-top cold fit/retention/removal, without forcing contacts or damaging the wrapper. Holder ampacity must support 0.70 A normal and at least 1.2 A continuous branch capability. Record cold-fit evidence separately; PCB tests do not certify it. The [current handoff](18650-handoff.md) links manufacturer evidence and specifies the PM/mechanical responsibilities.

Root PR #28 integrated **C17/C18 10 µF/10 V/X7R**, candidate TDK C2012X7R1A106K125AC, at the buzzer supplies. The [current rear-edge evidence](../review/rear-edge-20261009/README.md) at native `21b2108` confirms their 3V3_OUT/GND endpoints, values and footprints, with four exact metadata warnings still visible. The placement guard is fixed in merged PR #33; the [final matching package](../manufacturing/REVIEW_ONLY_DO_NOT_ORDER/README.md) published at `d987896` remains **REVIEW ONLY — DO NOT ORDER**. Root must close physical/process release requirements before assembly; regenerate matching evidence/exports if CAD changes. C17/C18 are separate from the C13–C16 eFuse support map. Check effective capacitance and include their regulator startup demand in USB/battery tests; no physical/transient result is inferred.

## Bench sequence and acceptance

Use an isolated, adjustable current-limited DC supply as the cell emulator, an electronic load, DMM and scope. All probe grounds reference H1.2/GND; never attach a grounded clip to H1.1. Use accessible named-net pads, not hand probing between U2's fine pins. Verify isolation before reversing the emulator with USB present. Measure current in series; changing meter range/connections is done with sources OFF.

Keep the real cell and external charger out of all tests below. Connect/disconnect Pico/modules with every source OFF. Before each ramp record **H1 voltage and BAT_SW_PLUS at U2 IN separately**. The latter controls UVLO/OVLO. Stop on incorrect polarity, supply current-limit operation during a normal test, unexpected heating, rail excursions or failure to latch; identify the cause before increasing a limit.

1. **Cold checks / first power:** no Pico, USB or modules. Verify continuity against the final netlist, no power-to-ground short, correct resistor values and no VBUS_USB/battery bridge. Switch OFF; set emulator 4.20 V, 20 mA limit. Switch ON, inspect initial no-load current/VSYS; engineering screening target <5 mA bare-board steady current, no CC. VSYS should follow valid IN with low drop. Switch OFF and confirm input-branch interruption. A continuity-meter beep on capacitors is not sufficient evidence of a sustained short.
2. **Battery-path load:** raise supply limit to 0.75 A only after cold/first-power pass. With no Pico/USB, use VSYS electronic load at 0.10, 0.35 and 0.70 A; record H1, IN, VSYS and component temperatures. At 0.70 A require IN-to-VSYS drop ≤65 mV (31.5 mV U2 model plus 30 mV copper allowance, rounded), no unintended latch, stable output and resistor local temperature ≤70°C. This is a prototype design criterion, not a new datasheet guarantee. Verify input current ≤0.70 A in the eventual normal instrument configuration; the bare-path 0.70 A output test adds input-side quiescent current and is characterization, not approved normal loading.
3. **UVLO:** replace load with 100 Ω, ≥1 W from VSYS to GND; supply limit 100 mA. Start at 4.20 V, lower slowly to 2.90 V, then raise to 4.25 V. Measure actual IN at disconnect and restart: expected calculation ranges **3.053–3.430 V falling /3.363–3.752 V rising**, nominal 3.221/3.546 V. A 3.10 V point may legitimately be OFF. UVLO recovers automatically; distinguish it from fault latch. Record loaded H1 cutoff as well, since harness/fuse losses shift the apparent cell endpoint.
4. **Fault latch, no USB/Pico/modules:** return to valid 4.25 V emulator input, confirm IN stays above the measured UVLO threshold. Set supply limit 1.30 A for this isolated test only. Pulse electronic load from 0.70 toward 1.20 A in increments, each above-0.70 A pulse ≤20 ms, recording current immediately before output collapse with a current probe or calibrated shunt/scope; a DMM alone cannot capture trip. Engineering qualification target **0.80–1.20 A**, with stable IN; stop if 1.25 A demand fails to trip. Return load to 0.10 A: output must stay off until reset. Repeat after reset at H1=3.70 V and a lower-voltage point with IN ≥0.10 V above the measured falling UVLO throughout the pulse; record each actual IN. If the supply enters CC or IN crosses UVLO, the result is invalid, not proof of breaker action. Published current bounds were specified at VIN=12 V; this test supplies the missing 1S evidence. Do not intentionally blow F1 or hard-short a live cell.
5. **Reset / OVLO:** remove load fault and all sources, S1 OFF. Confirm **BAT_SW_PLUS <1.0 V and EN_UVLO <0.45 V** before reapplying power; record the actual OFF dwell. Do not promise immediate switch cycling resets charged input bypass, especially with USB still on. With no Pico/USB/modules and the 100 Ω load, use a 100 mA-limited emulator to ramp IN toward **5.45 V maximum**, then downward. This deliberately exceeds 1S voltage only on the bare carrier. Expected OVLO trip **4.710–5.315 V**, recovery **4.275–4.860 V**. Record actual IN and waveform; no inference from a typical response time that arbitrary surges are safe.
6. **Reverse insertion / USB isolation:** no Pico initially. S1 OFF; configure the isolated emulator so H1.1 is negative relative to H1.2, magnitude 4.25 V, limit 20 mA; then switch ON. IN is negative, VSYS must not become negative or supply a load. Record leakage; engineering screening bound <2 mA steady, no CC. Restore positive polarity with sources OFF. For USB testing, install the verified Pico with modules absent and use a separately current-limited 5 V USB fixture, initially 100 mA limit; stop if CC and set a larger source budget only after Pico load/inrush is accounted. Confirm USB powers VSYS with S1 OFF, battery-positive emulator at 4.25/3.70 V, and reverse emulator at −4.25 V only after the isolated reverse test passed. Record signed battery-terminal current and look for unexpected USB-dependent battery backfeed; investigate a repeatable charging current rather than treating it as a charger. USB bypasses F1/U2, so battery fault tests cannot approve host current or output-short behavior. Never test a USB output short from a computer port.
7. **Pico/modules, then cell gate:** sources OFF, positive emulator, USB unplugged. Install verified firmware and Pico alone; start at 4.20 V/0.20 A limit. Add mapped touch/buzzer cables one at a time with power OFF, accounting for measured current before any limit increase, and cap normal battery input at 0.70 A. Check HIGH buzzer idle/reset silence, notes/releases/modifiers, all touch LEDs, both ST0238 modules sounding and intended expansion. Require ≤250 mA external 3V3 and ≤350 mA total including Pico; measure at the correct rail, not infer from battery current. Engineering steady 3V3 screening range is **3.14–3.46 V**, plus successful actual module operation. Repeat load and thermal checks at 3.70 V and just above this unit's measured UVLO. Stop playing before USB source changes; reset/reboot is allowed, settle before resuming. Capture IN/VSYS/3V3 startup and transients against actual part limits; typical TI timing is not a maximum guarantee.

**First real-cell operation is held until** the new 18650 cold fit, harness polarity, all normal-load/rail checks and reverse/fault tests above pass, and the exact **P1835J lot/terminal and external-charger compatibility** gaps in [18650-handoff.md](18650-handoff.md) are resolved. Then, with every source OFF, verify actual polarity/voltage at the disconnected harness before carrier connection. Record cell/charger lot and limits; first operation is attended. Remove the cell for external charging. UVLO stopping is the instruction to switch OFF/recharge, not to continue through repeated rebounds; cell is removed for storage.

## Blank measured results — retain failures and scope captures

`____` means **not measured**, never zero/pass. Attach waveform/temperature records by unit and revision; record instrument resolution for leakage and peak current.

| Test | Measured result / conditions | Status / evidence |
|---|---|---|
| Assembly/netlist/parts; harness cold continuity and fit | ____ | ____ |
| Bare-board input current, OFF leakage / meter resolution | ____ mA /____ µA | ____ |
| 0.10/0.35/0.70 A path drop, hottest part / ambient | ____ mV /____°C /____°C | ____ |
| UVLO IN fall/rise; H1 loaded cutoff | ____ /____ /____ V | ____ |
| Breaker trip current; IN remained valid; latch persisted | ____ A /____ V /____ | ____ |
| OFF dwell; IN and EN before restart | ____ s /____ V /____ V | ____ |
| OVLO IN trip/recovery | ____ /____ V | ____ |
| −4.25 V leakage, with/without USB; minimum VSYS | ____ /____ mA /____ V | ____ |
| USB-only input steady/plug-in peak and source policy | ____ /____ mA /____ | ____ |
| Battery-terminal signed current with USB present | ____ µA; resolution ____ | ____ |
| Full instrument input /external 3V3 /total 3V3 | ____ /____ /____ mA | ____ |
| 3V3 steady minimum/maximum; startup/transient captures | ____ /____ V | ____ |
| Reset silence/touch polarity/sound; source-change restart | ____ | ____ |
| Cell/charger qualification; first-cell release/result | ____ | ____ |
| 18650 maker/model/lot, terminal form and measured envelope | ____ | ____ |
| BH-18650-W/cassette fitted envelope, loaded clearance and removal/retention | ____ | ____ |
| Factory lead OD/finished lengths, contact/tool/strip/crimp inspection and strain relief | ____ | ____ |
| Charger revision, CC/CV tolerances, termination and cell-temperature policy | ____ | ____ |

## Analysis completed without physical parts

- U2 conduction model at 0.70 A using the published 45 mΩ ceiling (specified at 3 A): **31.5 mV, 22.1 mW**. Adding 4.25 V ×0.610 mA quiescent gives about 2.6 mW input overhead under table conditions. These do not establish PCB temperature; no four-layer datasheet thermal resistance is transferred to this two-layer carrier.
- F1 lists **330 mV typical at 1.25 A**, not a maximum. A constant-resistance illustration gives 0.264 Ω and **185 mV /129 mW at 0.70 A**; fuse heating is nonlinear, so measure rather than use this as a guaranteed drop. NKK silver-contact initial rating gives 10 mΩ maximum, or 7 mV /4.9 mW at 0.70 A; it does not bound aged contacts/inrush.
- NKK recommends a **0.1 A at 2 V AC/DC minimum** for these silver contacts. Actual instrument idle/startup current is unknown; low-load switching and contact endurance remain open qualifications. The bare-board tests below that minimum do not establish lifetime. Do not substitute the gold logic-contact version: its 0.1 A applicable upper range cannot carry this 0.70 A branch.
- MPD's revision G drawing specifies **two factory 150±5 mm AWG24 leads**. Using the [Alpha Wire conductor chart](https://cdn.belden.com/-/media/Project/AlphaWire/AlphaWire/Content/Part-Number-Color-Codes/AWG-Conversion.pdf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) value of 83.1 mΩ/m for **7/32 tinned copper**, the 0.30 m nominal loop gives **24.9 mΩ, 17.5 mV /12.2 mW at 0.70 A**; two 155 mm leads give **25.8 mΩ, 18.0 mV /12.6 mW** in that same model. MPD does not specify this conductor construction/resistance, so neither result is an MPD maximum or measured harness resistance. Exclude crimps/holder/temperature from this illustration and measure the complete path; its losses precede IN and can make raw-cell cutoff higher than 3.221 V.
- The 30 mV OUT-to-socket allowance at 0.70 A implies ≤**42.9 mΩ** copper/connection resistance after U2. At the conservative 2.992 V VSYS operating point, 350 mA at 3V3 requires approximately **0.515 A** with assumed 75% conversion efficiency; reaching 0.70 A corresponds to about 55% efficiency before other loads. Measured rail currents/efficiency still govern acceptance.
- C2/C4 total 9.4 µF nominal, after −10% initial and −15% temperature gives 7.19 µF before bias/aging. Keeping >1 µF requires >**13.9% combined bias/aging retention**. This computes needed margin; it does not turn a typical manufacturer DC-bias curve into a guaranteed minimum. Confirm effective capacitance from the actual parts/bias conditions. All VSYS additions including Pico remain ≤100 µF; no hold-up bank.
- No live-cell fault clearing, holder ampacity, runtime or formal single-fault certification is derived. F1 protects input-side shorts as a slow backup; a short ahead of it still depends on the protected cell. A VSYS short with USB present also draws through Pico's USB path; U2 does not protect that source.

Ratings/threshold sources are linked in [branch-protection.md](branch-protection.md): TI SLVSFC9C, SCHURTER UMT-H, NKK MN and TDK characterization. All acceptance bands labeled engineering above are commissioning criteria, not additional manufacturer guarantees. Static calculations and document checks do not populate the measured-results table.

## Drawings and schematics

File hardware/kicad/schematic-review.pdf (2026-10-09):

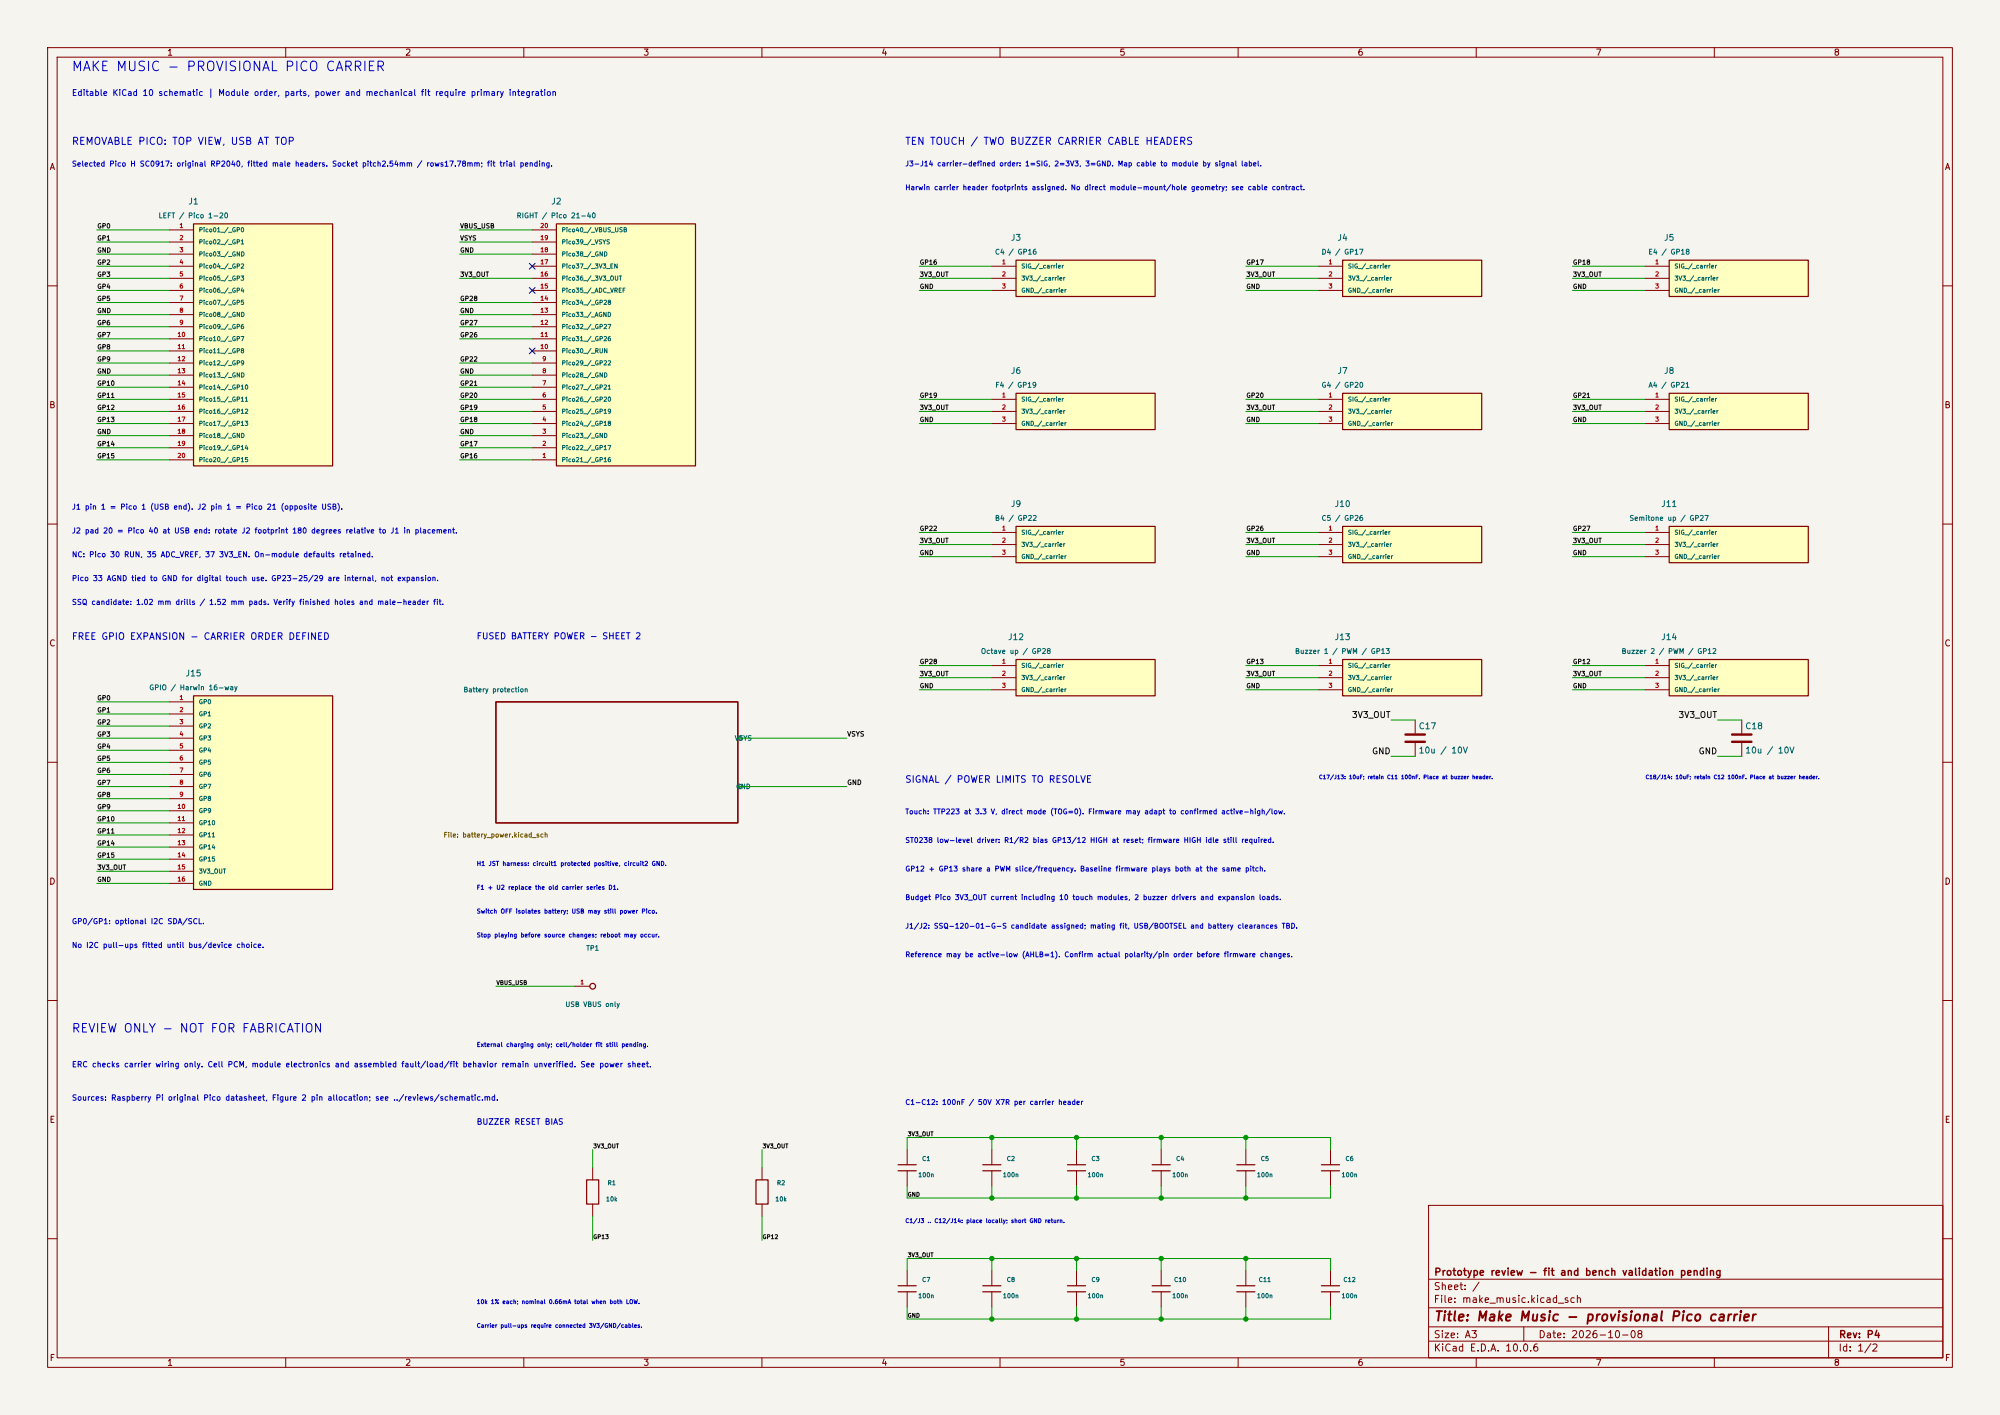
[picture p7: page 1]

MAKE MUSIC - PROVISIONAL PICO CARRIER

Selected Pico H SC0917: original RP2040, fitted male headers. Socket pitch2.54mm / rows17.78mm; fit trial pending. Editable KiCad 10 schematic | Module order, parts, power and mechanical fit require primary integration

REMOVABLE PICO: TOP VIEW, USB AT TOP

TEN TOUCH / TWO BUZZER CARRIER CABLE HEADERS

J3-J14 carrier-defined order: 1=SIG, 2=3V3, 3=GND. Map cable to module by signal label. Harwin carrier header footprints assigned. No direct module-mount/hole geometry; see cable contract.

C17/J13: 10uF; retain C11 100nF. Place at buzzer header. Pico 33 AGND tied to GND for digital touch use. GP23-25/29 are internal, not expansion.

SSQ candidate: 1.02 mm drills / 1.52 mm pads. Verify finished holes and male-header fit. FREE GPIO EXPANSION - CARRIER ORDER DEFINED

FUSED BATTERY POWER - SHEET 2

Touch: TTP223 at 3.3 V, direct mode (TOG=0). Firmware may adapt to confirmed active-high/low.

ST0238 low-level driver: R1/R2 bias GP13/12 HIGH at reset; firmware HIGH idle still required. GP12 + GP13 share a PWM slice/frequency. Baseline firmware plays both at the same pitch. GP0/GP1: optional I2C SDA/SCL. No I2C pull-ups fitted until bus/device choice. REVIEW ONLY - NOT FOR FABRICATION

C1-C12: 100nF / 50V X7R per carrier header F1 + U2 replace the old carrier series D1.
Budget Pico 3V3_OUT current including 10 touch modules, 2 buzzer drivers and expansion loads. J1/J2: SSQ-120-01-G-S candidate assigned; mating fit, USB/BOOTSEL and battery clearances TBD. Reference may be active-low (AHLB=1). Confirm actual polarity/pin order before firmware changes. External charging only; cell/holder fit still pending. Stop playing before source changes; reboot may occur. Carrier pull-ups require connected 3V3/GND/cables. 10k 1% each; nominal 0.66mA total when both LOW. BUZZER RESET BIAS

Sources: Raspberry Pi original Pico datasheet, Figure 2 pin allocation; see ../reviews/schematic.md. ERC checks carrier wiring only. Cell PCM, module electronics and assembled fault/load/fit behavior remain unverified. See power sheet.

C1/J3 .. C12/J14: place locally; short GND return.

Prototype review - fit and bench validation pending
Sheet: /
File: make_music.kicad_sch
Title: Make Music - provisional Pico carrier

Size: A3 | Rev: P4 | F Date: 2026-10-08
KiCad E.D.A. 10.0.6 | Id: 1/2

1 | 2 | 3 | 4 | 5 | 6 | 7 | 8

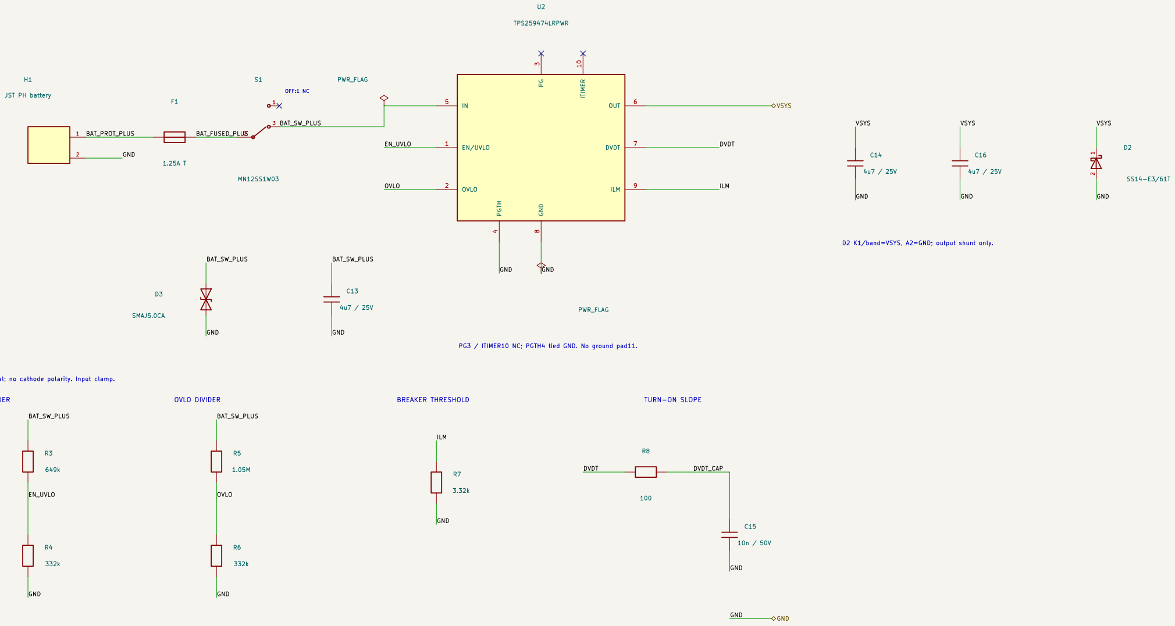
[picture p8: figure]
SMAJ5.0CA; PWR_FLAG; 2 H1 JST PH batteryR3; SS14-E3/61T PWR_FLAG; EN/UVLO 1; OVLO 2; 3 PGTH; OUT; 6 DVDT; 7 GND; ILM; 9 ITIMER 10 U2; TPS259474LRPWR; GND; VSYS; EN_UVLO; BAT_SW_PLUS; DVDT_CAP; DVDT GND; OVLO; VSYS DVDT BAT_FUSED_PLUS BAT_SW_PLUS; BAT_SW_PLUS GND; VSYS BAT_SW_PLUS GND; BAT_PROT_PLUS

1 | 2 | 3 | 4 | 5 | 6 | 7 | 8

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
Size: A3 | Rev: P4 | F Date: 2026-10-08
KiCad E.D.A. 10.0.6 | Id: 2/2

# Title: Make Music - fused battery power

## File: battery_power.kicad_sch

## Sheet: /Battery protection/

## Prototype review - fit and bench validation pending

## BATTERY BRANCH - FUSED, REVERSE-PROTECTED, EXTERNAL CHARGE ONLY

PG3 / ITIMER10 NC; PGTH4 tied GND. No ground pad11. BREAKER THRESHOLD

OFF:1 NC | D2 K1/band=VSYS, A2=GND; output shunt only. LOCAL NONPOLAR CERAMICS / SHUNT CLAMPS UVLO DIVIDER | OVLO DIVIDER | TURN-ON SLOPE D3 CA bidirectional; no cathode polarity. Input clamp.

### ENTRY / BACKUP FUSE / SWITCH / LATCH-OFF eFUSE

Prototype circuit from power PR #18. Physical fit, current, fault transients and source changes require bench validation.

DESIGN LIMITS: branch <=0.70A; total3V3 <=350mA including Pico / external <=250mA; ambient0-40C. All VSYS capacitance including Pico <=100uF; effective output ceramics >1uF. No polymer hold-up parts. UVLO nominal3.221V off /3.546V restart at IN; breaker nominal1.004A. Tolerance/1S fault response need bench checks. Stop playing before USB/battery changes; reboot may occur. S1 OFF / USB removal before service; external cell charging only. F1 first at entry, before branches; 5mm-wide /35um copper approach lands per power contract. Keep unfused harness short/insulated. Local C13 at IN/GND, C14/C16 at OUT/GND; short clamp/control loops. RPW IN5/OUT6 are large power contacts. PWR_FLAGs declare external switched supply and return for ERC only; they do not add hardware or prove live power. Reviewed candidate footprints and circuit are not fabrication approval. See power-integration.md and power/branch-protection.md.

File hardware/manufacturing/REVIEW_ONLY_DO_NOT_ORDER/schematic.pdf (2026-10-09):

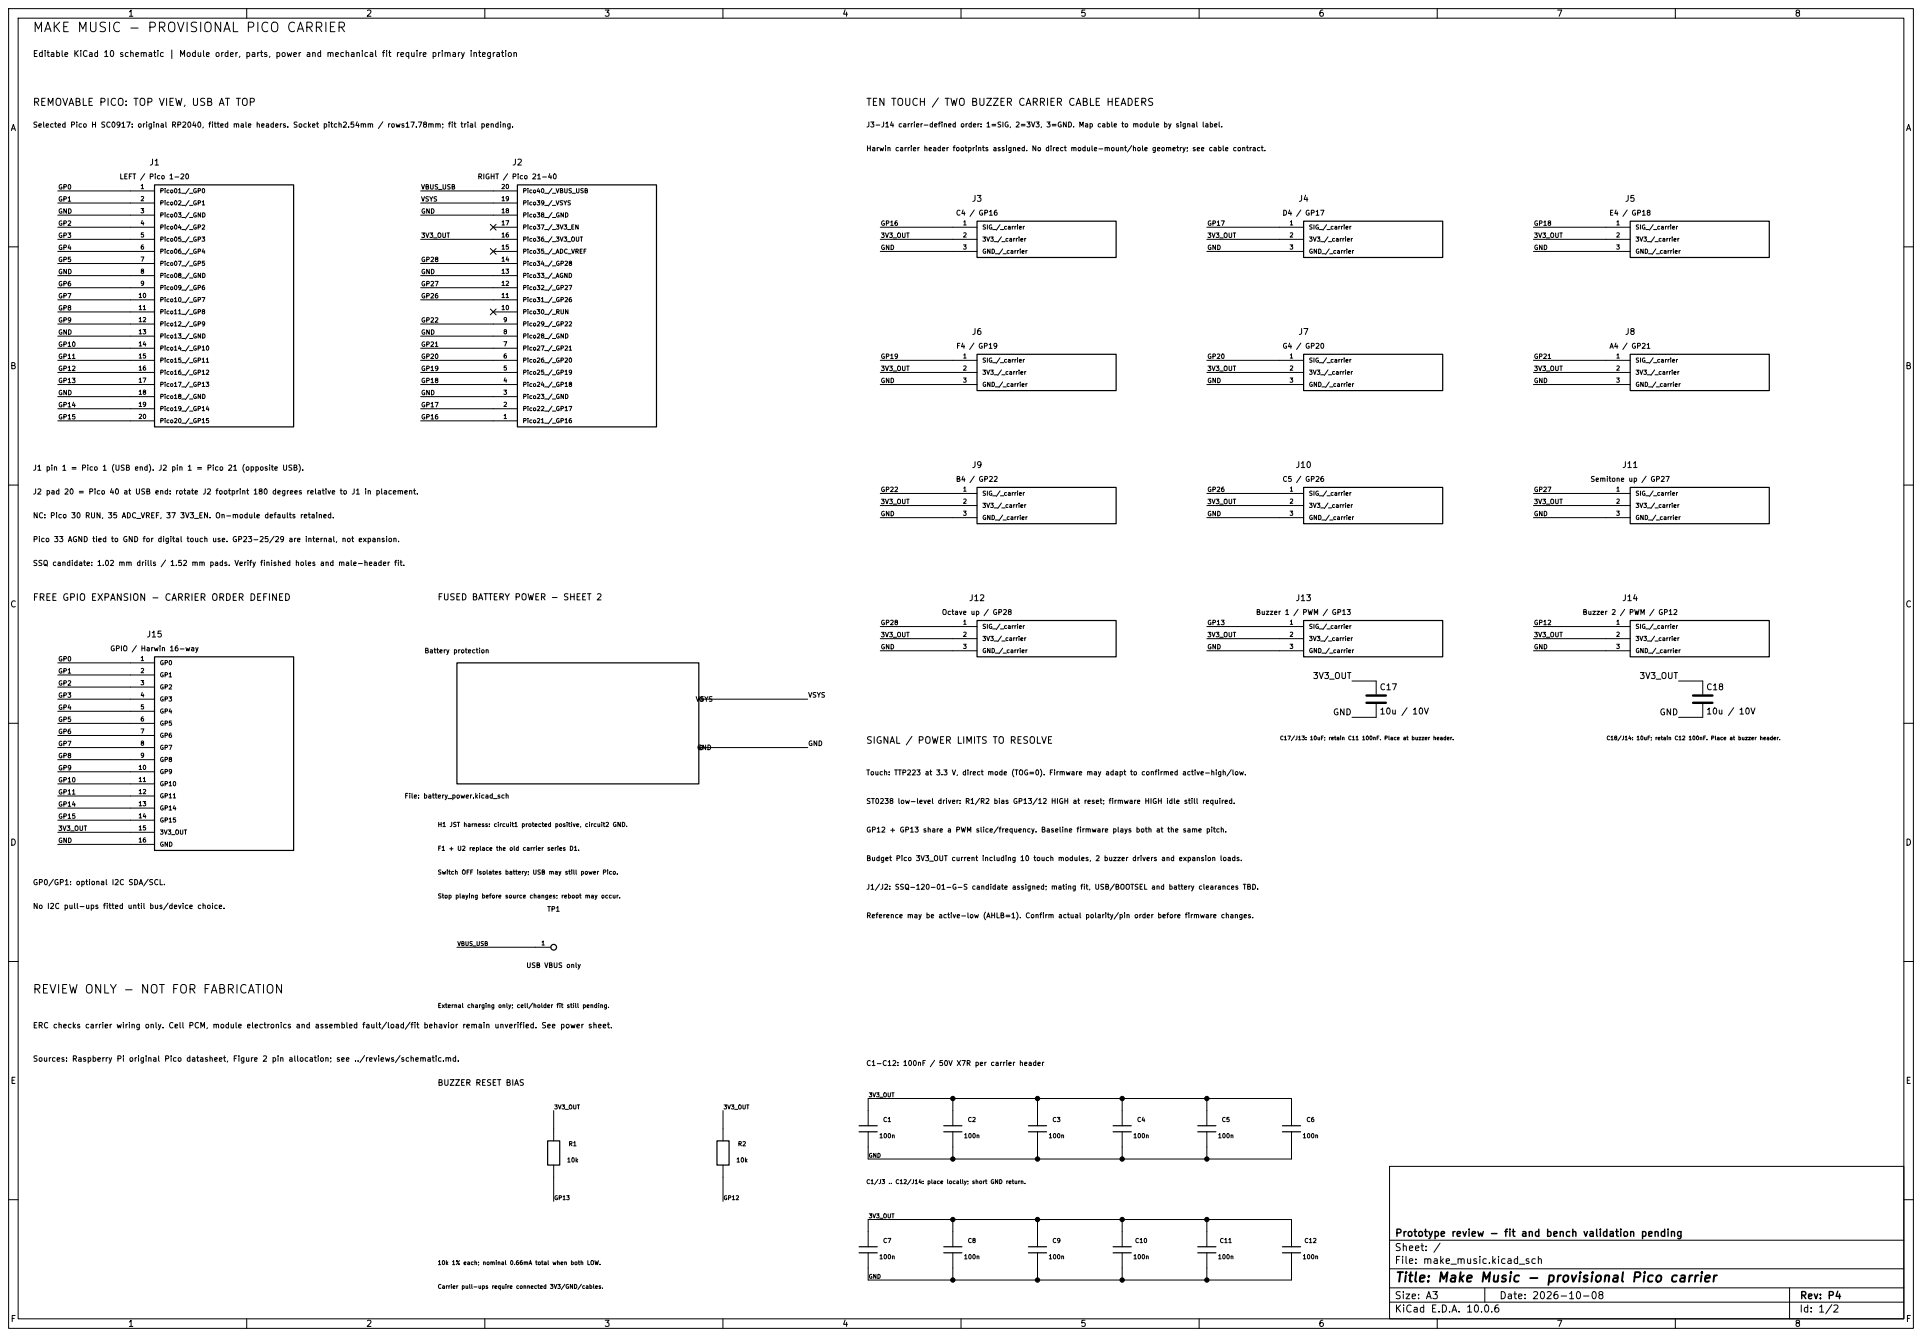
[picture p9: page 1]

MAKE MUSIC - PROVISIONAL PICO CARRIER

Selected Pico H SC0917: original RP2040, fitted male headers. Socket pitch2.54mm / rows17.78mm; fit trial pending. Editable KiCad 10 schematic | Module order, parts, power and mechanical fit require primary integration

REMOVABLE PICO: TOP VIEW, USB AT TOP

TEN TOUCH / TWO BUZZER CARRIER CABLE HEADERS

J3-J14 carrier-defined order: 1=SIG, 2=3V3, 3=GND. Map cable to module by signal label. Harwin carrier header footprints assigned. No direct module-mount/hole geometry; see cable contract.

C17/J13: 10uF; retain C11 100nF. Place at buzzer header. Pico 33 AGND tied to GND for digital touch use. GP23-25/29 are internal, not expansion.

SSQ candidate: 1.02 mm drills / 1.52 mm pads. Verify finished holes and male-header fit. FREE GPIO EXPANSION - CARRIER ORDER DEFINED

FUSED BATTERY POWER - SHEET 2

Touch: TTP223 at 3.3 V, direct mode (TOG=0). Firmware may adapt to confirmed active-high/low.

ST0238 low-level driver: R1/R2 bias GP13/12 HIGH at reset; firmware HIGH idle still required. GP12 + GP13 share a PWM slice/frequency. Baseline firmware plays both at the same pitch. GP0/GP1: optional I2C SDA/SCL. No I2C pull-ups fitted until bus/device choice. REVIEW ONLY - NOT FOR FABRICATION

C1-C12: 100nF / 50V X7R per carrier header F1 + U2 replace the old carrier series D1.
Budget Pico 3V3_OUT current including 10 touch modules, 2 buzzer drivers and expansion loads. J1/J2: SSQ-120-01-G-S candidate assigned; mating fit, USB/BOOTSEL and battery clearances TBD. Reference may be active-low (AHLB=1). Confirm actual polarity/pin order before firmware changes. External charging only; cell/holder fit still pending. Stop playing before source changes; reboot may occur. Carrier pull-ups require connected 3V3/GND/cables. 10k 1% each; nominal 0.66mA total when both LOW. BUZZER RESET BIAS

Sources: Raspberry Pi original Pico datasheet, Figure 2 pin allocation; see ../reviews/schematic.md. ERC checks carrier wiring only. Cell PCM, module electronics and assembled fault/load/fit behavior remain unverified. See power sheet.

C1/J3 .. C12/J14: place locally; short GND return.

Prototype review - fit and bench validation pending
Sheet: /
File: make_music.kicad_sch
Title: Make Music - provisional Pico carrier

Size: A3 | Rev: P4 | F Date: 2026-10-08
KiCad E.D.A. 10.0.6 | Id: 1/2

1 | 2 | 3 | 4 | 5 | 6 | 7 | 8

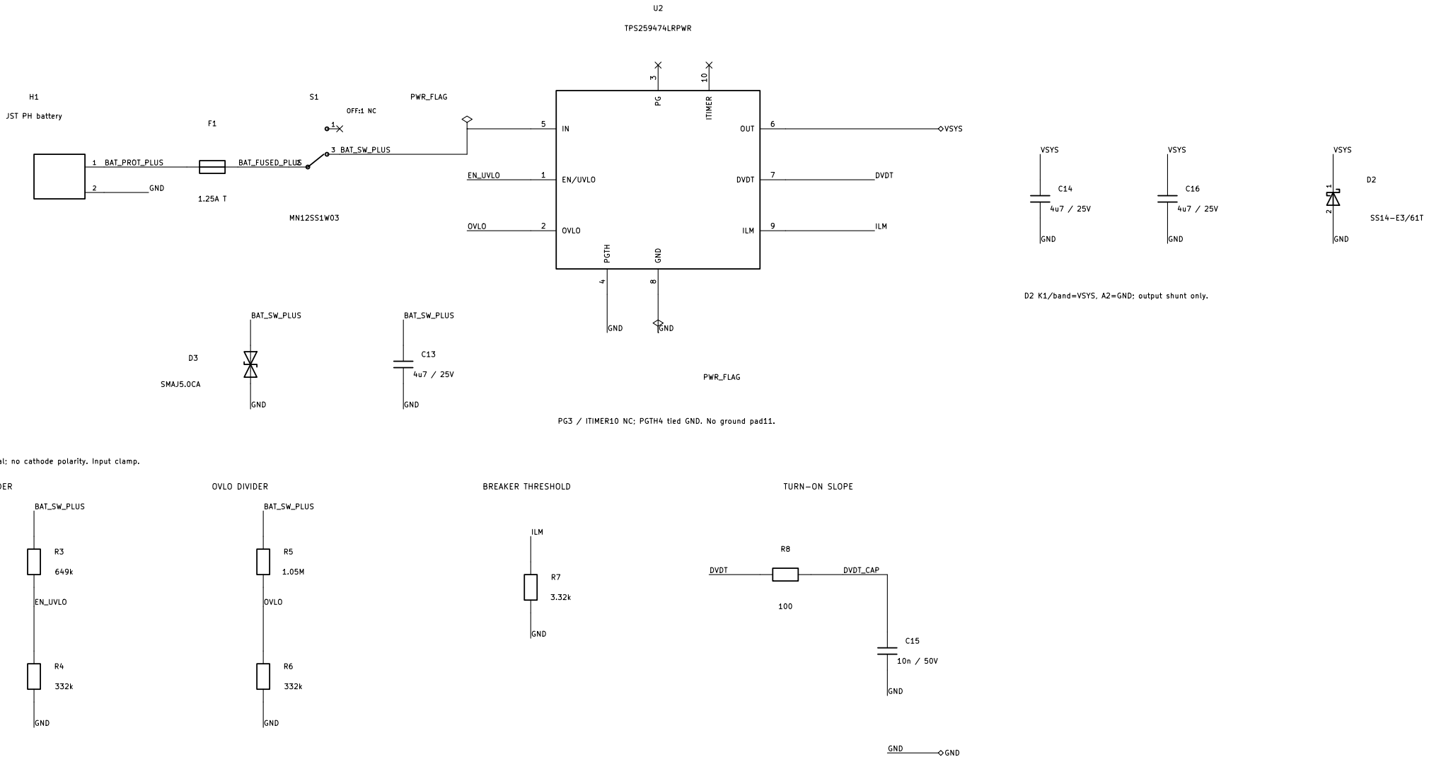
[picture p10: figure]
SMAJ5.0CA; PWR_FLAG; 2 H1 JST PH batteryR3; SS14-E3/61T PWR_FLAG; EN/UVLO 1; OVLO 2; 3 PGTH; OUT; 6 DVDT; 7 GND; ILM; 9 ITIMER 10 U2; TPS259474LRPWR; GND; VSYS; EN_UVLO; BAT_SW_PLUS; DVDT_CAP; DVDT GND; OVLO; VSYS DVDT BAT_FUSED_PLUS BAT_SW_PLUS; BAT_SW_PLUS GND; VSYS BAT_SW_PLUS GND; BAT_PROT_PLUS

1 | 2 | 3 | 4 | 5 | 6 | 7 | 8

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
Size: A3 | Rev: P4 | F Date: 2026-10-08
KiCad E.D.A. 10.0.6 | Id: 2/2

# Title: Make Music - fused battery power

## File: battery_power.kicad_sch

## Sheet: /Battery protection/

## Prototype review - fit and bench validation pending

## BATTERY BRANCH - FUSED, REVERSE-PROTECTED, EXTERNAL CHARGE ONLY

PG3 / ITIMER10 NC; PGTH4 tied GND. No ground pad11. BREAKER THRESHOLD

OFF:1 NC | D2 K1/band=VSYS, A2=GND; output shunt only. LOCAL NONPOLAR CERAMICS / SHUNT CLAMPS UVLO DIVIDER | OVLO DIVIDER | TURN-ON SLOPE D3 CA bidirectional; no cathode polarity. Input clamp.

### ENTRY / BACKUP FUSE / SWITCH / LATCH-OFF eFUSE

Prototype circuit from power PR #18. Physical fit, current, fault transients and source changes require bench validation.

DESIGN LIMITS: branch <=0.70A; total3V3 <=350mA including Pico / external <=250mA; ambient0-40C. All VSYS capacitance including Pico <=100uF; effective output ceramics >1uF. No polymer hold-up parts. UVLO nominal3.221V off /3.546V restart at IN; breaker nominal1.004A. Tolerance/1S fault response need bench checks. Stop playing before USB/battery changes; reboot may occur. S1 OFF / USB removal before service; external cell charging only. F1 first at entry, before branches; 5mm-wide /35um copper approach lands per power contract. Keep unfused harness short/insulated. Local C13 at IN/GND, C14/C16 at OUT/GND; short clamp/control loops. RPW IN5/OUT6 are large power contacts. PWR_FLAGs declare external switched supply and return for ERC only; they do not add hardware or prove live power. Reviewed candidate footprints and circuit are not fabrication approval. See power-integration.md and power/branch-protection.md.

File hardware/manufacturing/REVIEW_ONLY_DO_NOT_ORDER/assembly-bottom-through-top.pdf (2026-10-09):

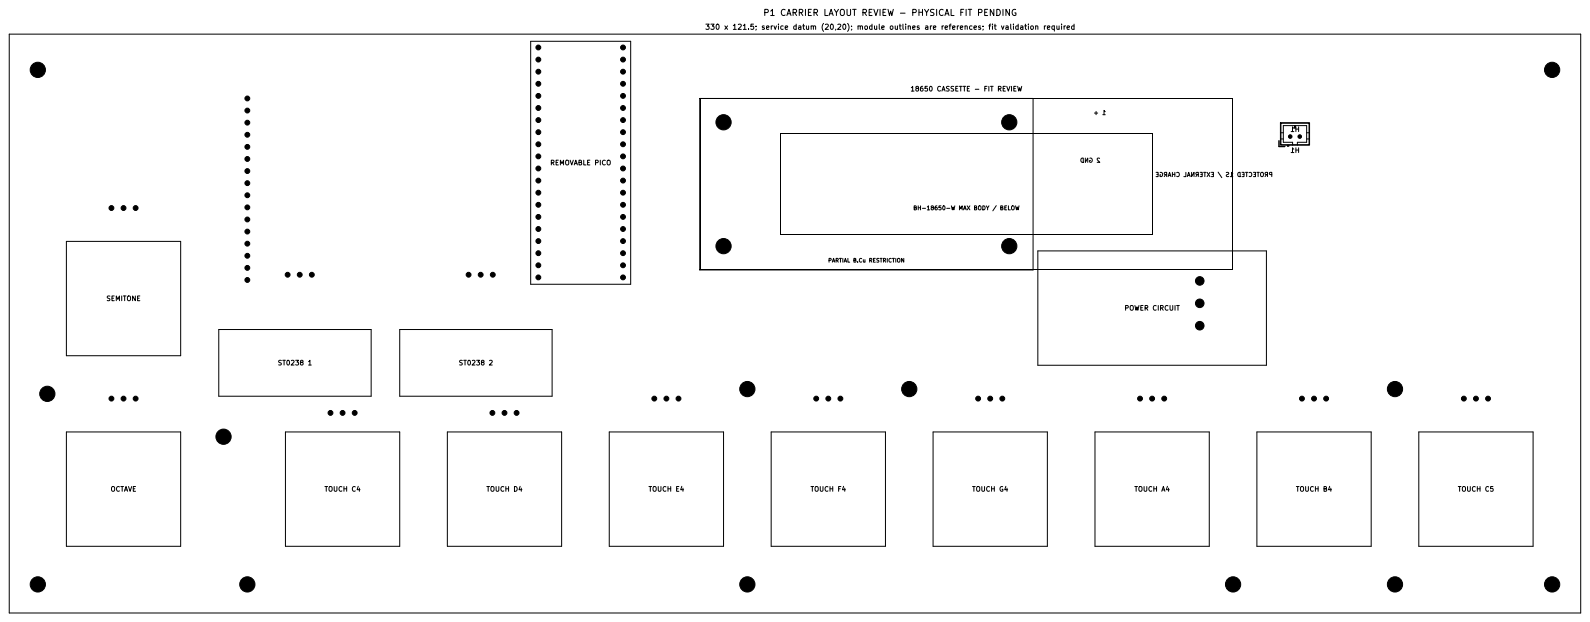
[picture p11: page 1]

330 x 121.5; service datum (20,20); module outlines are references; fit validation required P1 CARRIER LAYOUT REVIEW - PHYSICAL FIT PENDING

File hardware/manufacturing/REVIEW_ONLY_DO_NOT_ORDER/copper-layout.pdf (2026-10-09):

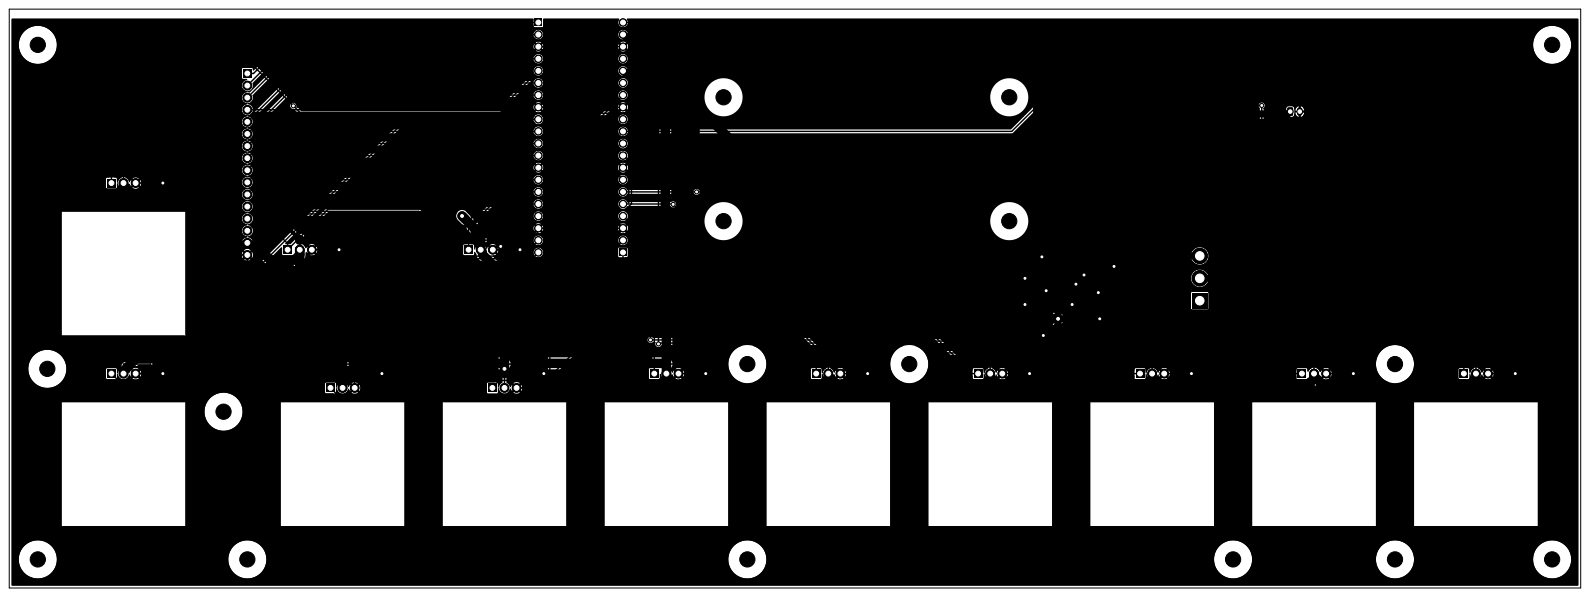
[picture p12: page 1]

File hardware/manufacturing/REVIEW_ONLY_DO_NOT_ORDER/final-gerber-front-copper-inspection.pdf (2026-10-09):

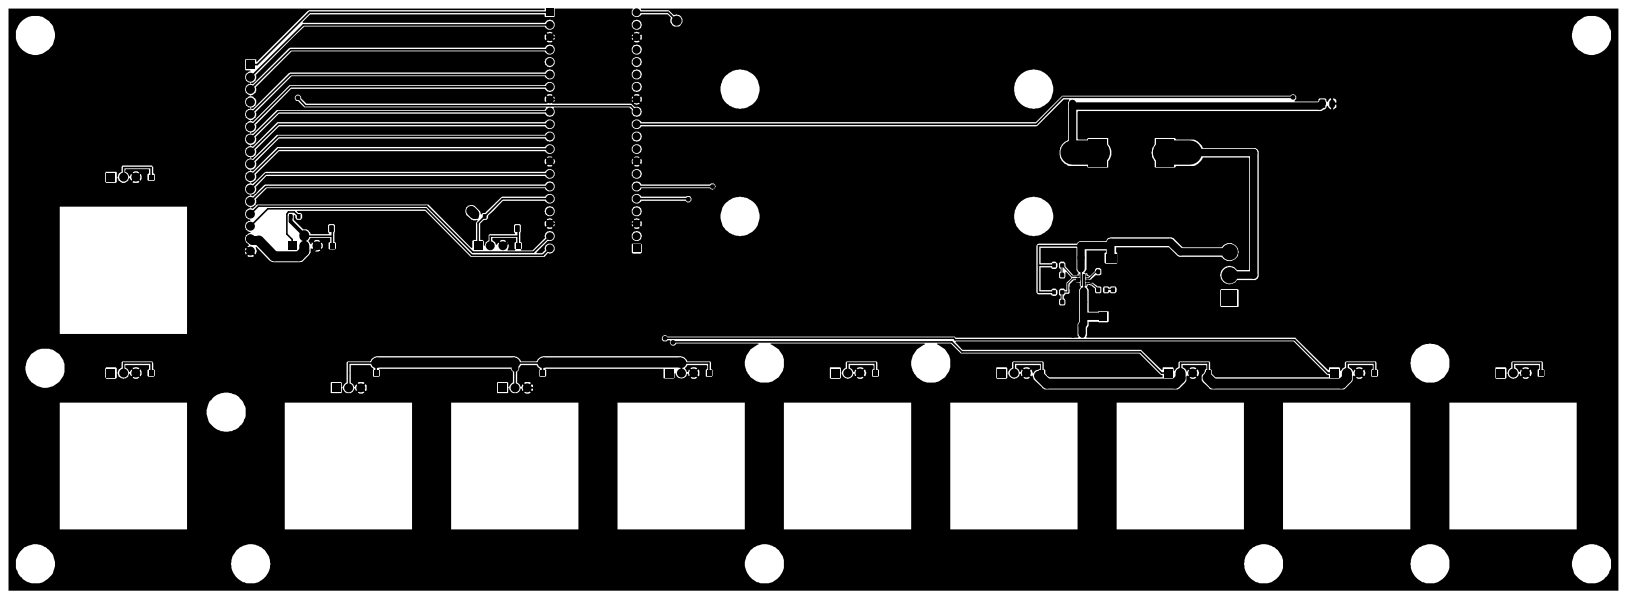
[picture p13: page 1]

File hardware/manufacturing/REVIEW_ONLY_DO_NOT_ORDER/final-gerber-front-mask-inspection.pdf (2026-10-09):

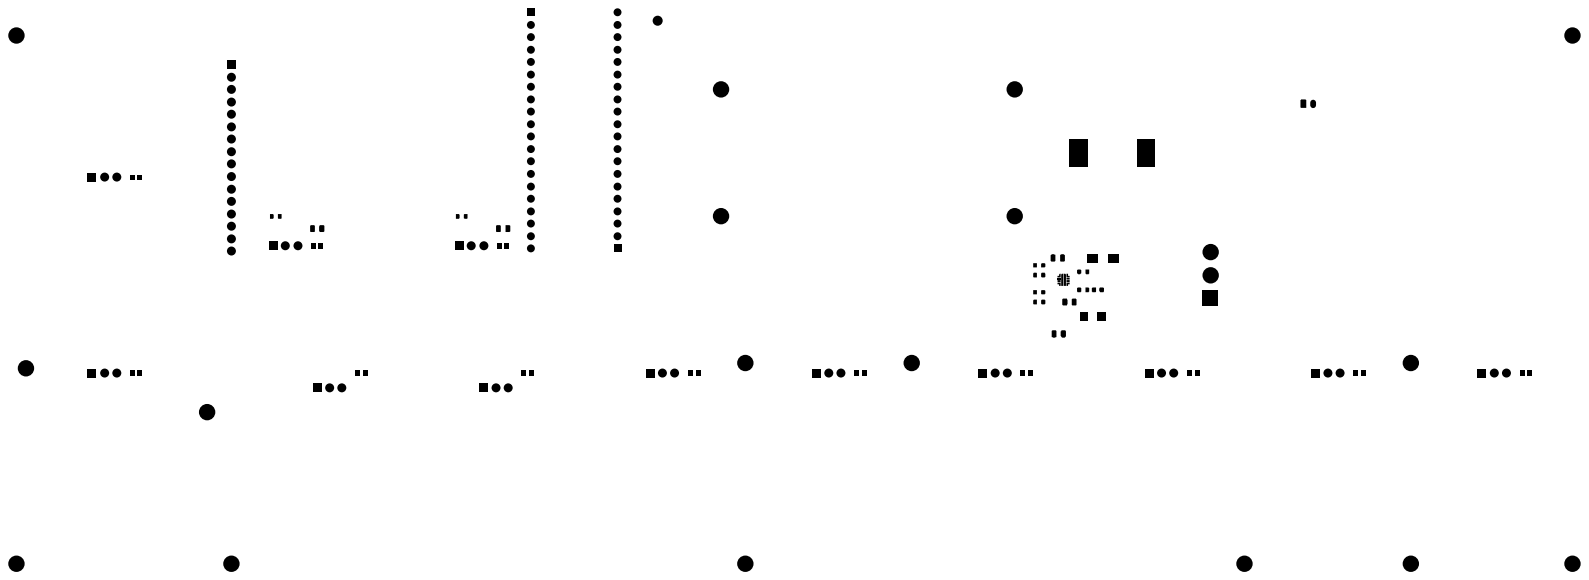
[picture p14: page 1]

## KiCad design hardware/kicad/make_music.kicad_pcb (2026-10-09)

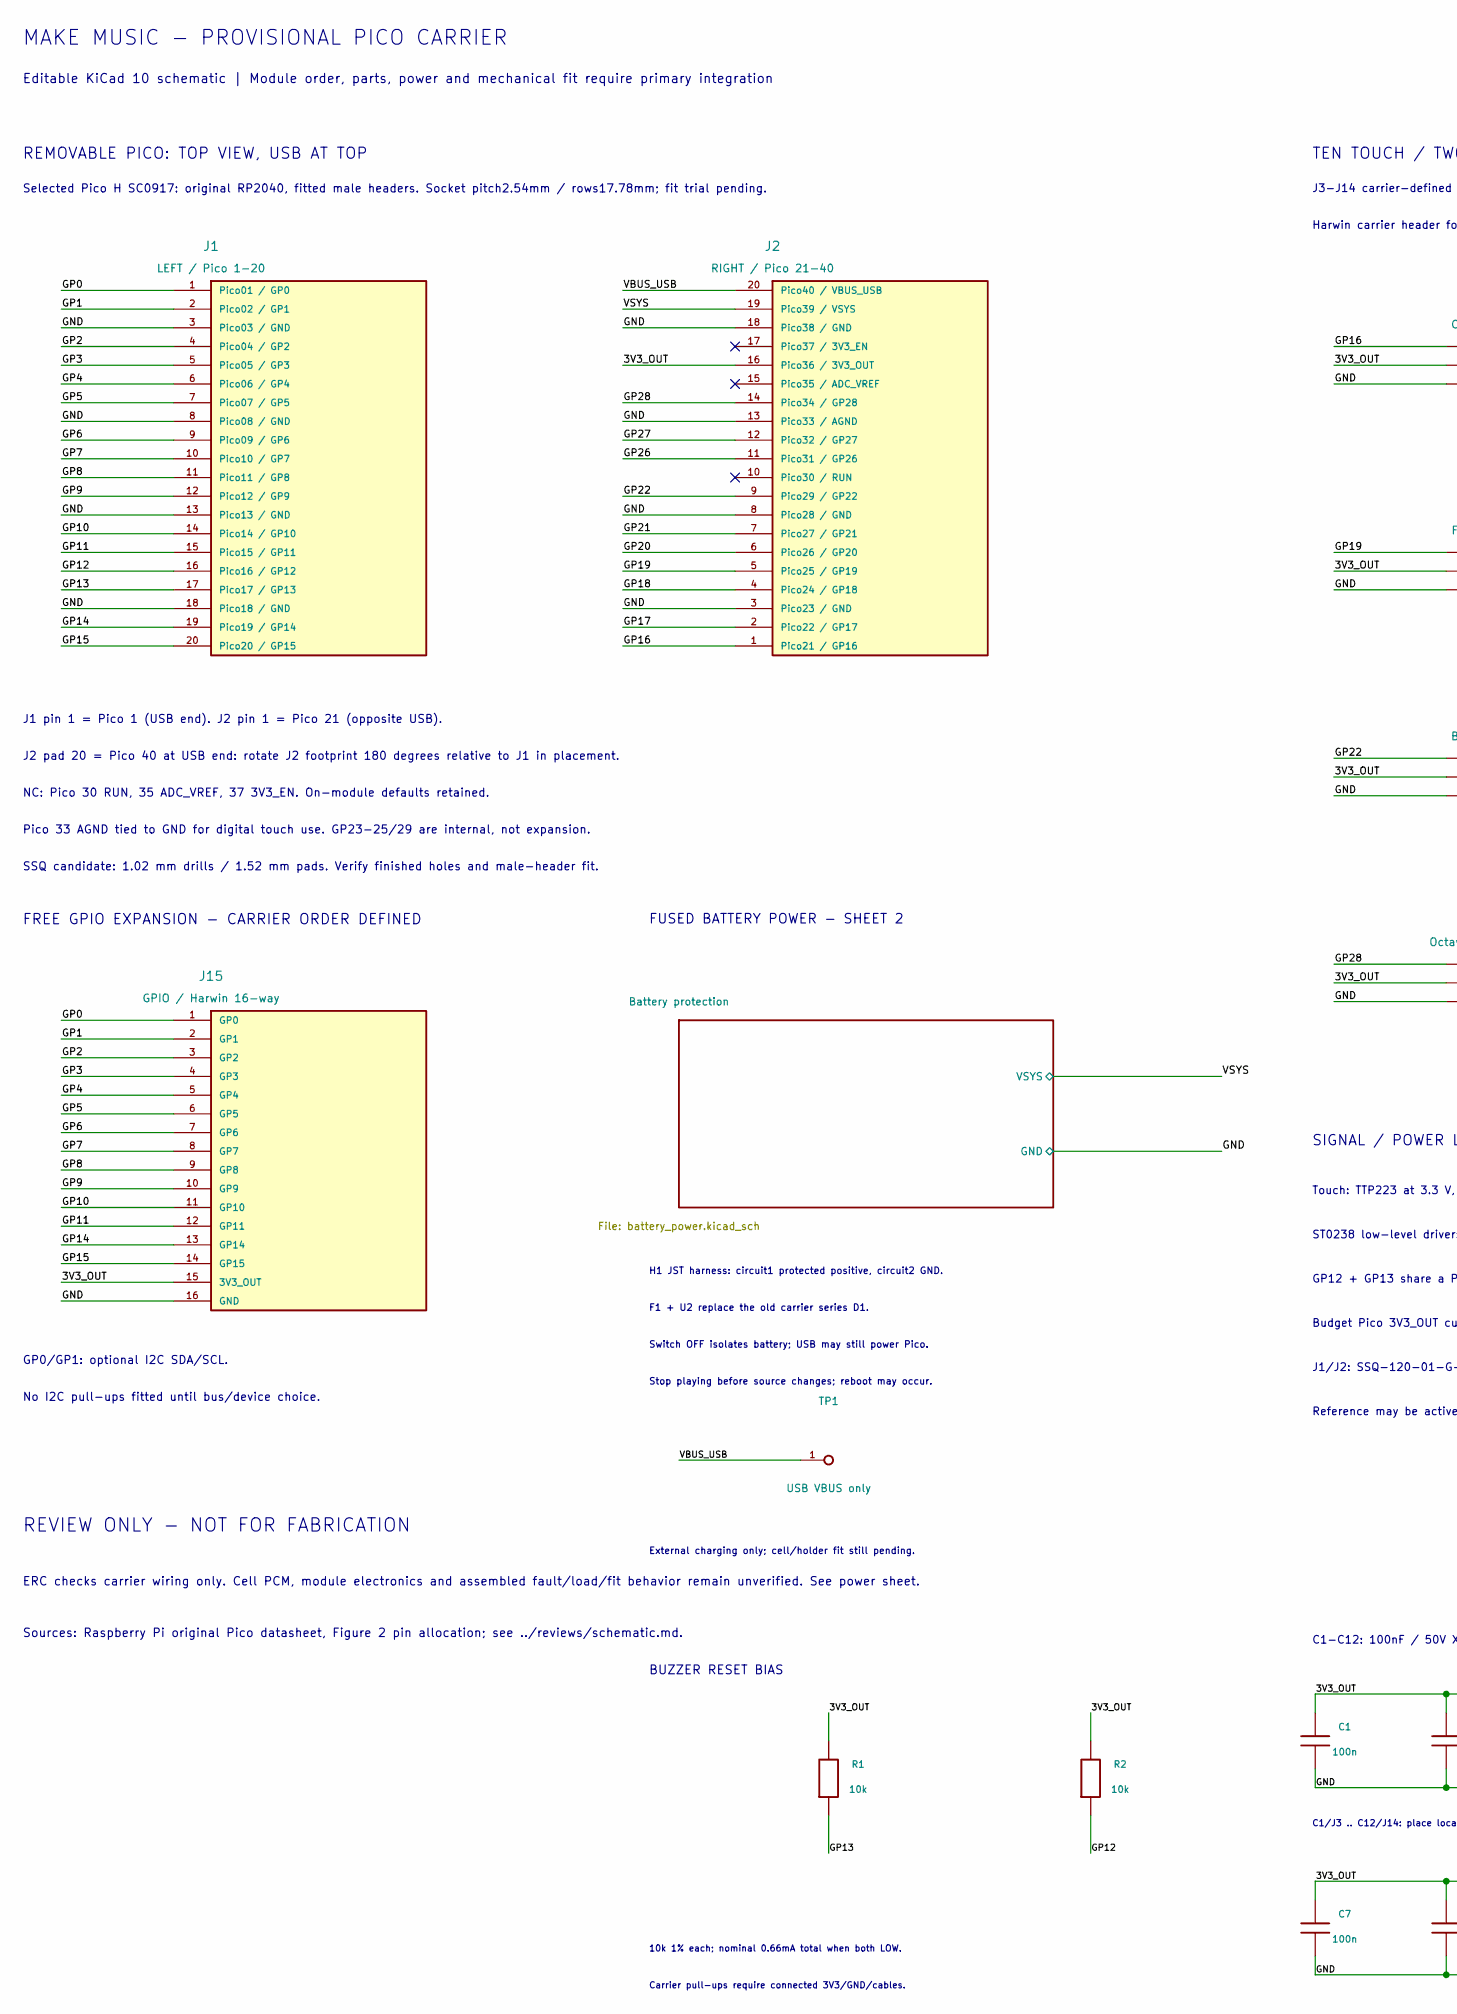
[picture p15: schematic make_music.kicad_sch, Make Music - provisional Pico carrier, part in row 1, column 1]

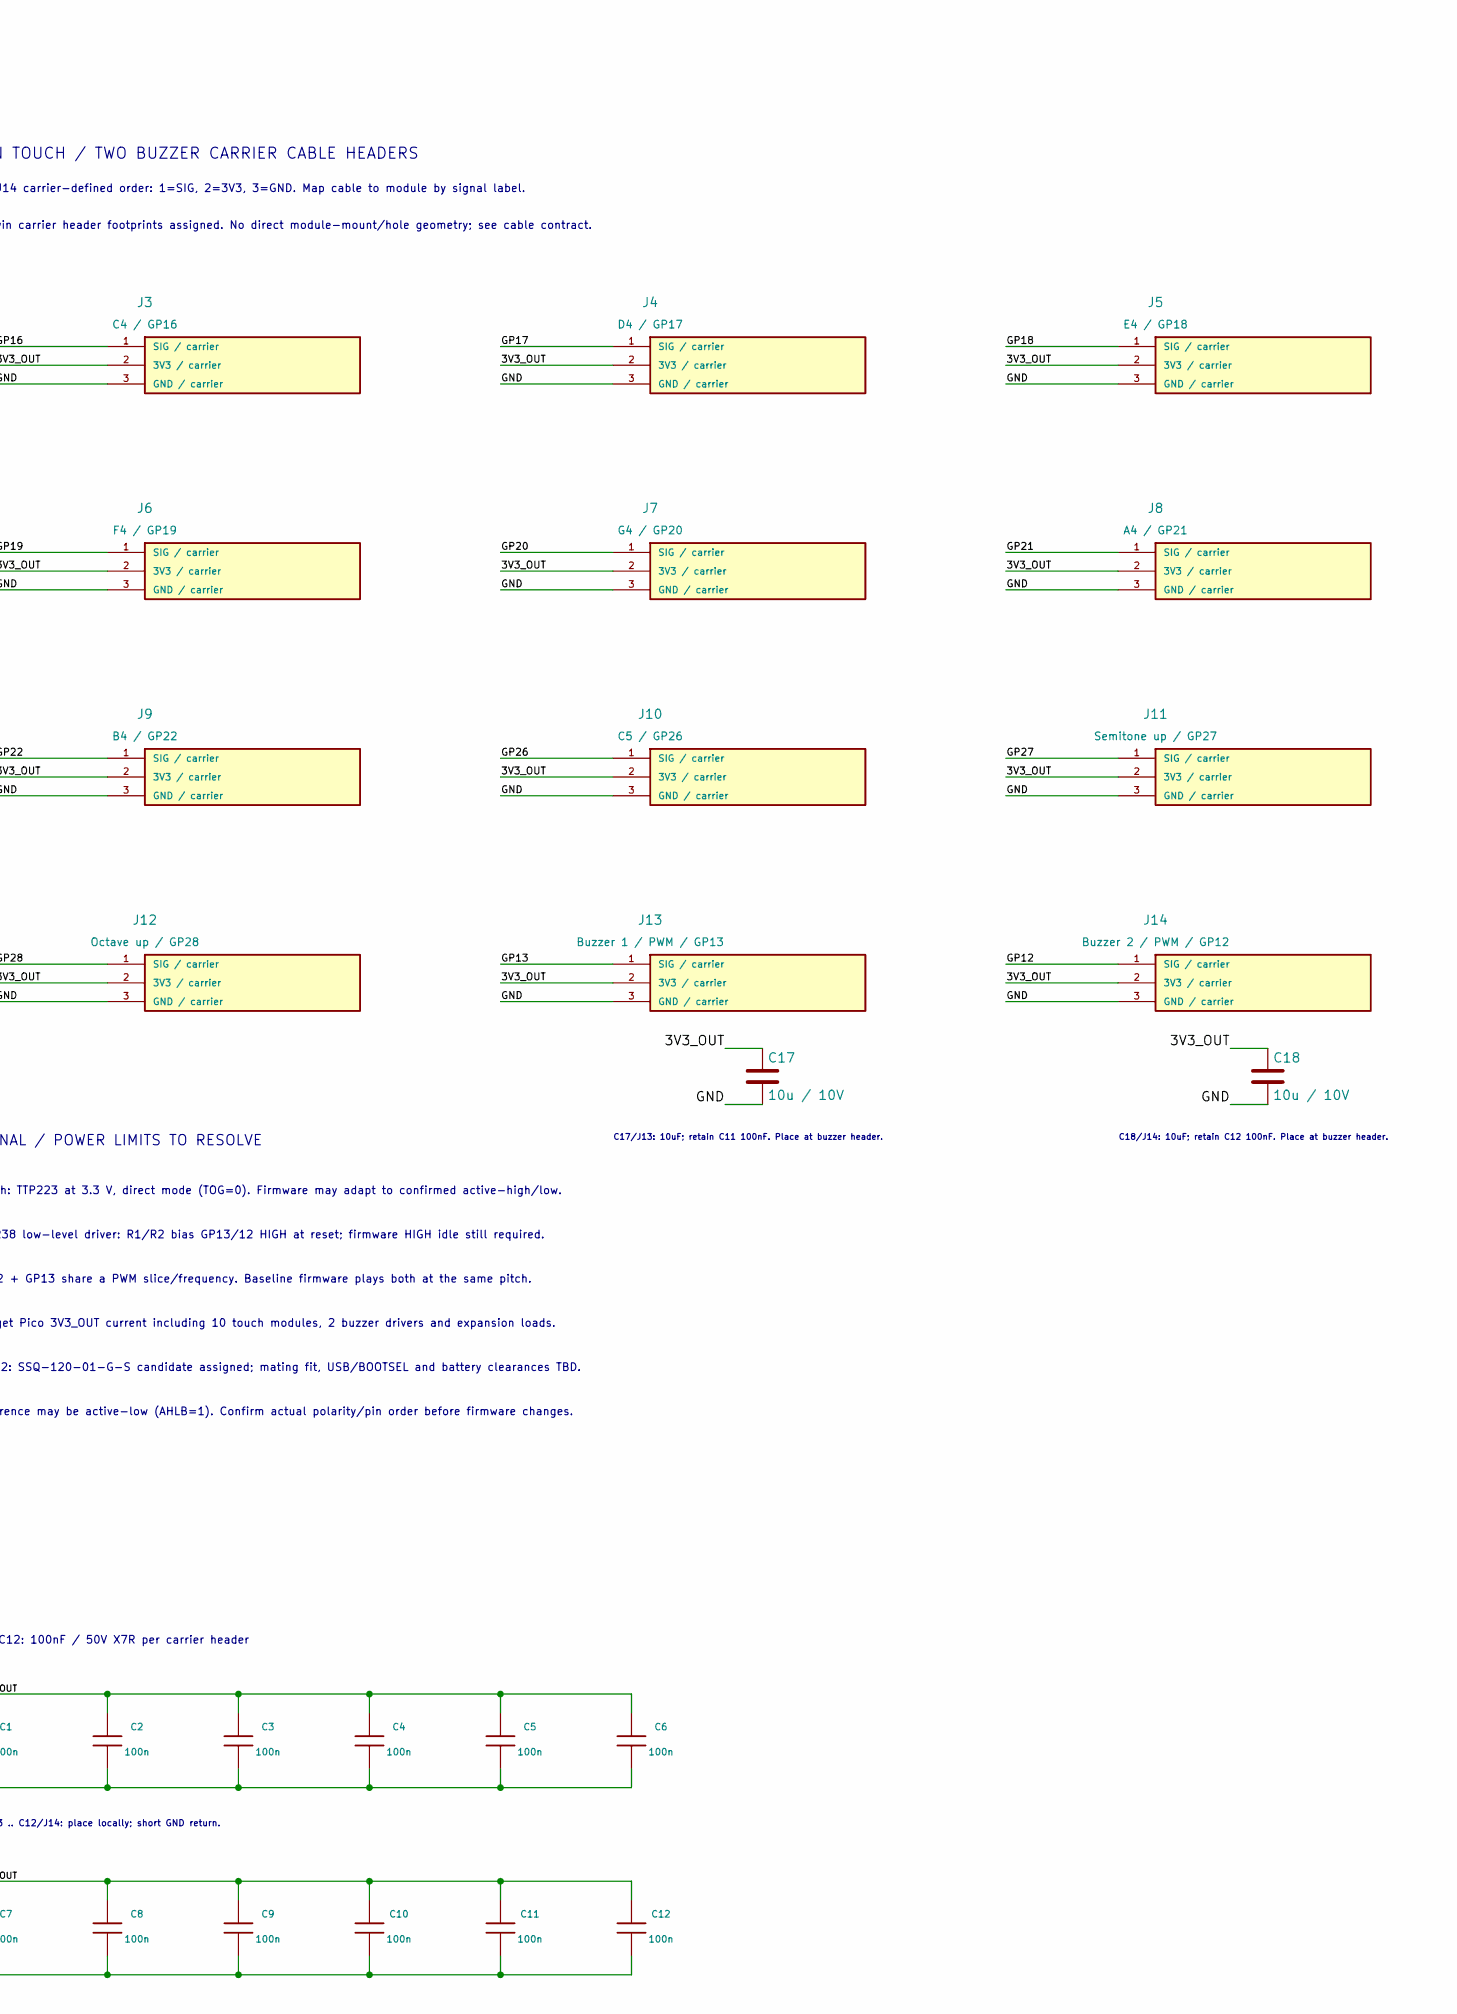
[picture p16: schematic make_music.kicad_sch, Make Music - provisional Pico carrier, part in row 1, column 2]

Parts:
C1, C2, C3, C4, C5, C6, C7, C8, C9, C10, C11, C12: 100n; KEMET_C0603_1608_LevelB; MPN C0603C104K5RACTU
C17, C18: 10u / 10V; C_0805_2012Metric; MPN C2012X7R1A106K125AC
J1: LEFT / Pico 1-20; Samtec_SSQ-120-01-G-S_1x20_P2.54mm; MPN SSQ-120-01-G-S
J2: RIGHT / Pico 21-40; Samtec_SSQ-120-01-G-S_1x20_P2.54mm; MPN SSQ-120-01-G-S
J3: C4 / GP16; Harwin_M20-9990346_1x3_P2.54mm; MPN M20-9990346
J4: D4 / GP17; Harwin_M20-9990346_1x3_P2.54mm; MPN M20-9990346
J5: E4 / GP18; Harwin_M20-9990346_1x3_P2.54mm; MPN M20-9990346
J6: F4 / GP19; Harwin_M20-9990346_1x3_P2.54mm; MPN M20-9990346
J7: G4 / GP20; Harwin_M20-9990346_1x3_P2.54mm; MPN M20-9990346
J8: A4 / GP21; Harwin_M20-9990346_1x3_P2.54mm; MPN M20-9990346
J9: B4 / GP22; Harwin_M20-9990346_1x3_P2.54mm; MPN M20-9990346
J10: C5 / GP26; Harwin_M20-9990346_1x3_P2.54mm; MPN M20-9990346
J11: Semitone up / GP27; Harwin_M20-9990346_1x3_P2.54mm; MPN M20-9990346
J12: Octave up / GP28; Harwin_M20-9990346_1x3_P2.54mm; MPN M20-9990346
J13: Buzzer 1 / PWM / GP13; Harwin_M20-9990346_1x3_P2.54mm; MPN M20-9990346
J14: Buzzer 2 / PWM / GP12; Harwin_M20-9990346_1x3_P2.54mm; MPN M20-9990346
J15: GPIO / Harwin 16-way; Harwin_M20-9991646_1x16_P2.54mm; MPN M20-9991646
R1, R2: 10k; R_0603_1608Metric; MPN RC0603FR-0710KL
TP1: USB VBUS only; TestPoint_Pad_D2.0mm

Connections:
/3V3_OUT: C1.1, C2.1, C3.1, C4.1, C5.1, C6.1, C7.1, C8.1, C9.1, C10.1, C11.1, C12.1, C17.1, C18.1, J2.16 (Pico36 / 3V3_OUT), J3.2 (3V3 / carrier), J4.2 (3V3 / carrier), J5.2 (3V3 / carrier), J6.2 (3V3 / carrier), J7.2 (3V3 / carrier), J8.2 (3V3 / carrier), J9.2 (3V3 / carrier), J10.2 (3V3 / carrier), J11.2 (3V3 / carrier), J12.2 (3V3 / carrier), J13.2 (3V3 / carrier), J14.2 (3V3 / carrier), J15.15 (3V3_OUT), R1.1, R2.1
/GND: C1.2, C2.2, C3.2, C4.2, C5.2, C6.2, C7.2, C8.2, C9.2, C10.2, C11.2, C12.2, C17.2, C18.2, J1.3 (Pico03 / GND), J1.8 (Pico08 / GND), J1.13 (Pico13 / GND), J1.18 (Pico18 / GND), J2.3 (Pico23 / GND), J2.8 (Pico28 / GND), J2.13 (Pico33 / AGND), J2.18 (Pico38 / GND), J3.3 (GND / carrier), J4.3 (GND / carrier), J5.3 (GND / carrier), J6.3 (GND / carrier), J7.3 (GND / carrier), J8.3 (GND / carrier), J9.3 (GND / carrier), J10.3 (GND / carrier), J11.3 (GND / carrier), J12.3 (GND / carrier), J13.3 (GND / carrier), J14.3 (GND / carrier), J15.16 (GND); also elsewhere on the board
/GP0: J1.1 (Pico01 / GP0), J15.1 (GP0)
/GP1: J1.2 (Pico02 / GP1), J15.2 (GP1)
/GP2: J1.4 (Pico04 / GP2), J15.3 (GP2)
/GP3: J1.5 (Pico05 / GP3), J15.4 (GP3)
/GP4: J1.6 (Pico06 / GP4), J15.5 (GP4)
/GP5: J1.7 (Pico07 / GP5), J15.6 (GP5)
/GP6: J1.9 (Pico09 / GP6), J15.7 (GP6)
/GP7: J1.10 (Pico10 / GP7), J15.8 (GP7)
/GP8: J1.11 (Pico11 / GP8), J15.9 (GP8)
/GP9: J1.12 (Pico12 / GP9), J15.10 (GP9)
/GP10: J1.14 (Pico14 / GP10), J15.11 (GP10)
/GP11: J1.15 (Pico15 / GP11), J15.12 (GP11)
/GP12: J1.16 (Pico16 / GP12), J14.1 (SIG / carrier), R2.2
/GP13: J1.17 (Pico17 / GP13), J13.1 (SIG / carrier), R1.2
/GP14: J1.19 (Pico19 / GP14), J15.13 (GP14)
/GP15: J1.20 (Pico20 / GP15), J15.14 (GP15)
/GP16: J2.1 (Pico21 / GP16), J3.1 (SIG / carrier)
/GP17: J2.2 (Pico22 / GP17), J4.1 (SIG / carrier)
/GP18: J2.4 (Pico24 / GP18), J5.1 (SIG / carrier)
/GP19: J2.5 (Pico25 / GP19), J6.1 (SIG / carrier)
/GP20: J2.6 (Pico26 / GP20), J7.1 (SIG / carrier)
/GP21: J2.7 (Pico27 / GP21), J8.1 (SIG / carrier)
/GP22: J2.9 (Pico29 / GP22), J9.1 (SIG / carrier)
/GP26: J2.11 (Pico31 / GP26), J10.1 (SIG / carrier)
/GP27: J2.12 (Pico32 / GP27), J11.1 (SIG / carrier)
/GP28: J2.14 (Pico34 / GP28), J12.1 (SIG / carrier)
/VBUS_USB: J2.20 (Pico40 / VBUS_USB), TP1.1
/VSYS: J2.19 (Pico39 / VSYS); also elsewhere on the board

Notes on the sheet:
MAKE MUSIC - PROVISIONAL PICO CARRIER
Editable KiCad 10 schematic | Module order, parts, power and mechanical fit require primary integration
REMOVABLE PICO: TOP VIEW, USB AT TOP
Selected Pico H SC0917: original RP2040, fitted male headers. Socket pitch2.54mm / rows17.78mm; fit trial pending.
J1 pin 1 = Pico 1 (USB end). J2 pin 1 = Pico 21 (opposite USB).
J2 pad 20 = Pico 40 at USB end: rotate J2 footprint 180 degrees relative to J1 in placement.
NC: Pico 30 RUN, 35 ADC_VREF, 37 3V3_EN. On-module defaults retained.
Pico 33 AGND tied to GND for digital touch use. GP23-25/29 are internal, not expansion.
FREE GPIO EXPANSION - CARRIER ORDER DEFINED
GP0/GP1: optional I2C SDA/SCL.
No I2C pull-ups fitted until bus/device choice.
TEN TOUCH / TWO BUZZER CARRIER CABLE HEADERS
J3-J14 carrier-defined order: 1=SIG, 2=3V3, 3=GND. Map cable to module by signal label.
Harwin carrier header footprints assigned. No direct module-mount/hole geometry; see cable contract.
SIGNAL / POWER LIMITS TO RESOLVE
Touch: TTP223 at 3.3 V, direct mode (TOG=0). Firmware may adapt to confirmed active-high/low.
ST0238 low-level driver: R1/R2 bias GP13/12 HIGH at reset; firmware HIGH idle still required.
GP12 + GP13 share a PWM slice/frequency. Baseline firmware plays both at the same pitch.
Budget Pico 3V3_OUT current including 10 touch modules, 2 buzzer drivers and expansion loads.
J1/J2: SSQ-120-01-G-S candidate assigned; mating fit, USB/BOOTSEL and battery clearances TBD.
REVIEW ONLY - NOT FOR FABRICATION
ERC checks carrier wiring only. Cell PCM, module electronics and assembled fault/load/fit behavior remain unverified. See power sheet.
Sources: Raspberry Pi original Pico datasheet, Figure 2 pin allocation; see ../reviews/schematic.md.
Reference may be active-low (AHLB=1). Confirm actual polarity/pin order before firmware changes.
SSQ candidate: 1.02 mm drills / 1.52 mm pads. Verify finished holes and male-header fit.
BUZZER RESET BIAS
10k 1% each; nominal 0.66mA total when both LOW.
Carrier pull-ups require connected 3V3/GND/cables.
C1-C12: 100nF / 50V X7R per carrier header
C1/J3 .. C12/J14: place locally; short GND return.
FUSED BATTERY POWER - SHEET 2
H1 JST harness: circuit1 protected positive, circuit2 GND.
F1 + U2 replace the old carrier series D1.
Switch OFF isolates battery; USB may still power Pico.
Stop playing before source changes; reboot may occur.
External charging only; cell/holder fit still pending.
C17/J13: 10uF; retain C11 100nF. Place at buzzer header.
C18/J14: 10uF; retain C12 100nF. Place at buzzer header.

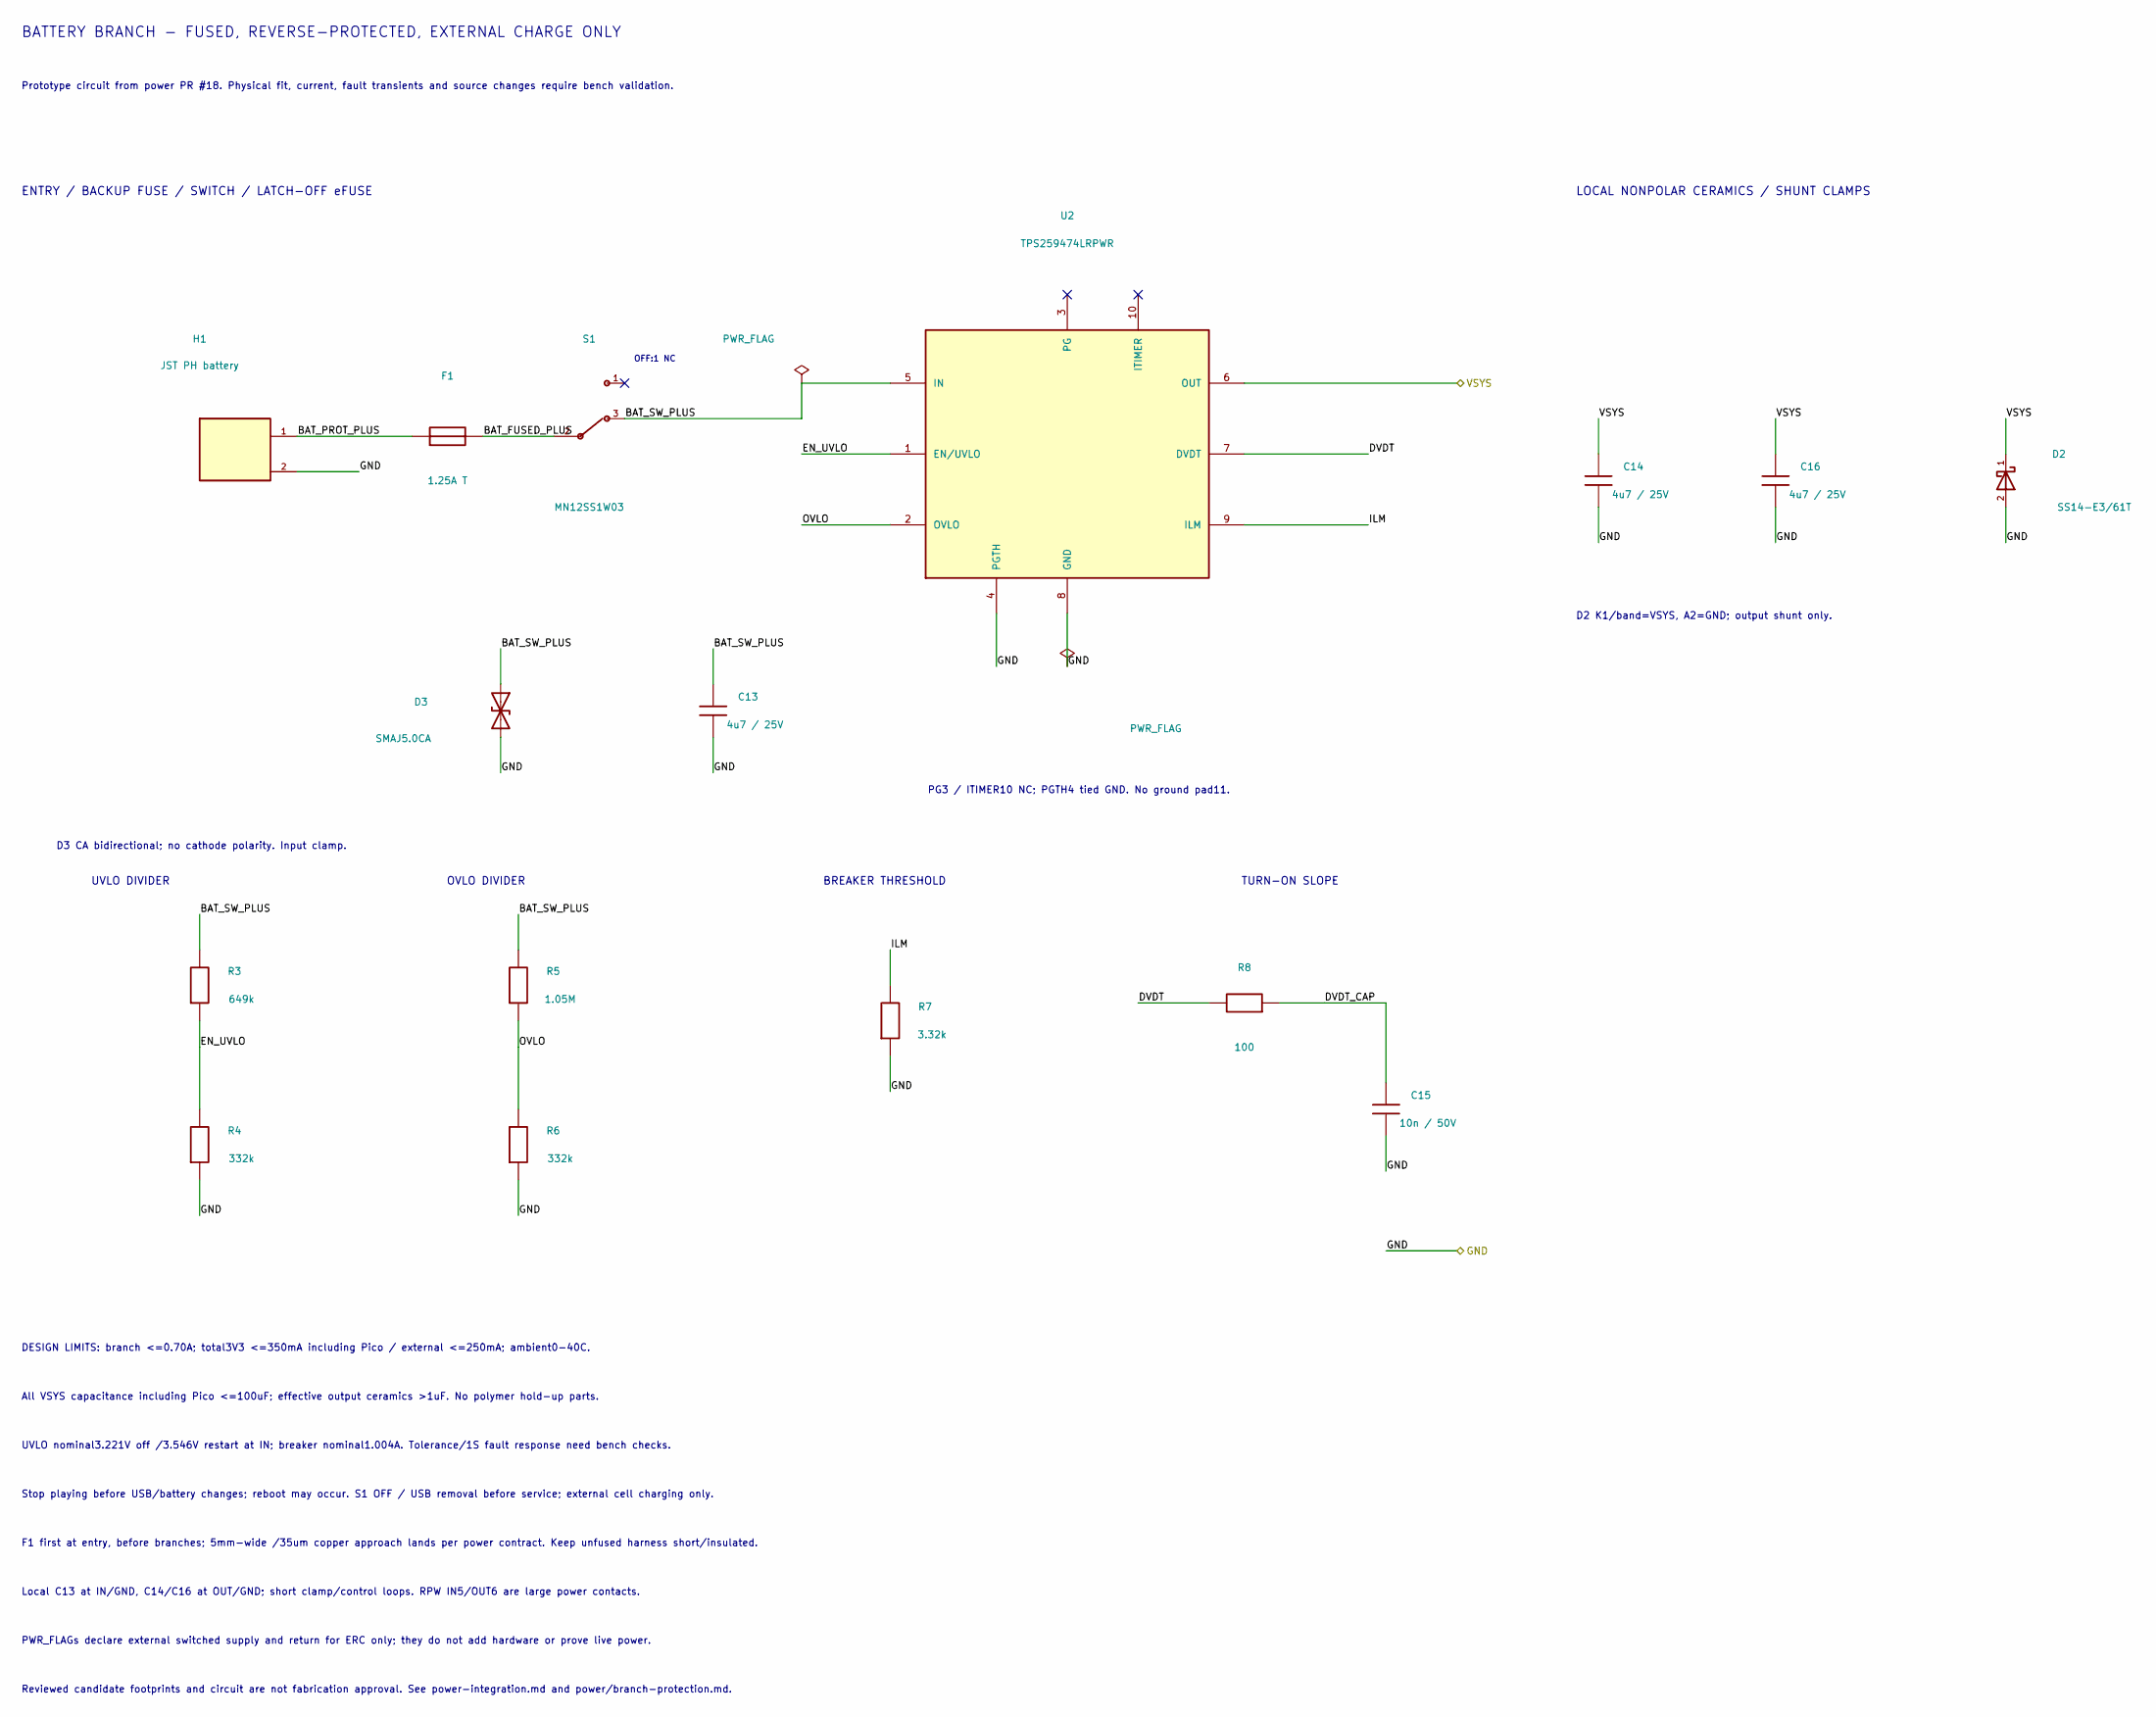
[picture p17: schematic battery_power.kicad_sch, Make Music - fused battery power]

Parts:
C13, C14, C16: 4u7 / 25V; C_0805_2012Metric; MPN C2012X7R1E475K125AB
C15: 10n / 50V; C_0603_1608Metric; MPN C1608C0G1H103J080AA
D2: SS14-E3/61T; Vishay_SS14_SMA_K1_A2; MPN SS14-E3/61T
D3: SMAJ5.0CA; Littelfuse_SMAJ5-0CA_DO-214AC; MPN SMAJ5.0CA
F1: 1.25A T; Schurter_UMT-H_3403-0275-23; MPN 3403.0275.23
H1: JST PH battery; JST_PH_B2B-PH-K_1x02_P2.00mm_Vertical; MPN B2B-PH-K-S(LF)(SN)
R3: 649k; R_0603_1608Metric; MPN RC0603FR-07649KL
R4, R6: 332k; R_0603_1608Metric; MPN RC0603FR-07332KL
R5: 1.05M; R_0603_1608Metric; MPN RC0603FR-071M05L
R7: 3.32k; R_0603_1608Metric; MPN RC0603FR-073K32L
R8: 100; R_0603_1608Metric; MPN RC0603FR-07100RL
S1: MN12SS1W03; NKK_MN12SS1W03_TerminalPattern_Candidate; MPN MN12SS1W03
U2: TPS259474LRPWR; TI_RPW0010A_TPS259474_2x2mm; MPN TPS259474LRPWR

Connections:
/Battery protection/BAT_FUSED_PLUS: F1.2, S1.2 (COM)
/Battery protection/BAT_PROT_PLUS: F1.1, H1.1 (PROTECTED_PLUS)
/Battery protection/BAT_SW_PLUS: C13.1, D3.1 (A1), R3.1, R5.1, S1.3 (BAT_ON), U2.5 (IN)
/Battery protection/DVDT: R8.1, U2.7 (DVDT)
/Battery protection/DVDT_CAP: C15.1, R8.2
/Battery protection/EN_UVLO: R3.2, R4.1, U2.1 (EN/UVLO)
/Battery protection/ILM: R7.1, U2.9 (ILM)
/Battery protection/OVLO: R5.2, R6.1, U2.2 (OVLO)
/GND: C13.2, C14.2, C15.2, C16.2, D2.2 (A), D3.2 (A2), H1.2 (PROTECTED_MINUS), R4.2, R6.2, R7.2, U2.4 (PGTH), U2.8 (GND); also elsewhere on the board
/VSYS: C14.1, C16.1, D2.1 (K), U2.6 (OUT); also elsewhere on the board

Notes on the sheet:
BATTERY BRANCH - FUSED, REVERSE-PROTECTED, EXTERNAL CHARGE ONLY
Prototype circuit from power PR #18. Physical fit, current, fault transients and source changes require bench validation.
ENTRY / BACKUP FUSE / SWITCH / LATCH-OFF eFUSE
OFF:1 NC
PG3 / ITIMER10 NC; PGTH4 tied GND. No ground pad11.
LOCAL NONPOLAR CERAMICS / SHUNT CLAMPS
D2 K1/band=VSYS, A2=GND; output shunt only.
D3 CA bidirectional; no cathode polarity. Input clamp.
UVLO DIVIDER
OVLO DIVIDER
BREAKER THRESHOLD
TURN-ON SLOPE
DESIGN LIMITS: branch <=0.70A; total3V3 <=350mA including Pico / external <=250mA; ambient0-40C.
All VSYS capacitance including Pico <=100uF; effective output ceramics >1uF. No polymer hold-up parts.
UVLO nominal3.221V off /3.546V restart at IN; breaker nominal1.004A. Tolerance/1S fault response need bench checks.
Stop playing before USB/battery changes; reboot may occur. S1 OFF / USB removal before service; external cell charging only.
F1 first at entry, before branches; 5mm-wide /35um copper approach lands per power contract. Keep unfused harness short/insulated.
Local C13 at IN/GND, C14/C16 at OUT/GND; short clamp/control loops. RPW IN5/OUT6 are large power contacts.
PWR_FLAGs declare external switched supply and return for ERC only; they do not add hardware or prove live power.
Reviewed candidate footprints and circuit are not fabrication approval. See power-integration.md and power/branch-protection.md.

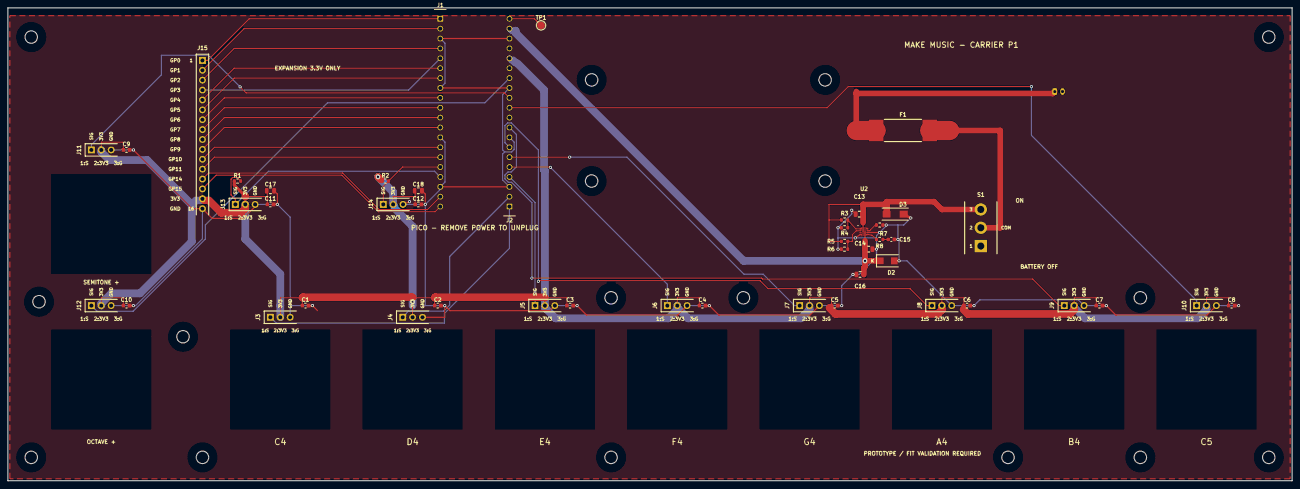
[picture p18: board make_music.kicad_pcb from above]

Board: 2 copper layers, 330.0 x 121.5 mm, 65 parts (1 on the bottom side), 38 nets.

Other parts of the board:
MH1, MH2, MH3, MH4, MH5, MH6, MH7, MH8, MH9, MH10, MH11, MH12, MH13, MH14, MH15, MH16, MH17: MountingHole_3.2mm_M3

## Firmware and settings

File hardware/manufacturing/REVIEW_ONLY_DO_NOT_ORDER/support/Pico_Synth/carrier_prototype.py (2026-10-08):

"""MicroPython firmware for the first Make Music carrier prototype.

Confirm touch polarity on the actual modules before installing as main.py.
ST0238 buzzer inputs are active-low: silence is a constant HIGH output.
"""

NOTE_PINS = (16, 17, 18, 19, 20, 21, 22, 26)
NOTE_HZ = (261.63, 293.66, 329.63, 349.23, 392.00, 440.00, 493.88, 523.25)
SEMITONE_PIN = 27
OCTAVE_PIN = 28
BUZZER_PINS = (13, 12)  # Shared PWM slice: both play the same note.

# The supplied TTP223 reference ties AHLB high (active-low). Set each entry to
# 1 for a module verified active-high; no rewiring of GPIO assignments needed.
TOUCH_ACTIVE_LEVELS = {pin: 0 for pin in NOTE_PINS + (SEMITONE_PIN, OCTAVE_PIN)}
BUZZER_ACTIVE_LOW = True


class CarrierSynth:
    def __init__(self, machine, active_levels=None, buzzer_active_low=True):
        self.machine = machine
        self.levels = dict(TOUCH_ACTIVE_LEVELS if active_levels is None else active_levels)
        required = NOTE_PINS + (SEMITONE_PIN, OCTAVE_PIN)
        if set(self.levels) != set(required) or any(v not in (0, 1) for v in self.levels.values()):
            raise ValueError('Specify a 0 or 1 active level for all ten touch inputs')
        self.idle = 1 if buzzer_active_low else 0
        self.silent_duty = 65535 if self.idle else 0
        # Establish silence as ordinary digital outputs before selecting PWM.
        self.output_pins = [machine.Pin(pin, machine.Pin.OUT, value=self.idle)
                            for pin in BUZZER_PINS]
        self.buzzers = [machine.PWM(pin, freq=440, duty_u16=self.silent_duty)
                       for pin in self.output_pins]
        self.inputs = {pin: machine.Pin(pin, machine.Pin.IN,
                       machine.Pin.PULL_UP if self.levels[pin] == 0 else machine.Pin.PULL_DOWN)
                       for pin in required}
        self.last_frequency = None

    def pressed(self, pin):
        return self.inputs[pin].value() == self.levels[pin]

    def scan(self):
        # Retain original first-note priority when multiple notes are touched.
        frequency = None
        for pin, base_hz in zip(NOTE_PINS, NOTE_HZ):
            if self.pressed(pin):
                frequency = base_hz
                if self.pressed(SEMITONE_PIN):
                    frequency *= 2 ** (1 / 12)
                if self.pressed(OCTAVE_PIN):
                    frequency *= 2
                frequency = round(frequency)
                break
        if frequency != self.last_frequency:
            if frequency is None:
                for buzzer in self.buzzers:
                    buzzer.duty_u16(self.silent_duty)
            else:
                # Changing one slice frequency affects both channels; write
                # the same value to both and then enable their 50% duty outputs.
                for buzzer in self.buzzers:
                    buzzer.freq(frequency)
                    buzzer.duty_u16(32768)
            self.last_frequency = frequency
        return frequency

    def close(self):
        for buzzer in self.buzzers:
            buzzer.duty_u16(self.silent_duty)
            buzzer.deinit()
        # deinit alone does not establish a driven idle voltage.
        for pin in self.output_pins:
            pin.init(self.machine.Pin.OUT, value=self.idle)


def main():
    import machine
    from time import sleep_ms

    synth = CarrierSynth(machine, TOUCH_ACTIVE_LEVELS, BUZZER_ACTIVE_LOW)
    try:
        sleep_ms(600)  # TTP223's documented power-up settling interval is ~500 ms.
        while True:
            synth.scan()
            sleep_ms(10)
    finally:
        synth.close()


if __name__ == '__main__':
    main()

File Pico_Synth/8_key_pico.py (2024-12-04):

from machine import Pin, PWM
from time import sleep

# Define the buzzer pins
buzzer1 = PWM(Pin(13))  # Buzzer 1 on GPIO 13
buzzer2 = PWM(Pin(12))  # Buzzer 2 on GPIO 12

# Define a dictionary of notes and their frequencies within the octave C4 to C5
notes = {
    16: 261.63,  # C4
    17: 293.66,  # D4
    18: 329.63,  # E4
    19: 349.23,  # F4
    20: 392.00,  # G4
    21: 440.00,  # A4
    22: 493.88,  # B4
    26: 523.25   # C5
}

# Setup touch keys with the corresponding GPIO pins
keys = {
    16: Pin(16, Pin.IN, Pin.PULL_DOWN),
    17: Pin(17, Pin.IN, Pin.PULL_DOWN),
    18: Pin(18, Pin.IN, Pin.PULL_DOWN),
    19: Pin(19, Pin.IN, Pin.PULL_DOWN),
    20: Pin(20, Pin.IN, Pin.PULL_DOWN),
    21: Pin(21, Pin.IN, Pin.PULL_DOWN),
    22: Pin(22, Pin.IN, Pin.PULL_DOWN),
    26: Pin(26, Pin.IN, Pin.PULL_DOWN)
}

def play_tone(buzzer1, buzzer2, frequency):
    buzzer1.freq(int(frequency))
    buzzer2.freq(int(frequency))
    buzzer1.duty_u16(32768)  # 50% duty cycle
    buzzer2.duty_u16(32768)  # 50% duty cycle

def stop_tone(buzzer1, buzzer2):
    buzzer1.duty_u16(0)  # Turn off the buzzer
    buzzer2.duty_u16(0)  # Turn off the buzzer

while True:
    key_pressed = False
    for pin, key in keys.items():
        if key.value() == 1:
            print(f"Key pressed: {pin}, Note: {notes[pin]}")
            play_tone(buzzer1, buzzer2, notes[pin])
            key_pressed = True
            break
        else:
            print(f"Key {pin} not pressed")
    if not key_pressed:
        stop_tone(buzzer1, buzzer2)
    sleep(0.01)  # Small delay to prevent CPU overload

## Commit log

2026-10-08 Establish Pico instrument PCB requirements and helper scopes (#1)
2026-10-08 Add editable provisional Pico carrier schematic and connectivity review
    [make_music.kicad_sch, pico-socket-map.csv]
2026-10-08 Document Pico socket geometry and underside 18350 fit proposal (#3)
2026-10-08 Add editable provisional Pico carrier schematic and connectivity review (#4)
    [make_music.kicad_sch, pico-socket-map.csv]
2026-10-08 Propose protected battery and isolated USB power options (#5)
2026-10-08 Assign candidate Pico socket footprints and document placement orientation
    [make_music.kicad_sch]
2026-10-08 Record prototype spacing and factory assembly preferences (#6)
2026-10-08 Assign candidate Pico socket footprints and placement orientation (#7)
    * Add editable provisional Pico carrier schematic and connectivity review
    * Assign candidate Pico socket footprints and document placement orientation
    ---------
    [make_music.kicad_sch]
2026-10-08 Widen note spacing and reconcile right Pico socket placement (#8)
    * Document Pico socket geometry and underside 18350 fit proposal
    * Widen key spacing and align socket placement with schematic
    * Reflect integrated local footprint registration
    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
    [socket-placement.csv]
2026-10-08 Compare protected battery costs and strengthen power-switch proposal (#9)
    * Propose protected battery and isolated USB power options
    * Compare protected battery costs and propose a stronger power switch
    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
2026-10-08 Record SunFounder ST0238 buzzer selection for prototype (#10)
2026-10-08 Select protected 18350 and external charging for revision one (#11)
2026-10-08 Power: specify rev1 protected 18350 targets and integration handoff (#12)
    * Document exact rev1 battery targets and power integration contract
    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
2026-10-08 Correct 18350 holder drawing review and reserve selected buzzer bodies (#13)
    * Add drawing-backed 1095P holder candidate and buzzer reservations
    * Withdraw incorrect holder footprint and correct five-hole drawing review
    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
2026-10-08 Integrate externally charged protected battery switch and isolation circuit
    [make_music.kicad_sch]
2026-10-08 Record withdrawn holder footprint and keep battery terminals provisional
2026-10-08 Integrate revision-one battery switch and VSYS isolation schematic (#14)
    * Integrate externally charged protected battery switch and isolation circuit
    * Record withdrawn holder footprint and keep battery terminals provisional
    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
    [make_music.kicad_sch]
2026-10-08 Start native PCB with mapped Pico socket placement (#15)
    [make_music.kicad_pcb]
2026-10-08 Add carrier firmware for active-low buzzers and configurable touch inputs (#16)
    [carrier_prototype.py]
2026-10-08 Specify wired 18350 cassette and verified carrier interface (#17)
    * Specify wired 18350 cassette and verified PH carrier interface
    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
2026-10-08 Define carrier cable headers, battery harness and buzzer reset bias
    [make_music.kicad_sch]
2026-10-08 Record merged wired holder architecture reference
2026-10-08 Define carrier connectors and add buzzer reset bias and bypass (#19)
    * Define carrier cable headers, battery harness and buzzer reset bias
    * Record merged wired holder architecture reference
    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
    [make_music.kicad_sch]
2026-10-08 Power: specify fused reverse-protected eFuse branch and low-battery cutoff (#18)
    * Specify fused eFuse battery branch and hardware low-battery policy
    * Remove default hold-up capacitors and document source-change resets
    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
    [branch-endpoints.csv]
2026-10-08 Power: add factory assembly and staged prototype validation (#21)
    * Document factory power assembly and staged prototype validation
    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
2026-10-08 Propose module fixture with independent mounts and diagonal keepers (#22)
    [fixture-mounting.csv]
2026-10-08 Integrate fused TPS259474L battery protection into native schematic
    [battery_power.kicad_sch, make_music.kicad_sch]
2026-10-08 Link staged assembly and fault-reset qualification
2026-10-08 Integrate fused TPS259474L power branch and native footprints (#23)
    * Integrate fused TPS259474L battery protection into native schematic
    * Link staged assembly and fault-reset qualification
    ---------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
    [battery_power.kicad_sch, make_music.kicad_sch]
2026-10-08 Route protected Pico music carrier and prepare held review files (#20)
    * Place carrier components and define module cable assembly
    * Route protected carrier and integrate module fixture mounts
    * Prepare checked review exports and exact assembly handoff
    * Apply final mechanical review and refresh held outputs
    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
    [carrier-bom.csv, carrier-positions.csv, instrument-parts.csv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]
2026-10-09 Record independent held-package schematic review
2026-10-09 Audit power and mixed assembly readiness for five instruments
2026-10-09 Add buzzer bulk bypass and native socket purchasing fields
    [make_music.kicad_sch]
2026-10-09 Correct note connector clearance and preserve PCB build checkpoint
    [make_music.kicad_pcb]
2026-10-09 Correct active power specification to protected 18650
2026-10-09 Correct mechanical battery plan to protected removable 18650
    [cassette-18650-geometry.csv]
2026-10-09 Move battery interface for 18650 and define five complete assemblies
    [instrument-parts.csv, make_music.kicad_pcb]
2026-10-09 Route buzzer bulk capacitors and verify live PCB integration
    [make_music.kicad_pcb]
2026-10-09 Align protected 18650 power handoff with MPD factory leads (#31)
    * Align power handoff with MPD protected 18650 holder
    * Reconcile power handoff with final root integration review
    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
    [instrument-parts-handoff.csv]
2026-10-09 Reject mismatched assembly positions and rotations before packaging (#33)
    * Verify all exported assembly placements against live inventory
    * Require confirmed rear edge at native y18.5 for held exports
    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
2026-10-09 Clear rear socket markers and verify final 18650 carrier outline
    [instrument-parts.csv, make_music.kicad_pcb]
2026-10-09 Document supported rear socket edge and cassette interface CAD (#34)
    * Document rear socket correction and parametric cassette interfaces
    * Update actual-scale Letter paper fit for rear extension
    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
    [cassette-backplate-review.dxf, cassette-platform-review.dxf]
2026-10-09 Normalize complete instrument parts CSV line endings
    [instrument-parts.csv]
2026-10-09 Publish source-bound held PCBWay review package and visual evidence
    [carrier-bom.csv, carrier-positions.csv, instrument-parts.csv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]
2026-10-09 Checkpoint held PCB package at five-hour usage guard
2026-10-09 Record early wake and defer PCB review until actual usage reset
2026-10-09 Align power handoff with final held export review
2026-10-09 Complete self-contained held assembly quote package and final audit
    [branch-endpoints.csv, cassette-18650-geometry.csv, cassette-backplate-review.dxf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]
2026-10-09 Record merged held prototype and paused continuation
2026-10-10 Prepare reviewed conditional PCBWay quotation handoff
2026-10-10 Record confirmed PCBWay quote-only RFQ receipt
2026-10-13 Group carrier BOM by part number in PCBWay Excel template
2026-10-16 Supply factory wiring, programming and acceptance-test inputs (#43)
    * Supply factory wiring, programming and test handoff
    * Record sent factory-input reply and remaining qualification issue
2026-10-18 Record actual PCBWay factory-file attachment delivery (#50)
2026-10-19 Provide supplier cable connection drawings for quotation (#52)
    * Add supplier cable connection drawings with explicit fit holds
    * Record cable PDF attachment delivery and supplier fit request
